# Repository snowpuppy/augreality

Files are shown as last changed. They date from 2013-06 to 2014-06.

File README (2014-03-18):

Aug Reality Cornell Cup Project ==
==================================

INTRODUCTION =
==============
This project aims to build an augmented reality simulator device
using a headset and the Intel DE2-i150 development board for the Cornell Cup
Competition. The headset is a custom design which has 3d graphics,
head tracking, gps positioning, and a wide field of view.
This is phase2 of the project. Documentation for phase1 and phase2 can be found
in our doc/ folder. The headset src/ folder is subdivided into all of the software
modules for this project.

DIRECTORY STRUCTURE =
=====================

## headset
##########

$$ headset/src
    This directory contains all source code for the Headset.

$$ headset/test
    This directory contains all test code for the headset (usually proof of concept or simulation code.)

$$ headset/doc
    This directory contains specific documentation related to the headset.

## doc
######
  This directory contains all general documenation for the top level design.

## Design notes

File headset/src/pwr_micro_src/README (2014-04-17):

This project contains the Cornell Cup headset power PCB code. It uses the STM32L100 series
microcontroller to establish an ultra-low-power method of correcting and reporting fuel gauge
data to the Intel Atom board.

You will need to install the STM32 ST-Link utility to enable "make upload" to autonomously
program the board through an ST-LINK dongle and SWD. Create a file named "stlink.mk" with the
only line being:

STLINK=C:/Program\ Files\ (x86)/STMicroelectronics/ST-LINK\ Utility

changed to match where the utility was actually installed on the local computer. Alternatively,
the ST-LINK GUI can be used instead, but note that the binary is only loaded when re-selected!

The "libSTMCore.a" is the STM32L Standard Peripherals Library pre-compiled for this chip
(STM32L1XX_MD), while "libSTMUSB.a" is the STM32 USB CDC-ACM example pre-compiled for this chip.

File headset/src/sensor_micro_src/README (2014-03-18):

This project contains the Cornell Cup headset sensor PCB code. It is a derivative of the Senior
Design micro_src code, with the XBee and fuel gauge completely removed.

You will need to have dfu-util 0.5 or later (http://dfu-util.gnumonks.org/releases/) installed
on your PATH (put it in the yagarto bin directory to make sure).

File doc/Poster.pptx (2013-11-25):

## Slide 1

ECE 477 Digital Systems Senior Design Project - Fall 2013

Team 5 – Augmented Reality Simulator

Project Overview:
- Players don the headset to experience an immersive multiplayer augmented reality Pacman-like game
- The semi-transparent display integrates game objects with the real world
- Wireless multiplayer is facilitated by a central control unit
- Gameplay is based on geospatial data from GPS and head orientation from an IMU

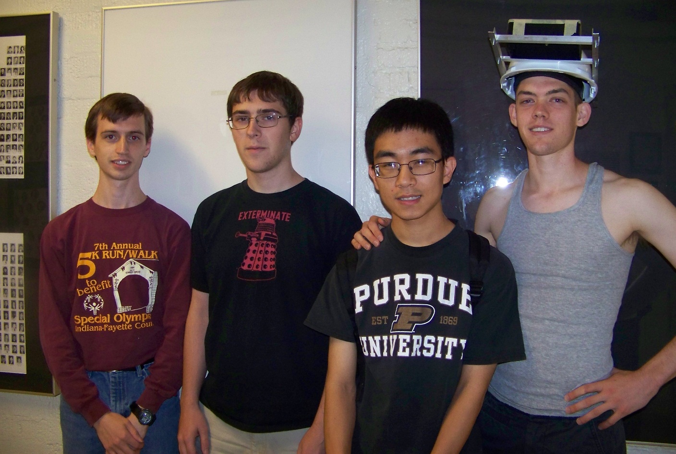
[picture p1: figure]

Team Members: Thor Smith, Steven Ellis,
Stephen Carlson, Alec Stephen Green

Packaging
- Semi-transparent display using an acrylic sheet with reflective film
- Fresnel lens increases field of view and focusing distance
- Aluminum and plastic construction allows for a lightweight yet rigid frame

PCB Layout
- Multiple power supplies reduce noise coupling for better sensor performance
- Size and form factor designed to fit with Raspberry PI motherboard
- Uses STM32F4 microcontroller with FPU.
- Battery sensing and charging, GPS, wireless radio, and 9-degree of freedom inertial measurement

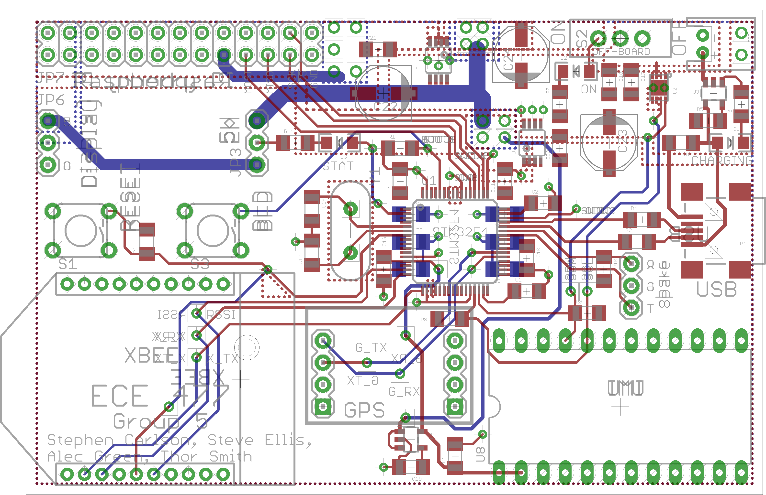
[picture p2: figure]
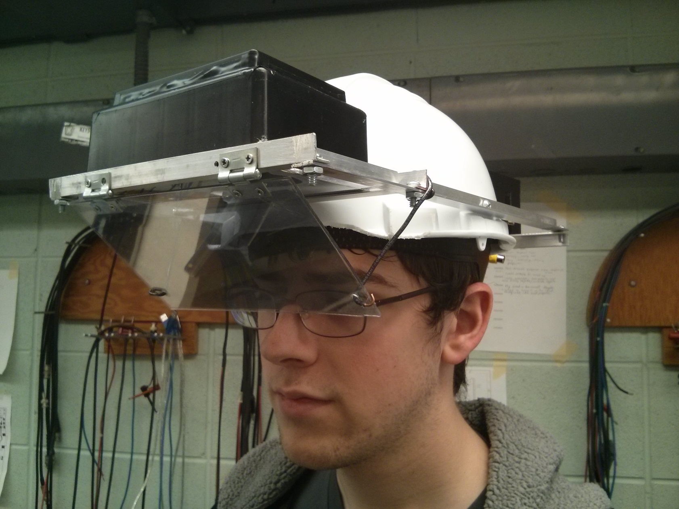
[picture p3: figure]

Digijock(ette)-Strength Digital System DesignTM
Transforming Ideas Into Reality

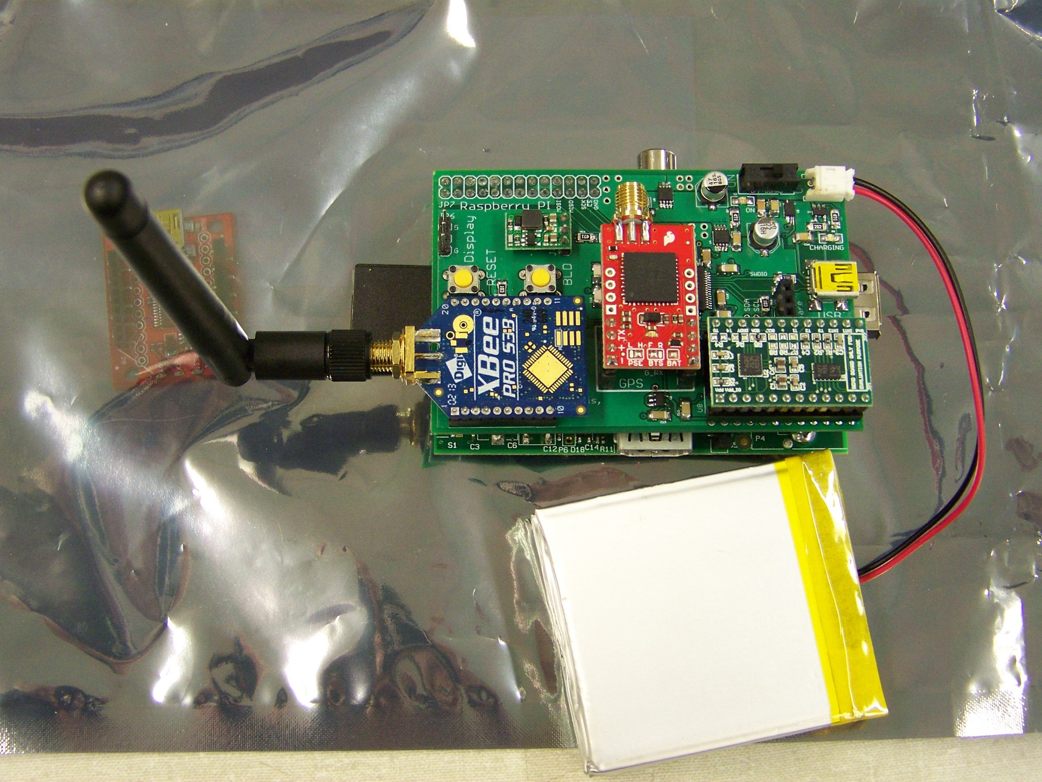
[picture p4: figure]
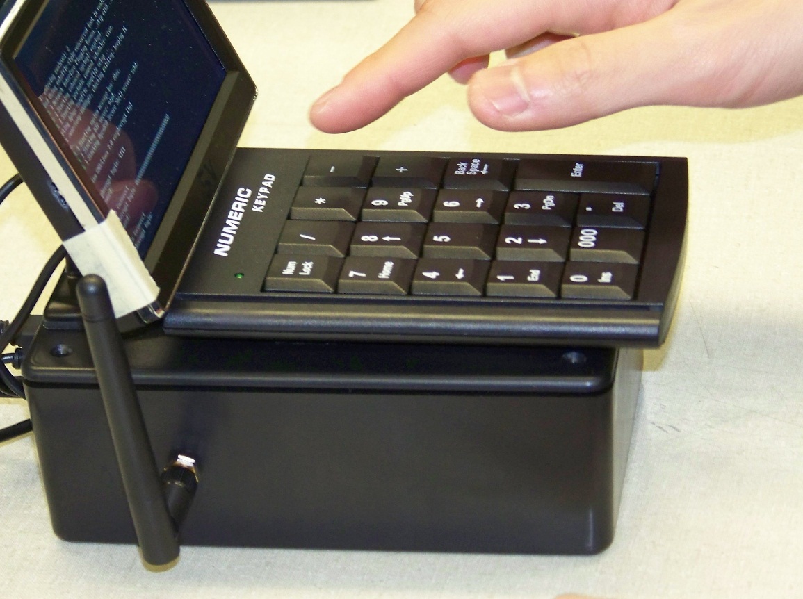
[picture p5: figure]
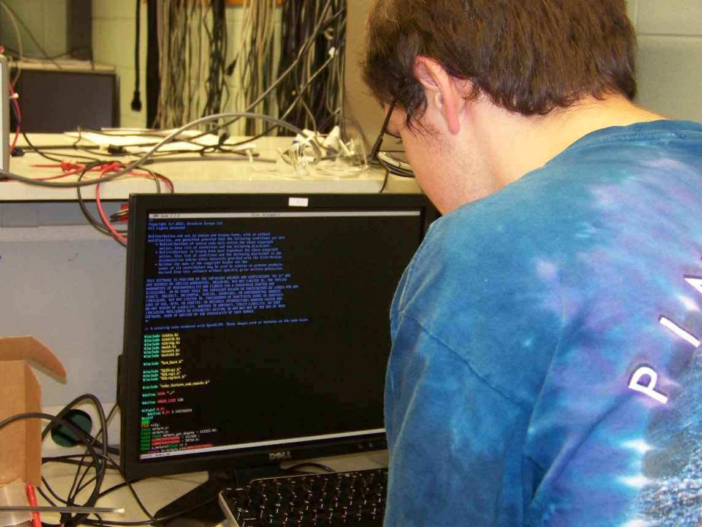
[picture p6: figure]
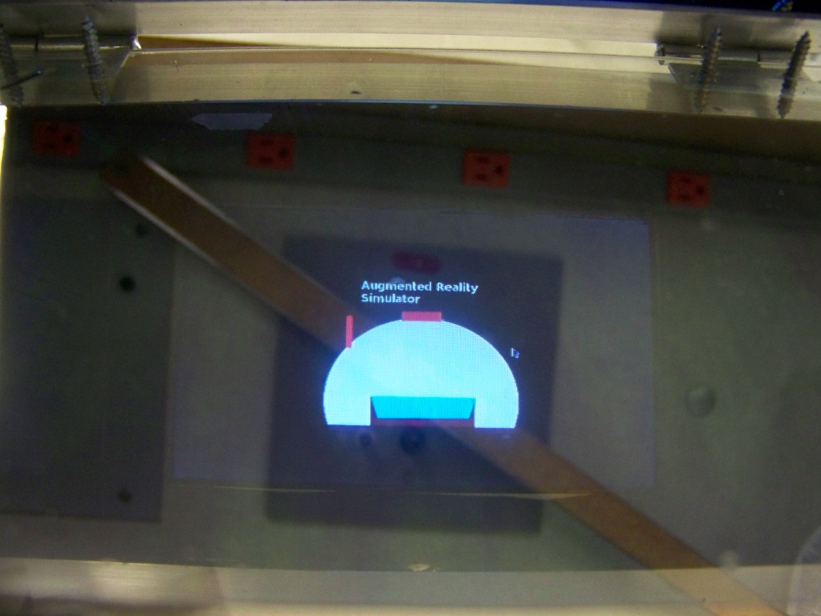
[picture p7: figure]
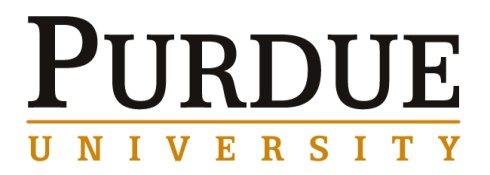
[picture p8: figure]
PU_signature_jpg_print

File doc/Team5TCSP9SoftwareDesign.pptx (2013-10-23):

## Software Design Team 5 Fall 2012

Stephen Carlson
Stephen Ellis
Alec Green
Thor Smith

## Abstract

- We propose an augmented reality simulator
  - Allows at least one user to play an electronic game in a mobile, outdoor environment
  - Intended for gaming and other simulations that require an augmented environment.
- Contains two primary parts: a headset and a central control unit (CCU)
  - The headset is worn by the user and overlays images of game objects on the user’s view of the environment
  - The CCU remains stationary and communicates information to the headset about simulation logic.

## Block Diagram

- Figure 1: The block diagram indicates two functional groups that communicate through the Xbee wireless devices.
- The CCU will perform simulation logic
- The headset will perform graphics rendering and sensor data acquisition.

## Project Specific Success Criteria

1. An ability to render graphics based on the orientation of the user’s head.
2. An ability to render graphics based on the user’s current geospatial location.
3. An ability to monitor and display the battery power level of the headset to the user.
4. An ability to monitor and display the status and quality of the wireless connection to the central control unit.
5. An ability to load headset graphics for a new simulation without re-flashing software on the headset’s microcontroller.

## Software Choice: state Machine

- Needs to flow between states, so a command or “flag” driven approach was selected.
- Data does not need to arrive “as soon as possible”, but needs to be sent on a regular interval. A timer interrupt will determine when IMU, Battery, and GPS data is sent out.
- Updates from CCU need to be processed ASAP for good rendering. Thus a wireless IRQ will trigger the main module to process packets.

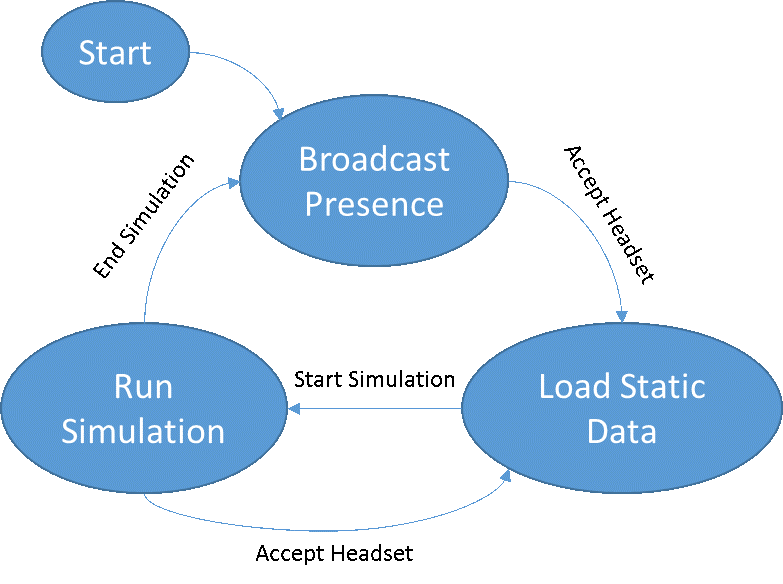
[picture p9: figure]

## Software Modules

- The GPS, IMU, Xbee, and Battery IRQs provides the control logic with a fresh supply of data.
- The Control Logic wakes on a timer interrupt and routes data to either the GPU or the CCU.

GPS IRQ
Convert to Decimeters
on x,y

IMU IRQ
Convert to pitch, yaw, roll

Control Logic
* Send IMU/GPS over network to CCU/GPU
* Make Decisions based on packets from CCU

XBee IRQ
Send/Queue packets.
Connectivity

Battery IRQ
Monitor Battery Life

## Main Program Flow

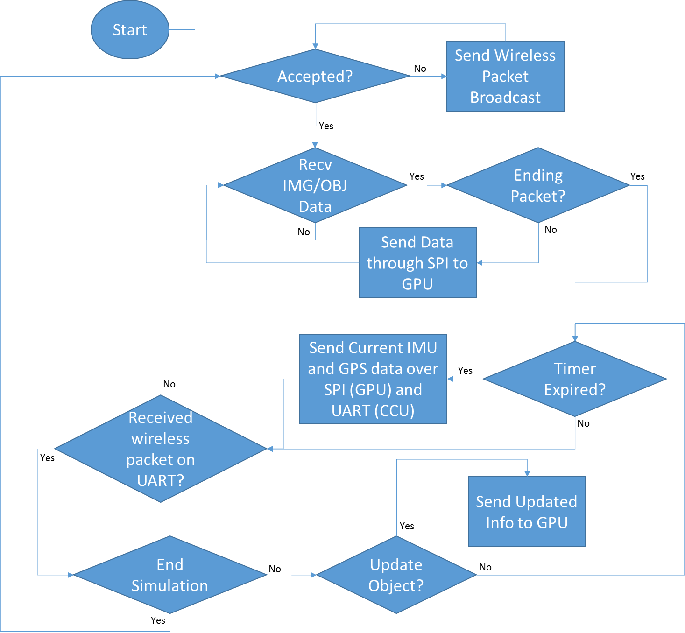
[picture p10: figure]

## Software Design Considerations

- Integrated Peripherals used:
  - Floating Point Unit (FPU)
  - NVIC (Nested Vectored Interrupt Controller)
  - SysTick timer (STK)
- External Interfaces Used
  - I2C
    - 400 KHZ (fast mode)
  - SPI
    - Slave Mode (clocked by raspberry pi GPU)
  - UART * 2
    - 115200 baud for XBee
    - 38400 baud for GPS

## Memory Mapping

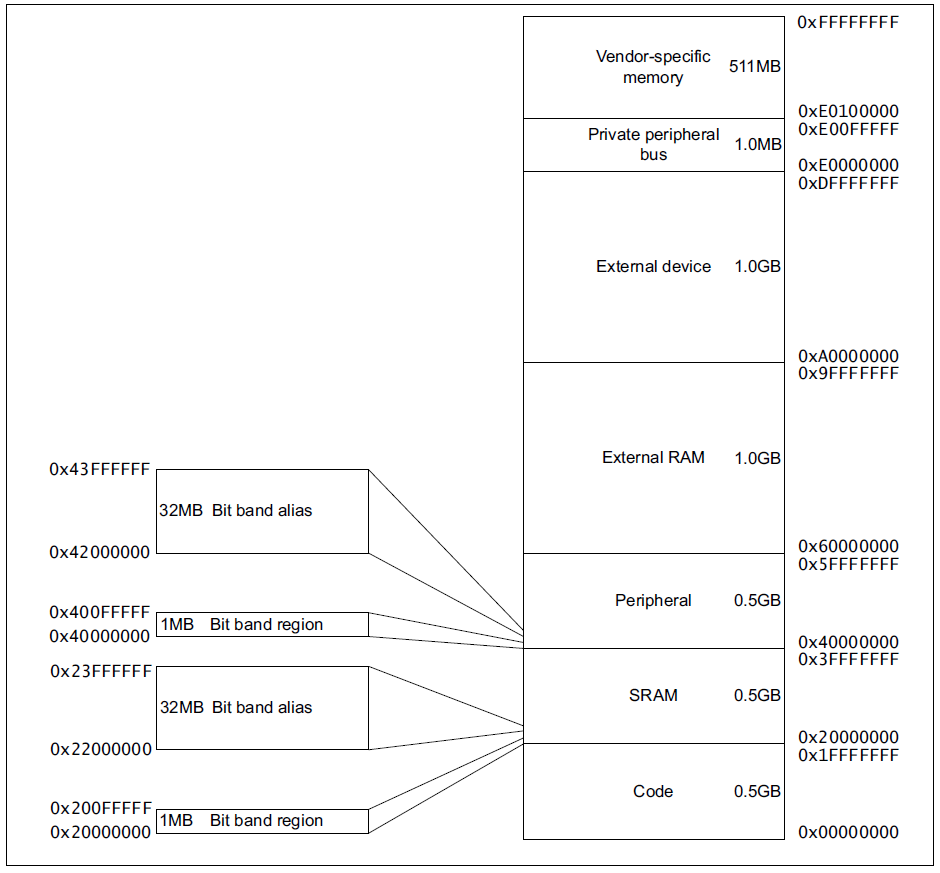
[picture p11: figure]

Figure 1: Taken from STM32F3xxx and STM32F4xxx Cortex-M4 programming manual
Section 2.2 Memory Model

- SRAM mapped from memory addresses 0x20000000 to 0x20020000; total of 128KB of SRAM.
- Stack is descending and positioned at 0x20020000.
- Global Variables will start at 0x20000000.
- No Heap Currently.
- Code will go in flash 0x08000000

## Central Control Unit Software

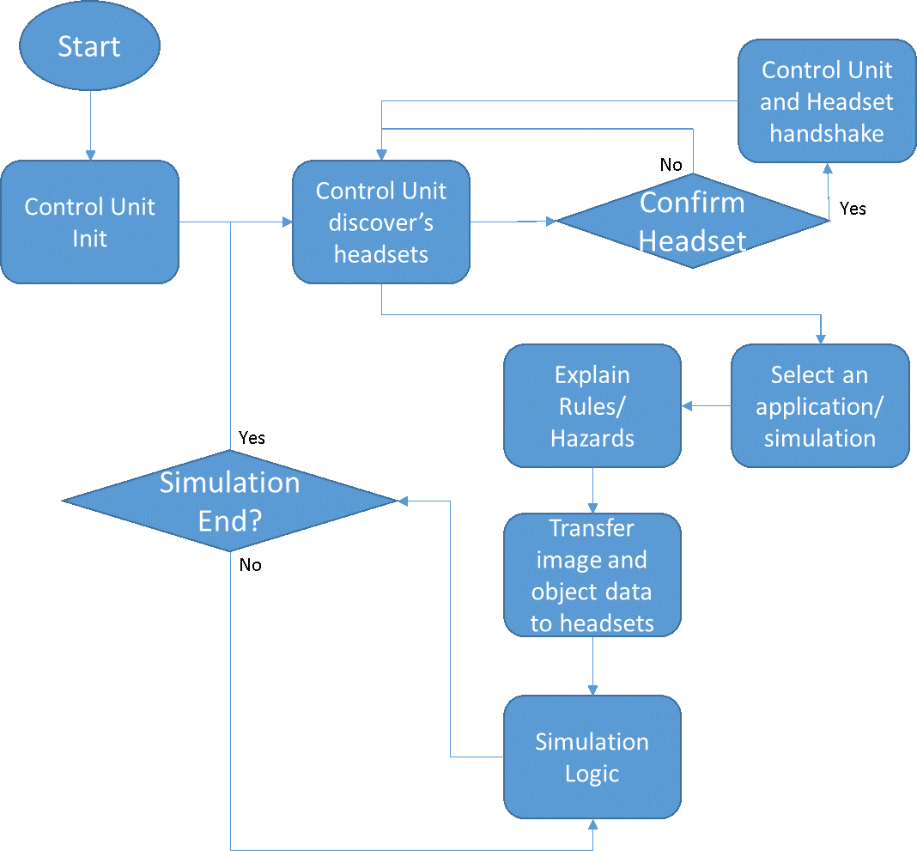
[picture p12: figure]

## Debugging

- Current Debugging consists of:
  - Printing messages through the serial port. A library of print functions has been implemented for this purpose.
  - Working on Breakpoints and single-stepping.
  - LEDs lighting up to indicate data flow from sensors.

## Software sources

- Software Libraries for I2C, UART, and other routines from the manufacturer are currently being used.
- Python Tkinter will be used on the Central Control Unit for the user interface.
- OpenGL is being used on the graphics unit for rendering.

## Questions / Discussion

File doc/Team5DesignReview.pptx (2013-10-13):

## ECE 477 Design Review Team 5 Fall 2012

Stephen Carlson
Stephen Ellis
Alec Green
Thor Smith


Thor
Smith

Steven
Ellis

Stephen
Carlson

Alec
Green

## Outline

- Project overview
- Project-specific success criteria
- Block diagram
- Component selection rationale
- Packaging design
- Schematic and theory of operation
- PCB layout
- Software design/development status
- Project completion timeline
- Questions / discussion

## Project Overview

- We propose an augmented reality simulator
  - Allows at least one user to play an electronic game in a mobile, outdoor environment
  - Intended for gaming and other simulations that require an augmented environment
- Contains two primary parts: a headset and a central control unit (CCU)
  - The headset is worn by the user and overlays images of game objects on the user’s view of the environment
  - The CCU remains stationary and communicates information to the headset about simulation logic.

## Project Specific Success Criteria

1. An ability to render graphics based on the orientation of the user’s head.
2. An ability to render graphics based on the user’s current geospatial location.
3. An ability to monitor and display the battery power level of the headset to the user.
4. An ability to monitor and display the status and quality of the wireless connection to the central control unit.
5. An ability to load headset graphics for a new simulation without re-flashing software on the headset’s microcontroller.

## Block Diagram

- Figure 1: The block diagram indicates two functional groups that communicate through the Xbee wireless devices.
- The CCU will perform simulation logic
- The headset will perform graphics rendering and sensor data acquisition.

## Component Selection Rationale

- Headset
  - Micro
    - GPS and IMU interfacing
    - Wireless communication
    - Battery monitor interfacing
  - Motherboard
    - Render graphics
- Central control unit motherboard
  - Wireless communication
  - Data storage
  - Game logic

## Microcontroller Constraints

- Must be capable of low latency sensor processing
  - High speed for floating point math
- Required external peripherals
  - 2 UART (GPS, Wireless module)
  - 1 SPI (Display/Motherboard connector)
  - 1 I2C (Power Monitor, IMU)
  - At least 10 additional GPIO pins
- Prefer 3.3V supply and 3.3V I/O

## Microcontroller Choices

- STM32F405RGT6
  - ARM-Cortex M4F
  - 168 MHz with FPU
  - 192 KB RAM
  - 64 LQFP 51 I/O
  - $11 single quantity
- Selected because
  - FPU (1 cycle multiply!)
  - ART Accelerator (instruction cache)

- PIC32MX695F512H
  - MIPS
  - 80 MHz
  - 128 KB RAM
  - 64 TQFP 53 I/O
  - $10 single quantity
- Rejected because
  - Lower IPC
  - Slower clock

## Motherboard Constraints (CCU)

- Uses
  - Game logic
  - Store game objects to load onto headsets
- Required peripherals
  - USB for user input device
  - 1 UART (or USB UART) for Wireless module
  - Display output (HDMI, Composite, VGA)

## Motherboard constraints (headset)

- Main Constraints
  - 3D graphics rendering needs fast GPU
- Required peripherals
  - 1 SPI for microcontroller connection
  - Display output (HDMI, Composite, VGA)
- Other constraints
  - Power usage should be suitable for batteries

## Motherboard Choices

- Raspberry PI ModelA
  - Low-cost ($40 total)
  - 700 MHz ARM11
  - Low-power (2W)
- Selected because
  - Power consumption
  - Community support
  - Cost

- BeagleBone Black
  - $45
  - 1GHz Cortex-A8
  - Low-power (2.5W)
- Rejected because
  - Slower GPU
  - No composite video

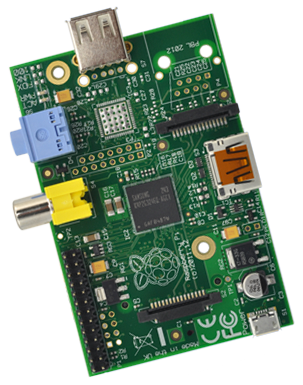
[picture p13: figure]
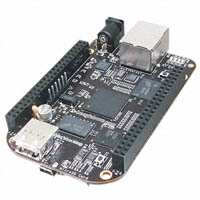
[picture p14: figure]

## OTHER CHOICES

- GPS
  - Venus638LPx
    - High accuracy (claimed 2.5m) and refresh rate (20Hz)
- 9DOF
  - LSM303DLHC
    - Low cost but still high accuracy
    - More expensive unit has on-chip filtering but requires NDA
- Wireless
  - XBee Pro 900HP
    - Long range (claimed 6 miles, tested ~300m)

## Packaging Design

- Requirements
  - Relatively light weight, balanced
  - Display focusing and field of view
- Materials
  - Hat/helmet
  - Enclosures for display, PCB/battery stack
  - Angle aluminum for mounting frame
  - Acrylic or polycarbonate sheet
  - Reflective film
  - Lenses

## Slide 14

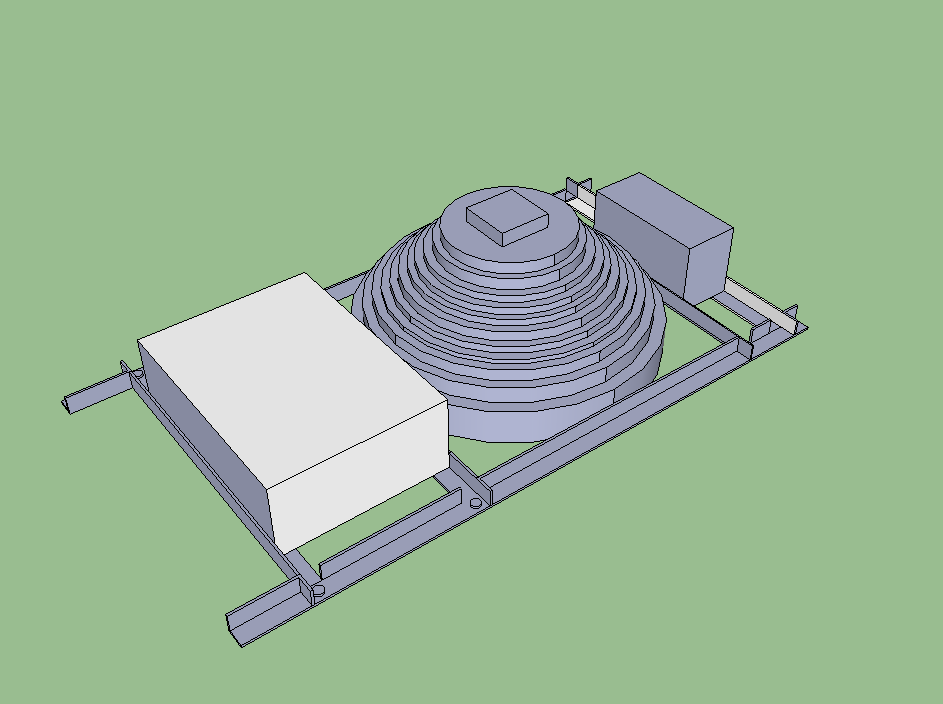
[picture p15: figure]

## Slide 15

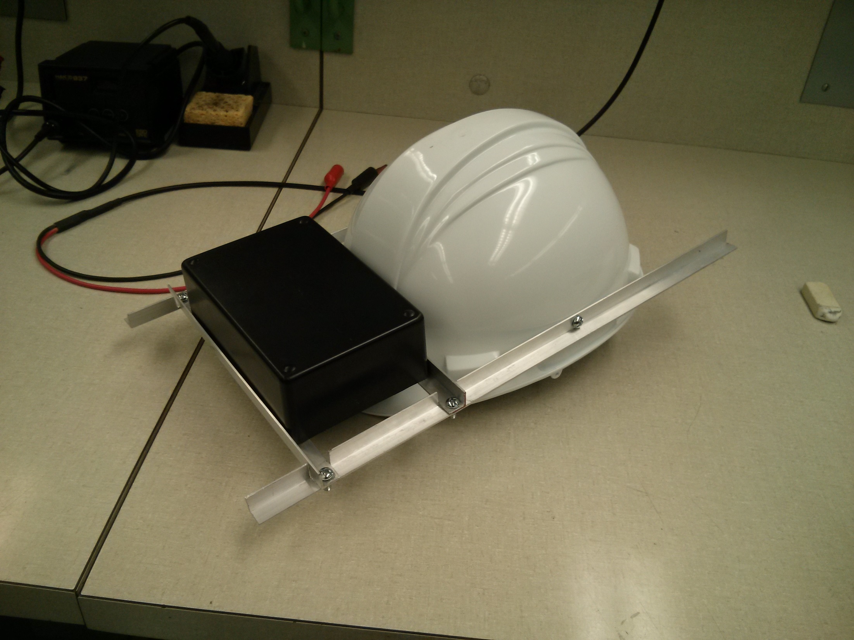
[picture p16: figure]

## Schematic & Theory of Operation

- Accelerometer + Magnetometer (compass) + Gyro determine user orientation
- GPS (+ accelerometer) determine geospatial position
- All sensor data sent to uC for processing
- 3.3V: common voltage among all components
- 168MHz: maximum, performance when processing sensor data, power consumption negligible when compared to other devices

## Schematic (1/2)

- Ports A and B to avoid crystal-facing Port C
- USART: GPS
- USART: Xbee
- I2C: Accelerometer + Magnetometer + Gyro
- I2C: Battery fuel gauge
- SPI: Raspberry Pi
- 168MHz frequency: maximum, sensor processing performance, negligible power consumption

## Schematic (2/2)

- Power
  - 3.3V .5A Vcore: Raspberry Pi
  - 3.3V .5A Vmcu: uC + Xbee + GPS
  - 3.3V .05A Vadc: IMU (low noise)
- Ground: ground pour
- Bypass caps: manufacturer recommendations
  - 1x 1uF decoupling on Vbatt
  - 2x 2.2uF bypass for uC core supply internal regulator
  - 10x .1uF decoupling power pins
  - 2x 22uF bulk for regulators

## Schematic (Batt charge + Fuel Gauge)

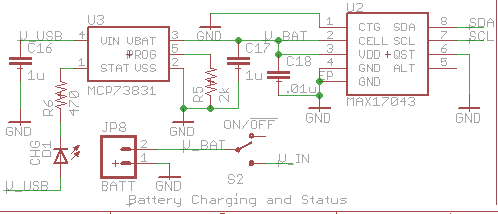
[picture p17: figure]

## Schematic (Power Supplies)

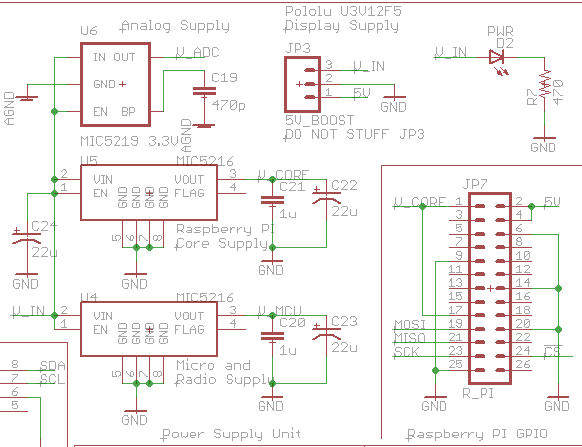
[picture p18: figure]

## Schematic (Sensors)

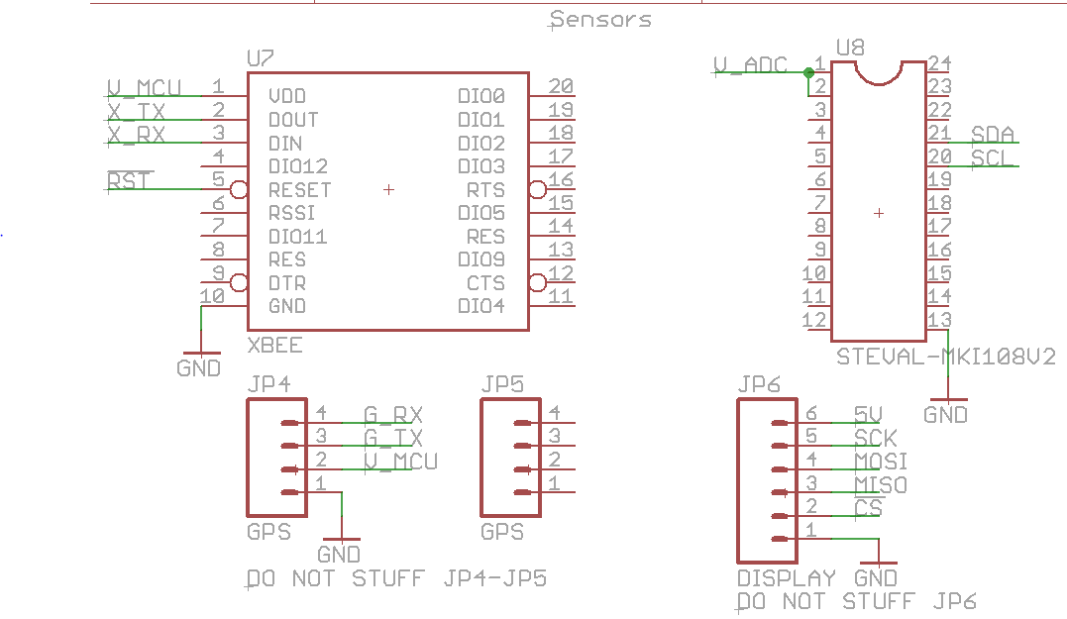
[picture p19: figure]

## Schematic (uC)

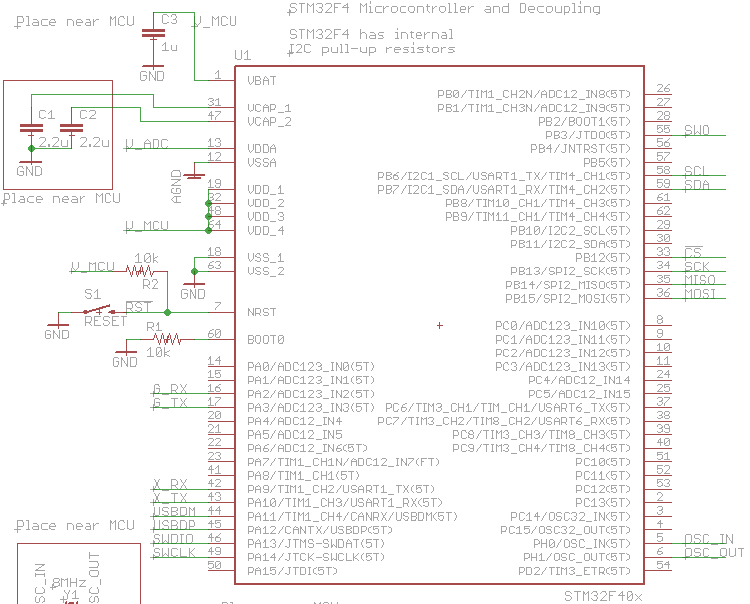
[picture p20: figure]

## PCB Layout – General

- Advanced Circuits/4PCB specs
  - 5mil trace/5mil space
  - 10mil minimum hole size and 5mil tolerance
- For manufacturability
  - 10mil trace/8mil space
  - 15mil minimum hole size
- No acute angles
- Two layers

Team 05: Augmented Reality

## PCB Layout – MCU

- Oscillator and USB lines match impedance
  - Trace lengths must match
  - No right angles
- Decoupling, oscillator must be adjacent
  - Place some capacitors underneath chip
- Pin locations determine routing success

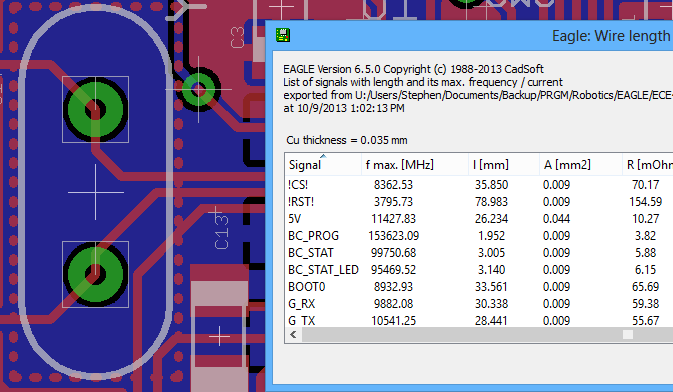
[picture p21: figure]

0.2mm = about 7 mil difference
(less than one trace width)

## PCB Layout – Power

- Total current could be up to 2A
  - Use low resistance copper pours
  - Multiple large vias for transfer between layers
  - Power from multiple directions (“islands”)
  - Bulk capacitors near regulator, bypass near loads

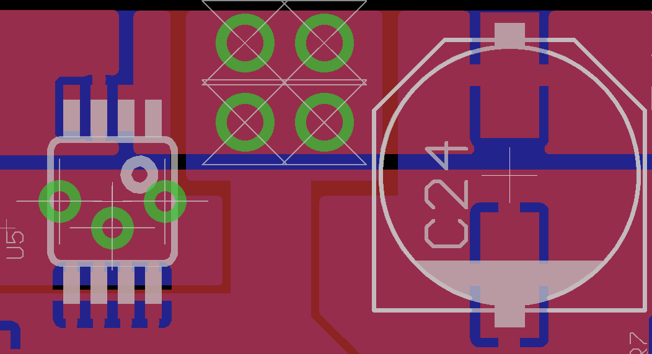
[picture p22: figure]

## PCB Layout – Other

- Connectors
  - Raspberry PI connector must match motherboard
  - Other connectors must be on edges
- Route I²C, UART, SPI lines together
  - Test points
- Debug LEDs, spare I/O headers
- Place V_ADC regulator near IMU
  - Reduce interference pickup
  - Place XBee far away

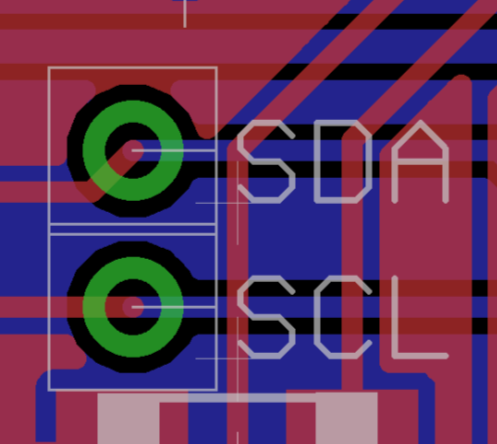
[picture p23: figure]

## Pcb Layout, Full Board

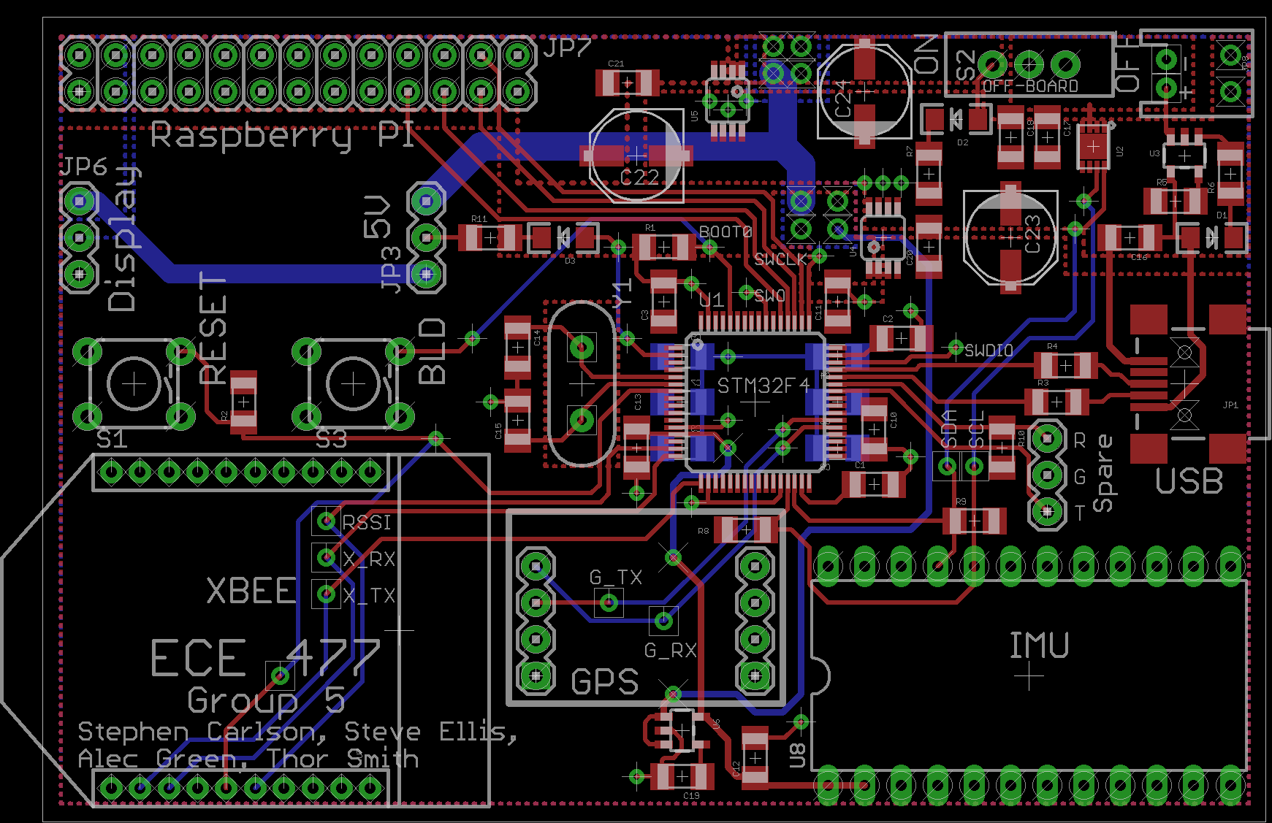
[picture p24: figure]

## Pcb Layout, Power Supply

Power Switch

JST Connector


Core Supply

Fuel Gauge

Power LED

Charger

MCU Supply

Charging LED


## Pcb Layout, Microcontroller


SPI to
Raspberry PI

STM32F4
Microcontroller

8MHz
Oscillator

To USB
(programming)

To Reset Button

UART to XBee

UART to GPS

I²C to IMU


## Pcb Layout, Peripherals


XBee Pro 900

Venus GPS Breakout

ST 9-DOF IMU Breakout

V_ADC
Supply


## Software Design/Development Status

- Preliminary drivers to extract GPS and IMU data has been completed. Next steps to push data to GPU and CCU.
- The GPU code will be written in OpenGL.
- The CCU will provide a user interface and process game logic. C++ for game logic, python for User Interface.
- XBee packets flows defined.

GPS Thread
Convert to Decimeters
on x,y

IMU Thread
Convert to pitch, yaw, roll

Control Logic
* Send IMU/GPS over network to CCU/GPU
* Make Decisions based on packets from CCU

XBee Driver
Send/Queue packets.
Connectivity

Battery Thread
Monitor Battery Life

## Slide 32

Team 5 Project Completion Timeline
| PCB / Hw | GPU | Data | CCU | Packaging
Week 8 | One to One parts check. PCB Verification | | Data formats Finalized. | | Finish Building Headset.
Week 9 | Parts Testing | Prelim Animation | Sensor processing complete. | GUI Software complete
Week 10 | Solder Parts to Board Test Power Supply | Animation w/ IMU | Implement network flow.
Week 11 | Test Micro and other components | Animation w/ GPS | Implement Battery Sensing. | Library for simulations | Evaluation of Headset design
Week 12 | | Integration w/ Micro
Week 13 | | | | Implement PacMan | Revision of Headset design.
Week 14
Week 15

## Questions / Discussion

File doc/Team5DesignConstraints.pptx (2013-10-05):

## Design Constraint Analysis

Team 05 Augmented Reality Project
TCSP #02
Stephen Carlson, Steven Ellis, Alec Stephen Green, Thor Smith

## Abstract

- We propose an augmented reality simulator
  - Allows at least one user to play an electronic game in a mobile, outdoor environment
  - Intended for gaming and other simulations that require an augmented environment
- Contains two primary parts: a headset and a central control unit (CCU)
  - The headset is worn by the user and overlays images of game objects on the user’s view of the environment
  - The CCU remains stationary and communicates information to the headset about simulation logic.

Team 05: Augmented Reality

## Functional Block Diagram

- Exploring possibility of using another Raspberry PI Model A for rendering

## PSSC Review

- An ability to render graphics based on the orientation of the user’s head.
- An ability to render graphics based on the user’s current geospatial location.
- An ability to monitor and display the battery power level of the headset to the user.
- An ability to monitor and display the status and quality of the wireless connection to the central control unit.
- An ability to load headset graphics for a new simulation without re-flashing software on the headset’s microcontroller.

## Controller Requirements

- Headset
  - Render graphics (PSSC #1, 2)
  - GPS (#2) and IMU (#1) interfacing
  - Wireless communication (#4)
  - Battery monitor (#3) interfacing
- Central control unit
  - Wireless communication (#4)
  - Data storage (#5)

## Microcontroller

- Must be capable of rendering graphics
  - 128 KB or more of RAM
  - High speed for floating point math
- Required external peripherals
  - 2 UART (GPS, Wireless module)
  - 1 SPI (Display/Motherboard connector)
  - 1 I2C (Power Monitor, IMU)
  - At least 10 additional GPIO pins
- Prefer 3.3V supply and 3.3V I/O

## Microcontroller

- STM32F405RGT6
  - ARM-Cortex M4F
  - 168 MHz with FPU
  - 192 KB RAM
  - 64 LQFP 51 I/O
  - $11 single quantity
- Selected because
  - FPU (1 cycle multiply!)
  - Large RAM
  - Independent DMA/ART Accelerator

- PIC32MX695F512H
  - PIC 32-bit
  - 80 MHz
  - 128 KB RAM
  - 64 TQFP 53 I/O
  - $10 single quantity
- Rejected because
  - Inefficient architecture
  - Slower clock

## Motherboard

- Run central control unit (CCU)
  - Game logic
  - Memory buffer storage for game objects
  - Potential future use for complex rendering
    - Power usage should be suitable for batteries
- Required peripherals
  - USB for user input device
  - 1 UART (or USB UART) for Wireless module
  - Display output (HDMI, Composite, VGA)

## Motherboard/Graphics

- Raspberry PI Model A
  - Low-cost ($40 total)
  - 700 MHz ARMv6T
  - Low-power (2W)
- Selected because
  - Power consumption
  - Community support
  - Cost

- Intel Atom/FPGA Board
  - Cornell Cup
  - Intel Atom processor
  - On-board FPGA
- Rejected because
  - Learning curve
  - “Over kill”


## Questions

Photo credits:
http://www.sparkfun.com/
http://www.digikey.com/

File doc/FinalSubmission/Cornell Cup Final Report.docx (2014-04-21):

# Augmented Reality Simulator

# Purdue University

# Cornell Cup 2014

Stephen Carlson

Steven Ellis

Thor Smith

Table of Contents

# 1 Abstract

# 2 Challenge Definition


Wearable computing is quickly becoming the next step of embedded systems evolution. Devices like Google Glass [1] as shown in Figure 1 and the Samsung Galaxy Gear aim to make computing part of everyday life. However, existing wearable devices are designed to serve as omnipresent gateways to the Internet and are not intended to work together in a collaborative real-time application with multiple users. As an alternative, this team proposes an immersive augmented reality platform which offers new multi-user applications for wearable computing. Such a device would have broad applications in education, defense, group recreation, and artistic performances where small teams of users can work together in the same augmented reality environment.

Figure 1: Google Glass, an existing wearable computing product

Portability and ergonomic challenges will primarily influence project development, as competing devices are often chosen for small size and low power consumption. A good solution to this challenge must have long battery life and a low mass to promote long-term wearable usage patterns. The virtual environment will not replace the real environment, so an ideal solution must also allow the user to perceive the real world with minimal eye strain or peripheral vision obstruction. Since augmented reality systems aim to overlay objects onto real-world positions, a successful device must be able to determine the position and orientation of the user in three-dimensional space within at least a few meters of precision.

This device must be capable of wireless communication with other augmented reality devices in close proximity to enable multi-user applications, where more than one user can share the same virtual environment. From a user perspective, ergonomics are also a major concern for wearable devices; the challenge is incorporating the desired functionality while not creating an unnecessarily heavy or bulky device. A successful device must also be durable enough to withstand regular use while not requiring technically experienced users for support.

While the software to support an augmented reality application will be dependent on the eventual usage case, the operating system which configures the headsets and handles common functionality like wireless networking and sensor processing must be easy to set up and use. For a non-technical user to understand the device, the application must start automatically on power up and walk the user through any initial setup process such as wireless pairing or sensor calibration. Custom applications which are written for this device should maintain a consistent state across any and all participating users and update the displayed virtual world at timely intervals.

# 3 Project Entry Solution

## 3.1 Customer Value Proposition

End customers using this device will be able to experience a novel form of playing games that has not yet been realized by any system in the past. The user will be able to physically walk through a game and interact by colliding with virtual objects.

## 3.2 Changes from Original Proposal

There have not been any significant changes from our original proposal.

## 3.3 Key Technical Elements

There are four key technical elements to this presentation. The first element is the sensor printed circuit board (PCB) which contains the inertial measurement unit and the global positioning system sensors. This is mounted in the back of the headset and it is used to track the position of the player and the orientation of the player’s head. This is shown as the GPS Receiver and IMU in Figure 2 below.

The second element is the headset packaging itself, labelled Headset and Display in Figure 2. A hard hat provides an adjustable fit to a variety of different heads and the mounting points for the sensor board and the LCD screen. The LCD screen is mounted in a black box at the front of the helmet and the screen is reflected off of a reflective film on a slanted piece of acrylic. Aluminum rods are used to make the front and rear mountings possible.

The third element is the power supply board that was built to accompany the DE2i-150 and make it mobile. This component is indicated by the Power Supply, Fuel Gauge, and Battery in Figure 2. The power supply board provides the means for tracking the battery status over USB and powering the DE2i-150, the LCD, and the sensor board. Finally, the fourth element is the key software modules built to perform the tasks of networking the helmets together, harvesting sensor data, displaying the user interface, rendering the 3D graphics, and running a simulation. This is indicated by the Augmented Reality Application and Viewport Algorithm.

Figure 2: Block diagram of the Augmented Reality Simulator system

# 4 Product Performance Evaluation

## 4.1 Performance Metrics

The experience of the end user will determine the satisfactory completion of the challenge, so frequent testing will be performed at multiple stages of the design to incorporate feedback from non-technical users. Project success will primarily be measured by the criteria shown in Table 1. Table 2 shows performance metrics specifically targeted towards software.

Because of the wearable nature of this product, one important metric is its suitability for extended usage periods. This requires both a long battery life to enable the extended usage, and hardware that avoids causing discomfort to the user during extended usage. Because the intended application is gaming, the runtime target selected was 3 hours, which is expected to be near the upper limit of how long a typical person would want to play a game continuously. While not wearable, the primary competitors in the portable gaming market are the Nintendo 3DS and PlayStation Vita, both of which have approximately 3 hours of battery life in the worst case. [2] [3] The phase one headset achieved almost exactly 3 hours of runtime, and the phase 2 headset lasts for TODO

The other major consideration during extended usage is the comfort of wearing the headset and backpack combination. The most easily measurable metric for long term usage comfort is the weight of the device, which can be separated into the headset and backpack. The headset weight is the most crucial, because all weight there places a load on the neck whereas a backpack can be much heavier before being burdensome to the user. The targets selected based on some informal testing were 1kg for the headset and 3kg for the backpack. In terms of the wearable computing competition, the Oculus Rift Dev Kit 2 weighs 440g (reported as 0.97lb) [4].

Aside from user comfort, the quality of the displayed image is one of the most important aspects of a wearable display. One measure of this is the field of view, or how large the display appears to the user. This is measured in degrees, with human vision being approximately 180 degrees. The calculation for this is fairly simple, as shown in the following equation:

Display Field of View=2*tan^(-1) ((distance from eye/2))/(size of display)

However, the optics employed in all of these systems complicate matters slightly by making the size and distance of the display appear to be different than they actually are. Oculus states the field of view of their Development Kit 2 as 100 degrees [4], whereas Google does not directly state field of view for Glass but provides enough information to calculate it [5]. The descriptions lists the display for Glass as ‘equivalent of a 25 inch high definition screen from eight feet away’, which when plugged into the above equation gives approximately 15 degrees.

The optics system of the augmented reality headset is fairly simple with only two elements, making this calculation straightforward. First, there is the distance from the eye to the reflector, then the distance from the reflector to the magnifying lens, and finally the distance from the magnifying lens to the display. The reflector does nothing but turn the light at a 90 degree angle, so for this calculation the first two parts of the optical path can be considered together with the sum of the distances. The magnifying lens creates an image which appears to be both larger and farther away, so the distance to the display appears to be the sum of the distance from the user’s eye to the lens and the distance from the lens to the projected image of the display. The display also appears larger, increasing the field of view. The field of view calculation is shown below, in a step by step fashion.

Variable name | Meaning
f | Focal length of lens
o | Distance from lens to object
i | Distance from lens to image
r1 | Distance from eye to reflector
r2 | Distance from reflector to lens
d | Distance from eye to image
s | Diagonal display size
h | Diagonal display image size

f=12cm (specified by manufacturer)

i= 1/(1/f-1/o)=8.5cm

r1=5cm (measured)

r2=5cm (measured)

d=r1+r2+i=18.5cm

s=12.7cm (specified by manufacturer)

h=s*i/o=12.7*1.7=22cm

FoV=2*tan^(-1) (h/2)/d=61 degrees

As can be seen, the 61 degree field of view of the augmented reality headset lays roughly half way in between the very narrow Google Glass, which is intended as a HUD in the user’s peripheral vision, and the Oculus Rift, which is intended as a fully immersive virtual reality experience.

Because the intended application is a multiuser simulation using wireless networking, the range of this network system is an important performance metric. The usable range is one of the major factors as to what types of simulations are feasible to run on the system. Currently, there are really no other wearable computing products available designed to network with each other to which the augmented reality headset can be compared. The Oculus Rift is meant to be tethered to a desktop PC, and Google Glass tethers to a smartphone to connect to the internet. The target set for this project was 80m for line of sight usage, as that seemed like a reasonably large playfield for simulations to use. The actual measured range before packet loss became significant was TODO

There are a variety of factors which impact the responsiveness of the image displayed to the user and how accurately virtual objects are mapped to real world objects. One is the image update rate, which needs to be high enough to appear as a smoothly moving image to the user. Movies have traditionally been shot at 24 frames per second, so 20 frames per second seemed like a reasonable minimum target. The actual frame rate of the simulation running on the headset varies from roughly 15-25 frames per second depending on exactly what is on the screen at the moment. The sensor data being used as inputs to the rendering is also crucial to the responsiveness of the simulation. The location sensing determines how well virtual objects line up with real world objects, so this should occur at both a high rate and with high accuracy. The rate target was set to be the same as the frame rate target, and the accuracy target at 2m. At this level of accuracy, discrepancies are very obvious but this is approximately the best performance achievable with current GPS technology without extremely expensive receivers. This was deemed an acceptable tradeoff for GPS being able to be used outside without any sort of external hardware requirements, which most other tracking technologies (such as camera based tracking) cannot achieve easily.

Table 1: Augmented reality system performance measures and satisfactory design metrics

Metric | Target | Description
Mass | Headset: 1 kg Backpack: 3 kg | Neither the headset nor the backpack can be too heavy to impede the performance of typical activities by the user.
Power | 3 hours runtime | Augmented reality applications run for long durations, so the device must operate long enough on battery power to be usable. The remaining battery capacity should be displayed to the user.
Location | Minimum 2 meter accuracy and precision | The accuracy of the rendered virtual world depends heavily on the accuracy and precision of the user’s geospatial position.
Wireless | 80 m range, line of sight | A unique feature of this device is the wireless coordination capability of multiple headsets in the same virtual environment. The current wireless signal strength should be reported to the user.
Comfort | No running speed or vision reduction | Ideally, the user would be able to perform actions without a noticeable burden on the user. It is difficult to quantitatively measure comfort, but the user should be able to orient their head, see the environment, and move from place to place as effectively as if the device was not worn.
Durability | Operate from 0 to 40 C indoors and outdoors in dry conditions | Most augmented reality applications involve users walking or running, which will subject the device to vibration and light impacts. In addition, sunlight, humidity, and dust are inherent concerns for a portable device.
Usability | End user can start up and use device without a technician | A user unfamiliar with the device technical details must be able to power on the device, perform start-up procedures such as wireless connection, and load the desired application.

Table 2: Augmented Reality Software Performance Metrics

Metric | Target | Description
3D Graphics | Minimum 5000 polygon count | The user will expect to see a good 3-D image. Phase 2 offers opportunities to increase graphical performance.
Graphics | Minimum 20 Hz update rate | We will need to render ghosts and the maze walls in real time according to the user’s geospatial location and their head orientation.
Collision Detection | Minimum 2 meter accuracy and precision | The ability of the software to detect collision detection will be affected by the accuracy of the GPS. The minimum required to be meaningful cannot exceed a couple of meters. This means ghosts could be 2 m² to account for accuracy of GPS.
Network User Position Update Rate | Minimum of 20Hz (50ms). | The position and orientation of each headset will need to be communicated wirelessly at least every 50ms to keep up with the GPS and provide meaningful feedback about collisions to each headset.
Network Graphic Position Update Rate | Minimum of 20Hz (50ms) | The position information about positions of ghosts and other virtual objects needs to be updated in a timely manner and should at least be as fast as the update rate of the player’s position.
User Interface Usability | End user can navigate the user interface intuitively. | A user unfamiliar with the operation of the software should be able to figure it out with minimal references to the user manual. For phase 1 this will be displayed from the control unit. In phase 2 the user interface will migrate to the headset’s display.

## 4.2 Failure Analysis

# 5 Technical Documentation

## 5.1 Component Selection Rationale

Innumerable decisions were involved when choosing parts for all project aspects, so the most important component selections for meeting project metrics are shown below.

### 5.1.1 Cost Requirements

An initial estimate of $300 per headset and the budget shown in section 5.2.3 was used to guide parts selection. Cost is secondary to other project metrics due to the dearth of comparable devices on the market; price was only used to differentiate otherwise similar design choices. For example, Google Glass [1], a product with higher quality compact optics, is currently priced at $1500, and several other augmented reality products such as ARQuake [6] and CastAR [7] have not left development. In addition, the development expenses incurred are likely to be very different than actual production costs.

### 5.1.2 Microcontroller

Processing power is the biggest concern for the headset microcontroller selection. Decoding and filtering the 9 degree of freedom inertial measurement unit (IMU) data into the user’s head orientation requires floating point math, and high-speed IMU filtering with low latency and timing jitter leads to better head tracking performance. Power consumption is secondary as other parts will dominate power use. The microcontroller must be able to handle each sensor connection as shown in Figure 2 and Table 3.

Table 3: Required on-chip microcontroller peripherals for headset

Device | Peripheral | Special Features | Minimum Speed | Pin Count
Motherboard | SPI | Master Mode, Chip Select | 800 KHz | 4
GPS | Serial | | 38.4 Kbaud | 2
Fuel Gauge, IMU | I²C | Open-Drain, Current Sink | 400 KHz | 2
Wireless | Serial | Full Duplex | 115.2 Kbaud | 2
Future Expansion | GPIO | Configurable Data Direction | N/A | 10
| | | Minimum Pins: | 20

Table 4 shows the microcontrollers which were considered, all of which met the constraints for on-chip peripherals and pin count.

Table 4: Decision matrix for headset microcontrollers

Part | I/O | RAM | Flash | Clock | DMA | Special Features | Cost
STM32F405RGT6 | 51 | 192K | 1M | 168MHz | 16 | Floating Point Unit | $11
PIC32MX695F512H | 53 | 128K | 512K | 80MHz | 8 | | $10
ATSAM4S16BA-AU | 47 | 128K | 1M | 120MHz | 22 | | $10

The STM32F405 microcontroller was chosen for Phase 1 due to the availability of a low cost $15 development board [8] and its very high performance, particularly with single cycle floating point operations. This chip also features extra RAM and processing power for future expansion. For Phase 2, this microcontroller was re-used, as it was available on hand and allowed reuse of the project code base from Phase 1.

### 5.1.3 Motherboard

The headset GPU motherboard must have a compatible SPI port to interface with the microcontroller over SPI as described above. It also must support a standard display output such as VGA, composite, or HDMI for rendering to a commercially available screen. A second available standard interface such as USB is also preferred for debugging and to allow future expansion to other user input devices for more advanced simulations.

As the graphics processing motherboard is the largest power consumer on the device, low power consumption is mandatory. Small size and light weight is also important for a portable device. By comparison, performance is much less of a concern. The motherboard should also feature a USB port and SPI interface for connection to the microcontroller.

Table 5: Decision matrix for motherboards

Part | Idle Power | RAM | USB | SPI | Clock | Cost (board)
Raspberry Pi Model A | 2 W | 256M | 1 | 1 | 700MHz | $25
BeagleBone Black | 2 W | 512M | 1 | 2 | 1GHz | $45
Intel® Atom™ Board | 12 W | 2G | 4 | 1 | 1.8GHz | $150

As shown in Table 5, the Raspberry Pi Model A was chosen in Phase 1 for its low power consumption, cost, and outstanding community support. Prolific examples can be found on the Internet for the Raspberry Pi, whereas the BeagleBone Black is new and difficult to acquire.

Phase 1 exposed the limitations of the Raspberry Pi Model A motherboard. Although its low power consumption led to long battery life, the graphics processing unit on board was extremely difficult to use. Tasks such as displaying text and loading graphical models were extremely slow, impeding refresh rate metrics.

With the contribution of two Intel® Atom™ Terasic DE2i-150 boards from the Cornell Cup sponsors, the motherboard criteria were revisited. Due to the simplicity of coding graphics on the standard OpenGL framework for the Intel® Atom™ board, the Atom™ motherboard was chosen for Phase 2, with the higher power consumption and mass accepted as a necessary cost.

### 5.1.4 Sensors

Due to advancements in MEMS technology, most inertial measurement units provide excellent noise performance and accuracy. Power consumption is not an issue as other parts will dominate power use. A breakout board must be available since most IMUs come in LGA packages that cannot be soldered by processes easily available to students.

Table 6: Decision matrix for 9-degree of freedom inertial measurement unit (IMU)

Part | Gyro | Accelerometer | Compass | Resolution | Board Cost
STEVAL-MKI108V2 | L3GD20 | LSM303DLHC | LSM303DLHC | 16/16/12 bits | $27
MPU-9150 | MPU-9150 | MPU-9150 | MPU-9150 | 16/16/13 bits | $50
SparkFun IMU | ITG3200 | ADXL345 | HMC5883L | 16/13/12 bits | $50

As seen in Table 6, the slightly increased resolution of the MPU-9150 is offset by its cost and lack of documentation, particularly for the use of its powerful internal filtering algorithms [9]. The cheaper STMicroelectronics part [10] was chosen instead for Phase 1 and Phase 2, as it offered no apparent disadvantages to the expensive SparkFun 9-DOF sensor stick [11].

Past senior design groups experienced problems with low resolution and slow updates from GPS. The real-time constraints of this project call for a fast and high-resolution receiver module. Power consumption is also a concern, as the GPS unit will always be tracking the user.

Table 7: Decision matrix for GPS receiver unit

Part | Resolution | Update Rate | Accuracy | Antenna | Power Use | Cost
Venus638FLPx | ~0.5m | 20Hz | 2m | External | 29 mA | $50
GP-635T | ~1m | 5Hz | 2m | Integrated | 56 mA | $40

The recently released Venus638FLPx vastly outperforms comparable units [12] due to its excellent resolution and astonishing 20Hz update rate as shown in Table 7. Real-world tests in section 11.1.7 confirmed the superior reception of this GPS receiver and its external antenna, leading to its selection for both the Phase 1 and Phase 2 headsets.

### 5.1.5 Wireless Communication

Wireless communication keeps the individual headsets connected throughout the simulation. High reliability and low latency are paramount to meet the real-time requirements of the simulation. The wireless device must also transmit a minimum of 6-8 KB per second of data to meet the simultaneous device metrics, and must be able to report the signal quality and strength. A range of 150 yards line of sight will handle most simulations.

The wireless modules considered are listed in Table 8. Range tests as described in section 11.1.5 indicated that extremely large antennas are required to obtain the advertised range on many RF communications modules, so the observed range for each device is shown.

Table 8: Decision matrix for Phase 1 wireless communication devices

Part | Data Rate | Range (LOS) | Latency | Cost
XBee Pro 900HP | 11.5 KB/s | 300 m | 50ms | $40
nRF24L01+ | 25 KB/s | 100 m | 50ms | $20
Wireless-N | 6 MB/s | 200 m | 80ms | $30
Bluetooth and Cell Phone Network | 200 KB/s | 2 km | 500ms | $30

Despite the range and data rate advantages of offloading wireless to a cell network, the test in section 11.1.6 found its latency to be unacceptable for augmented reality. The XBee Pro was selected in Phase 1 for its superior range over the nRF24L01+ module [13], which may not reach the design metric of 80 m in real-world conditions.

With the inclusion of the Intel® Atom™ motherboard in Phase 2, the XBee Pro was dropped in favor of the motherboard’s built-in Wireless N module. The small decrease in range and increase in latency was compensated by the ease of use of standard 802.11 networking and the extreme increase in data rate, which allows more simultaneous devices connected and more complex simulations with higher graphics quality.

### 5.1.6 Display

The Phase 1 motherboard, the Raspberry Pi, supports output over HDMI and composite video. With the typical requirements of low power consumption and light weight in mind, a screen intended for use in a car back-up camera was obtained [14] which massed only 80 g with its enclosure removed. The low cost of just $50 also contributed to this part’s selection.

After the completion of Phase 1, user testing revealed that the 480*272 resolution and low brightness of this display led to trouble using the device in bright outdoor conditions. With the switch to a more capable graphics processing motherboard, a higher resolution display was sought that could address apparent 3D graphics performance.

Two displays from the same vendor were tested; one was brighter and had a higher resolution of 1280*800 [15], while the other one was cheaper and used slightly less power with a resolution of 800*480 [16]. Display testing as shown in section 11.1.10 showed that both displays significantly improved brightness and contrast performance. If the challenges with graphics drivers discussed in [SECTION] are addressed, the higher-resolution display is the better choice due to its superior brightness and readability; otherwise, the lower resolution of the second display will lead to better head tracking latency performance as fewer pixels have to be redrawn every frame.

## 5.2 Hardware Design Considerations, Phase 1

### 5.2.1 Power

Power will be limited on the headset, as it will run on a lightweight single lithium ion cell worn by the user. The biggest power consumer will be the graphics processor and display used to render images. The wireless radio and GPS also consume power to send and receive data. By comparison, the current draw of the microcontroller, IMU, and other circuitry is negligible. Low-dropout linear regulators are required, since no available switch-mode regulator can efficiently convert a battery voltage as low as 3.7 V to the required 3.3 V as shown in Table 9.

Table 9: Power supply constraints and supply rails in use on Phase 1 headset

Supply Rail | Voltage | Current Required | Topology | Peripherals Powered
Vcore | 3.3 V | 500 mA | Linear | Graphics Processing
VMCU | 3.3 V | 350 mA | Linear | Microcontroller, Wireless, GPS
VADC | 3.3 V | 30 mA | Linear | IMU
VDISPLAY | 5 V | 300 mA | Switching | Display, USB

With the estimated power requirements shown above, the battery size required to achieve the design metric run time of 3 hours can be calculated using the equation shown below. As a rule of thumb, 80% of a battery’s advertised capacity can be used. This equation was chosen for its simplicity and presentation for this application by the Senior Design advisors:

Capacity=t_(runtime) *(∑ P)/(V_b *%_(discharge)) P_(Linear) =V_(battery) *i_(out) P_(Switching) =(V_(out) *i_(out))/η

Example: For the Phase 1 headset data shown above, with V_(battery) = 3.7 V nominally for a 1-cell lithium ion battery and %_(discharge) = 80% = 0.8, Capacity can be calculated as follows:

V_(core) :P=3.7*0.5=1.85 W V_(MCU) :P=3.7*0.35=1.30 W V_(ADC) :P=3.7*0.05=0.19 W V_(DISPLAY) :P=(5*0.3)/0.86=1.74 W (η estimated from charts in [17])

Capacity=(3*(1.85+1.30+0.19+1.74))/(3.7*0.8)=5.14 A*hr

Thus, a 3.7 V battery with a 5.14 A*hr capacity will lead to an approximate 3 hour runtime. In reality, temperature and aging will reduce the actual runtime. The nearest readily available battery capacity was 6 A*hr.

To supply power at the right voltage, an appropriate voltage regulator was selected for each rail. Special attention was paid to the VADC regulator, as good line regulation and high ripple rejection reduce the noise seen by the IMU. A readily available voltage regulator from Micrel® [18] was found to meet all requirements to serve each of the 3.3 V supplies. The 5 V supply, being higher than the battery voltage, requires a switch-mode regulator. A low-cost power module [17] was found that met the design requirements in an easy-to-assemble package.

Two convenient choices were found for the Phase 1 battery, a SparkFun prismatic cell [19] and an Adafruit cylindrical cell pack [20]. Both batteries combined three smaller lithium polymer cells in parallel with a protection circuit to reduce fault current and prevent overcharging for improved reliability. While the Adafruit battery was slightly cheaper, the SparkFun cell had a much smaller form factor and weighed less, leading to its selection for improved portability.

### 5.2.2 Packaging

The headset is designed to be portable and worn by the user. Of the peripherals in use, the display, inertial measurement unit, and antennas must be placed on the user’s head. An adjustable mount for the half silvered mirror and reflection shield must be provided to allow users with different head sizes to position the device for optimal viewing conditions. The device should be packaged in one unit with few exposed wires, as non-technical users should not be expected to plug in parts. Packaging must be able to withstand the vibration and impacts that are inevitable for wearable electronics, and must be able to tolerate outdoor temperatures.

### 5.2.3 Printed Circuit Board

Due to the extensive use of surface mount components in this project, a custom-designed printed circuit board (PCB) was chosen as the most reliable method of implementing the schematic design. OSH Park, the manufacturer used by the Purdue Electrical Engineering department to outsource PCB production, quotes the minimum values shown in Table 10 for their standard specification designs. For optimal manufacturing yield and to allow tolerance for best practice, the PCB was designed with wider tracing and spacing and a larger drill size. In addition, acute angles and sharp corners were avoided, as these features can trap etchant during manufacturing and lead to broken traces on the final board.

Table 10: PCB specifications for OSH Park [21], 1 mil = 0.001 inch

Metric | Given | Chosen for Manufacturability
Trace Thickness | 6 mil | 10 mil
Trace Spacing | 6 mil | 8 mil
Drill Diameter | 13 mil | 15 mil
Drill Tolerance | 5 mil | N/A
Copper Thickness | 1 (oz)/(ft^2) | N/A

The form factor and connector placement were the most important requirements for the PCB. To properly mate with the Raspberry Pi as shown in Figure 3, the PCB dimensions and I/O header placement had to exactly match the motherboard mechanical specifications [22]. External connectors for USB charging, the battery, and the radio antennas also had to face outwards on the PCB edges to allow connections to the final packaging.


Battery

Power Supply

GPS

IMU

XBee

Figure 3: Finished printed circuit board in its packaging with major sections highlighted; the motherboard is stacked directly below the board shown

The major radio frequency emitters on this board contribute electromagnetic interference (EMI) which could disrupt the inertial measurement unit (IMU), but the noise magnitude decreases with the square of the distance. The global positioning system (GPS) unit has an external antenna [23] which moves its noise emissions far from the PCB, so the XBee radio and antenna [24] was placed in the lower left corner as far away from the IMU as possible.

To reduce power supply switching noise, this design used a power and ground plane along with 12 decoupling capacitors. These capacitors were placed near each supply pin as recommended by the manufacturer [25]. Noise caused by signal reflections can be attenuated by matching the USB and crystal oscillator to under the 0.05 inch tolerance [26] using the EAGLE “run length-freq-ri” tool. An image of the complete layout is attached in the [Appendix].

### 5.2.4 Microcontroller Layout

The circuit board was designed using the EAGLE Layout Editor, which already contained the project schematics, but the built-in auto router produced unsatisfactory results. To make the PCB easier to route, pin assignments and part placements near the microcontroller were chosen to limit crossing signals as is shown in Figure 4. After final placement, spare I/O pins and a spare serial port were brought out to pads to enable debugging and future expansion.


Figure 4: Signal routing near microcontroller showing oscillator circuit and peripheral connections

### 5.2.5 Power Supply Layout

The power supply for this board must deal with a fluctuating load and battery management to maximize the device battery life while reducing the risk of device failure due to overheating. Total current could be up to 2 A during radio transmission events as evidenced by the design constraint analysis, so power supply traces were widened according to the trace heat equations shown below recommended by OSH Park to reduce resistive losses [27].

Area=(i/(0.048*∆T^0.44))^(1/0.725) Width=(Area)/(1.378*Thickness)

Example: Thickness is given to be 1(oz)/(ft^2) (see Table 10) and ∆T=10 ℃ of heating was allowed. Therefore, for a power supply trace carrying i=2 A of current, the calculation of the minimum trace Width would be (1 mil = 0.001 inch):

Area=(2/(0.048*10^0.44))^(1/0.725) =42.39 mil^2 Width=42.39/(1.378*1)=30.76 mil

Therefore, this trace should be no narrower than 0.031 inches to carry the rated current with less than the specified temperature rise. In practice, traces of twice the minimum width were selected wherever possible to reduce power loss from trace resistance and increase battery life.

Power and ground planes were emphasized to simplify power routing as is shown in Figure 5. The bottom of the board was devoted to a ground plane with few signal traces to reduce the size of noise-inducing ground loops. Power planes also provide heat dissipation paths with low thermal resistance for the regulator circuits, keeping them cool to increase reliability.


Figure 5: Close-up of power supply showing bulk capacitance and power planes

To reduce noise coupling between the IMU and the digital circuits, a separate low-dropout regulator with outstanding noise rejection was dedicated for the IMU power supply and placed close to it. Although the IMU communicates its results using a digital protocol that is resistant to interference, noise on the power supply can still disrupt the computed orientation [10]. This regulator does not have to power other loads, so switching noise is reduced. The step-up converter used to generate 5V for the display [17] was located far from the IMU to reduce its EMI coupling to the sensors.

### 5.2.6 Fabrication and Testing

This custom board design used standard library parts, but one-to-one tests were conducted before PCB fabrication as shown in section 11.1.1 to verify that the parts on hand matched the prospective board. No discrepancies were noted in this test. After receiving the initial circuit board from the manufacturer, the first procedure involved electrical conductivity tests as described in section 11.1.2. Importantly, this test discovered an unwanted short from the IMU power supply to ground; continued conductivity measurements allowed location and repair of a hair-line copper filament shorting the target trace to a ground plane.

When the board had been tested, the power supply components were installed first to verify the operation of this important section of the board. Burn-in testing procedures as described in section 11.1.3 were applied for 24 hours at the rated design load, and the supply outputs continued to function at the desired voltages. After populating the remaining components, simple test programs were uploaded to the microcontroller to test each part of the board independently. Notable tests as mentioned in sections 11.1.8 and 11.1.9 included GPS location precision and IMU head tracking performance.

## 5.3 Hardware Design Considerations, Phase 2

### 5.3.1 Power Supply

With the introduction of the Intel® Atom™ board for powering the Phase 2 graphics rendering, a substantial revision to the power supply was required. As the necessary battery to achieve the design metrics became too heavy to meet the headset design mass, the entire power supply was moved to the backpack unit with the Atom™ board. Since the sensors need to remain on the user’s head, the Phase 1 PCB was bifurcated into a dedicated sensor board and a power supply board.

Another microcontroller with USB support was now required for the split power supply board to report the battery state of charge over USB to the Intel® Atom™ board. This microcontroller had to have low stand-by power consumption, as it monitors the state of charge even when the motherboard is powered off. The STM32L100RBT6 chip was chosen due to its design and programming similarity with the sensor microcontroller and its idle mode power consumption of less than 2 µA [28].

### 5.3.2 Sensor Printed Circuit Board

Feedback from Phase 1 indicated that the head tracking system generally worked well. Phase 2 thus re-used a large fraction of the Phase 1 system board for handling the IMU and GPS sensors. The USB connector was re-purposed for communications with the Intel® board, and this opportunity was taken to reduce the PCB dimensions to lower the mass of the headset. Since the microcontroller was unchanged from Phase 1, the routing for that critical area of the PCB was also unchanged; see section 4.2.4 for details.

With the removal of the XBee, the peak current draw of the board now remains within the 500 mA USB maximum load [26]. A single 3.3 V voltage regulator sufficient to handle 500 mA now supplies the microcontroller and GPS [18] as shown in Figure 6. The separate regulator for the IMU was also retained in its original location.


Figure 6: Power supply of the Phase 2 sensor PCB

After fabrication and population, testing as conducted in section 4.2.6 revealed no issues with this design. As the board was an evolution of the Phase 1 design, knowledge from that successful design proved invaluable to the rapid design and success of this PCB.

### 5.3.3 Power Supply Printed Circuit Board

This board had a new design, needing to incorporate battery charging, monitoring, and voltage regulation for a much higher power system. Its mass was still a concern, as the backpack still had to target a wearable design mass. Connectors for USB communication, the battery, the charger, and the power output were also incorporated on the sides of the board. As this board was also fabricated by OSH Park, the specifications from section 4.2.3 were used.

## 5.4 Software Design Considerations

The Software on the DE2i-150 is divided into five modules as is shown in Figure 7. Each module communicates to the other modules using sockets. Sockets were chosen over memory mapping because data sent between modules closely resembles packets. The Simulation logic is one of the key modules because it is swappable with other logic simulations using a common application programming interface. This allows third party sources to write simulations for our hardware without needing to compile with any of our other modules or understand how each module provides its information. The Networking and Sensor Data modules are combined in the same executable.


Figure 7: Diagram of software modules

### 5.4.1 User Interface

A graphical application is provided to the user that allows them to either host a simulation or join an existing simulation. Its initial screen is shown below in Figure 8.

Figure 8: Select mode screen

The Host Simulation option allows the user to select headsets that may participate in the simulation and then choose a simulation to launch. The Join Simulation option allows the user to wait for a host as their headset is automatically configured. It displays vital information about the headset as it moves through the stages of acceptance by the host, receiving simulation information, and starting the simulation.


Figure 9: Select headset screen

The first screen shown to the simulation host is the Select Headsets screen shown in Figure 9. This screen allows the user to dynamically add and remove headsets that should be included in a simulation.


Figure 10: Select simulation screen

The second screen shown to the host is the Select Simulation screen shown in Figure 10. This screen allows the user to pick from the list of available simulations. When the host user makes a selection, the simulation will be sent and synchronized to all accepted headsets.


Figure 11: Start simulation screen

The next screen shown to the simulation host is the Start Simulation window shown in Figure 11. This allows each player to feel prepared before the actual simulation starts and after each user has received the simulation files.

Figure 12: Run simulation screen

The Run Simulation screen shown in Figure 12 may not be visible to the user since the simulation may hide it quickly, but this screen allows the user to continue monitoring status.

Figure 13: Simulation Screens for waiting to be accepted, waiting to receive simulation information, and waiting to start the simulation respectively.

If the Join Simulation option was selected instead, the user will then be taken through the three screens shown above in Figure 13. The transitions will happen automatically as the host proceeds through accepting and selecting the simulation options.

### 5.4.2 Networking

The networking module abstracts away the details of sending and receiving information over the wireless network. If the headset is configured to Join Simulation, then this module begins by broadcasting itself as an available headset for a simulation. When accepted by a host, it waits for information about the simulation to use. After receiving simulation information, it waits for the host’s confirmation to start simulating. During the simulation, this module sends out a periodic message that informs the host of its current geospatial location and orientation.

If the headset is configured to Host Simulation, then it remains quiet on the network and listens for available headsets to add to a simulation, adding each headset it discovers to its list of available headsets. The user interface may choose to accept and reject headsets at this time. When the simulation starts, the networking code sends out packets to inform other headsets of updates to 3-D object positions and orientations and the state of other users.

### 5.4.3 Sensor Data

The sensor data module is in the same executable as the networking module. This module holds the latest position and orientation information about the headset. It also performs arithmetic on the longitude and latitude coordinates received from the global positioning system (GPS) unit to produce local coordinates x and y as is shown below. Each scaling factor is calculated based on the arc lengths of one degree of latitude and longitude on a circular cross section of the earth at a given degree of latitude, where R_(earth) =6378100 m .

∆X=R_(earth) *(π/180) ΔY=R_(earth) *cos(Lat)*(π/180) x=(Lat-Lat_0 )*ΔX y=(Long-Long_0 )*ΔY

The x and y values are measured relative to an origin (Lat_0 ,Long_0 ) which is taken to be the first stable position after achieving a GPS lock. Since the origin is reset when starting a new simulation, this equation is an adequate approximation for latitude and longitude over the wireless range of just a few hundred meters. Performing true non-Euclidean geometry to handle the curvature of the Earth would involve prohibitively slow calculations.

### 5.4.4 Simulation Logic

A simulation is a Python program that utilizes our interfaces to start the graphics and to collect information about the user position and the position of other players. A series of functions and objects have been provided in this API to make development as simple as possible. This section was designed to be easy to prototype with. An extension of this section would provide the ability to write simulations in C++.

### 5.4.5 Rendering

The 3D rendering portion of the software makes use of the open source library Irrlicht [29], which is based on OpenGL and provides a relatively simple interface for accomplishing common rendering tasks. When the rendering function starts, it is passed a configuration file from which it loads the initial state of the simulation. The main rendering loop then communicates with the sensor reading code to get the user’s location and orientation, and with the simulation code to get the locations of all the virtual objects to be rendered. This data is collected is collected once per frame, and then rendered. Additionally, the battery’s current state of charge and wireless signal strength are collected from the microcontroller and displayed to the user here.

Table 11: List of important software classes; full software documentation can be found in [Appendix]

./simulation_src/testApplication.py | Pacman Application
./simulation_src/level/genlevel.c | Generates a config file from an ascii art file.
./simulation_src/gpuPyInterface.py | A python sockets interface to the graphics rendering c++ code.
./sensor_micro_src/src/main.c | The code for collecting GPS and IMU data.
./gpu_src/render/genlevel.c | Generates a config file from an ascii art file.
./gpu_src/render/main.cpp | Starts and runs all of the graphics rendering code.
./gpu_src/render/normalScreen.sh | Script to un-invert the screen.
./gpu_src/render/GameObject.h | Class that holds information about a specific 3d object being drawn on-screen.
./gpu_src/render/invertScreen.sh | Invert the screen left-right
./gpu_src/render/gpuPyThreadInterface.cpp | Serves as a sockets interface between the simulation python code and the rendering c++ code.
./gpu_src/render/InputReceiver.cpp
./gpu_src/render/Makefile
./gpu_src/render/GameObject.cpp | Class that holds information about a specific 3d object being drawn on-screen.
./gpu_src/render/SensorReader.cpp | Class that serves as a sockets interface to the networking/sensor process to collect users position.
./gpu_src/render/interface.cpp
./gpu_src/render/SensorReader.h | Class that serves as a sockets interface to the networking/sensor process to collect users position.
./gpu_src/render/gpuPyThreadInterface.h | Serves as a sockets interface between the simulation python code and the rendering c++ code.
./gui_src/textInfo.py | Text strings to display to the end user for instruction.
./gui_src/launch.py | The GUI used by the end user.
./gui_src/guiNetInterface.py | The sockets interface between the GUI and the networking/sensor code.
./networking_src/networking_daemon.cpp | The code that starts the networking threads and sensor data collection threads.
./networking_src/packetStrings.py | Python script to auto-generate packets.c/h
./networking_src/packetLib.cpp | Contains all of the networking functions and associated data.
./networking_src/threadInterface.h | Serves as a sockets interface to any code module talking to the networking or sensor code.
./networking_src/Makefile
./networking_src/gpsIMUDataThread.cpp | This code collects GPS and IMU sensor data from the sensor board over UART.
./networking_src/gpsIMUDataThread.h | This code collects GPS and IMU sensor data from the sensor board over UART.
./networking_src/threadInterface.cpp | Serves as a sockets interface to any code module talking to the networking or sensor code.
./networking_src/packetLib.h | Contains all of the networking functions and associated data.
./networking_src/generatePackets.py | Python script to auto-generate packets.c/h

# 6 Project Execution

## 6.1 Project Execution Summary

The timeline and milestones can be seen in the figures below. Each task in the timeline is color coded according to what category it belongs. These categories have been chosen because they logically separate pieces of the design and separate tasks that different team members are expected to accomplish. Multiple tasks are overlapped with each other to demonstrate which parts of the project could have been completed concurrently.

The timeline is divided into two sections denoted as Phase 1 and Phase 2. Phase 1 refers to the first iteration of the project which was implemented for a senior design project. This iteration helped the team to realize what the final outcome would look like and to understand the challenges that must be faced while designing the second iteration.


### 6.1.1 Adjustments

## 6.2 Budget

### 6.2.1 Bill of Materials

Table 12: Bill of materials for Phase 2 design

Digi-Key Part Number | | Description | Footprint | # | Per Unit | Cost
LVK12R010DERCT-ND | | Res 0.5W 10mOhm | 1206 | 1 | $0.50 | $0.50
490-6521-1-ND | | Cap 4.7uF 50V Ceramic | 1206 | 3 | $0.76 | $2.29
P16460CT-ND | | Cap 180uF 16V Low ESR | Panasonic E | 1 | $2.32 | $2.32
490-3367-1-ND | | Cap 2.2uF 50V Ceramic | 1206 | 2 | $0.39 | $0.78
CTX406-ND | | Crystal 8MHz 20pF | HC-49US | 2 | $0.36 | $0.72
160-1889-1-ND | | LED Blue | 1206 | 1 | $0.38 | $0.38
475-1407-1-ND | | LED Green | 1206 | 2 | $0.11 | $0.22
P68.1KBCCT-ND | | Res 68.1K 0.1% | 1206 | 1 | $0.79 | $0.79
P5.76KBCCT-ND | | Res 5.76K 0.1% | 1206 | 1 | $0.79 | $0.79
P100KBCCT-ND | | Res 100K 0.1% | 1206 | 1 | $0.79 | $0.79
P34KBCCT-ND | | Res 34K 0.1% | 1206 | 1 | $0.79 | $0.79
P499KBCCT-ND | | Res 499K 0.1% | 1206 | 1 | $0.79 | $0.79
P215KBCCT-ND | | Res 215K 0.1% | 1206 | 1 | $0.79 | $0.79
P2.43KBCCT-ND | | Res 2.43K 0.1% | 1206 | 1 | $0.79 | $0.79
ED2992CT-ND | | Mini USB Connector | Special | 2 | $0.87 | $1.74
497-11767-ND | | STM32F405RGT6 | TQFP 64 | 1 | $11.45 | $11.45
497-13631-ND | | STM32L100RBT6 | TQFP 64 | 1 | $4.37 | $4.37
576-1827-5-ND | | Regulator 3.3V 500mA | MSOP 8 | 1 | $2.35 | $2.35
576-1281-1-ND | | Regulator 3.3V 150mA | SOT-23-5 | 1 | $2.01 | $2.01
LM2936MP-3.3/NOPBCT-ND | | Regulator 3.3V Low-Iq | SOT-223-4 | 1 | $1.78 | $1.78
DS2782E+-ND | | Fuel Gauge IC | TSSOP 8 | 1 | $7.46 | $7.46
296-20523-ND | | Power Module 12V 3A | Special | 1 | $17.70 | $17.70
497-12918-ND | | 9-DOF IMU Breakout | DIP 24 W | 1 | $27.60 | $27.60
| | | | | | $89.20
Items available from the Senior Design lab include:
| Cap 0.1uF Ceramic | | 1206
| Cap 1uF Ceramic | | 1206
| Header Breakaway Female | | 0.1
| Header Breakaway Male | | 0.1
| Res 4.7K 5% | | 1206
| Res 10K 5% | | 1206
| Res 6.8K 5% | | 1206
| Res 22 5% | | 1206
| Res 1.5K 5% | | 1206
| Cap 39pF Ceramic | | 1206
| Cap 470pF Ceramic | | 1206
| Cap 10uF 16V | | Panasonic D
| Cap 22uF 16V | | Panasonic D
| PCB Button | | Special

### 6.2.2 Expenditures

### 6.2.3 Funding Sources

Table 13: Sources of funding for Phase 2 design

Cornell Cup | $1500
Purdue University | $300

## 6.3 Mid-Review

## 6.4 Process Understanding

# 7 Recommendations and Next Steps

# 8 Glossary

- Augmented reality: a system which overlays a computer generated image on top of real world objects so that both are simultaneously perceptible
- Global positioning system (GPS): a sensor which receives signals from a global network of satellites to determine absolute position on the Earth’s surface
- Electromagnetic interference (EMI): a disturbance in an electrical circuit induced by electromagnetic radiation from other circuits in proximity
- Equivalent series resistance (ESR): the non-ideal resistance of real electrical components, acting as if this resistance value was placed in series with the device
- Inertial measurement unit (IMU): a sensor which reports velocity, orientation, and gravitational forces
- Inter-integrated circuit interface (I²C): a two-wire bidirectional synchronous serial communications system which connects multiple master and slave electronic parts through an addressable protocol
- Jitter: the unwanted, often random, timing deviation of a periodic waveform from its expected period
- Printed circuit board (PCB): a substrate which supports and connects electrical components through an etched network of conductive traces
- Serial peripheral interface (SPI): a fast four-wire bidirectional synchronous serial communications protocol used to interface two or more electronic parts
- Turnkey startup: the ability of a device on power-up to autonomously enter a state where a non-technical user can continue use of the device
- Virtual reality: a system which fills the user’s entire field of view with a computer generated image to the exclusion of the real world

# 9 References

[1] | M. I. Olsson, M. J. Heinrich, D. Kelly and J. Lapetina, "Wearable device with input and output structures". United States of America Patent 20130044042, 18 August 2011.
[2] | Nintendo, "How Long Will the Battery Remain Charged?," [Online]. Available: http://en-americas-support.nintendo.com/app/answers/detail/a_id/385/p/430.
[3] | Sony, "Charging (PCH-1000 series)," [Online]. Available: http://manuals.playstation.net/document/en/psvita/basic/charge.html.
[4] | Oculus VR, "Development Kit 2," [Online]. Available: http://www.oculusvr.com/dk2/.
[5] | Google, "Tech Specs," [Online]. Available: https://support.google.com/glass/answer/3064128?hl=en.
[6] | B. Thomas, B. Close, J. Donoghue, J. Squires, P. De Bondi and W. Piekarski, "First Person Indoor/Outdoor Augmented Reality Application: ARQuake," Personal and Ubiquitous Computing, vol. 6, pp. 75-86, 2002.
[7] | M. Perenson, "Augmented-Reality Glasses: Startup’s Vision Could Change Gaming," 22 May 2013. [Online]. Available: http://www.technewsdaily.com/18143-augmented-reality-glasses-startups-vision-could-change-gaming.html. [Accessed 4 September 2013].
[8] | STmicroelectronics, "STM32F4DISCOVERY Discovery kit for STM32F407/417 lines - with STM32F407VG MCU," [Online]. Available: http://www.st.com/web/catalog/tools/FM116/SC959/SS1532/PF252419. [Accessed 9 August 2013].
[9] | SparkFun Electronics, "9 Degrees of Freedom - MPU-9150 Breakout - SEN-11486 - SparkFun Electronics," [Online]. Available: https://www.sparkfun.com/products/11486. [Accessed 11 October 2013].
[10] | SGS-Thomson Microelectronics, "L3GD20 and LSM303DLHC 9-axis module for a standard DIL socket," November 2011. [Online]. Available: http://www.st.com/st-web-ui/static/active/en/resource/technical/document/data_brief/DM00041389.pdf. [Accessed 8 October 2013].
[11] | SparkFun Electronics, "9 Degrees of Freedom - Sensor Stick," [Online]. Available: https://www.sparkfun.com/products/10724. [Accessed 7 October 2013].
[12] | ADH Technology Co. Ltd., "Data Sheet / GP-635T," 23 May 2012. [Online]. Available: https://dlnmh9ip6v2uc.cloudfront.net/datasheets/Sensors/GPS/GP-635T-121130.pdf. [Accessed 25 September 2013].
[13] | Nordic Semiconductor, "nRF24L01 - 2.4GHz RF - Products - Nordic Semiconductor," July 2007. [Online]. Available: http://www.nordicsemi.com/eng/nordic/content_download/2730/34105/file/nRF24L01_Product_Specification_v2_0.pdf. [Accessed 26 September 2013].
[14] | Adafruit Industries, "NTSC/PAL (Television) TFT Display - 4.3 Diagonal ID: 946 - $49.95 : Adafruit Industries, Unique & fun DIY electronics and kits," [Online]. Available: https://www.adafruit.com/products/946. [Accessed 6 September 2013].
[15] | Adafruit Industries, "HDMI 4 Pi - 5.6 Display 1280x800 (720p) Kit - HDMI/VGA/NTSC/PAL ID: 1666 - $139.95 : Adafruit Industries, Unique & fun DIY electronics and kits," [Online]. Available: https://www.adafruit.com/products/1666. [Accessed 8 January 2014].
[16] | Adafruit Industries, "HDMI 4 Pi: 5 Display no Touchscreen 800x480 - HDMI/VGA/NTSC/PAL ID: 1678 - $64.95 : Adafruit Industries, Unique & fun DIY electronics and kits," [Online]. Available: https://www.adafruit.com/products/1678. [Accessed 5 January 2014].
[17] | Pololu Robotics and Electronics, "5V Step-Up Voltage Regulator U3V12F5," Pololu Robotics and Electronics, [Online]. Available: http://www.pololu.com/catalog/product/2115. [Accessed 29 September 2013].
[18] | Micrel Inc., "500 mA-Peak Output LDO Regulator," June 2009. [Online]. Available: http://www.micrel.com/_PDF/mic5219.pdf. [Accessed 29 September 2013].
[19] | SparkFun Electronics, "Polymer Lithium Ion Battery - 6Ah - PRT-08484 - SparkFun Electronics," [Online]. Available: https://www.sparkfun.com/products/8484. [Accessed 5 September 2013].
[20] | Adafruit Industries, "Lithium Ion Battery Pack - 3.7V 6600mAh ID: 353 - $29.50 : Adafruit Industries, Unique & fun DIY electronics and kits," [Online]. Available: http://www.adafruit.com/products/353. [Accessed 4 September 2013].
[21] | OSH Park, "Pricing and Specifications," [Online]. Available: http://oshpark.com/pricing. [Accessed 12 March 2014].
[22] | Raspberry Pi Foundation, "Mechanical Profile – 3D models," [Online]. Available: http://www.raspberrypi.org/phpBB3/viewtopic.php?f=2&t=4402. [Accessed 3 October 2013].
[23] | SkyTraq Technology, "Venus638FLPx GPS Receiver," Feburary 2010. [Online]. Available: http://dlnmh9ip6v2uc.cloudfront.net/datasheets/Sensors/GPS/Venus/638/doc/Venus638FLPx_DS_v07.pdf. [Accessed 4 October 2013].
[24] | Digi Corporation, "XBee Pro 900-HP Datasheet," August 2013. [Online]. Available: http://www.digi.com/pdf/ds_xbeepro900hp.pdf. [Accessed 5 October 2013].
[25] | SGS-Thomson Microelectronics, "ARM Cortex-M4 32b MCU+FPU," September 2011. [Online]. Available: http://www.st.com/st-web-ui/static/active/en/resource/technical/document/datasheet/DM00037051.pdf. [Accessed 11 June 2013].
[26] | Cypress Semiconductor Corporation, "AN1168: High-Speed USB PCB Layout Recommendations," November 2011. [Online]. Available: http://www.cypress.com/?docID=32407. [Accessed 19 October 2013].
[27] | B. Suppanz, "PCB Trace Width Calculator," Advanced Circuits, 2007. [Online]. Available: http://www.4pcb.com/trace-width-calculator.html. [Accessed 19 September 2013].
[28] | SGS-Thomson Microelectronics, "Ultra-low-power 32-bit MCU ARM®-based Cortex®-M3, 128KB Flash, 10KB SRAM, 2KB EEPROM, LCD, USB, ADC, DAC," 21 February 2013. [Online]. Available: http://www.st.com/st-web-ui/static/active/en/resource/technical/document/datasheet/DM00078075.pdf. [Accessed 25 February 2014].
[29] | "Irrlicht," [Online]. Available: http://irrlicht.sourceforge.net/.
[30] | SparkFun Electronics, "Crystal 8MHz," [Online]. Available: https://www.sparkfun.com/products/538. [Accessed 2 October 2013].

# 10 Acknowledgements

The Cornell Cup team Augmented Reality Simulator would like to recognize the following individuals and groups for their contributions to this project.

Dr. Mark C. Johnson offered to advise the team and dedicated his time to logistics, procuring funding, and organizing status meetings to update the timeline and keep the project on schedule.

Blaine Gardner and Aditya Balasubramanian, as members of the previous Purdue Cornell Cup entry “The Incredible HUD”, advised the team about competition entry requirements, the mid-review process, and documentation.

Dr. David G. Meyer and his team of Senior Design teaching assistants, including George Hadley and George Toh, provided the team with substantial technical insight and evaluated the initial documentation for the Phase 1 senior design project.

The Purdue Electrical and Computer Engineering (ECE) department provided funding for the completion of Phase 2 and countless hours of education for all members of the team to lay groundwork for even attempting a project of this scale.

Joseph Boettcher and the staff of the Purdue ECE instrument room generously handled parts and printed circuit board ordering and gave additional technical insight. Joseph also participated in a mock Mid-Review session to evaluate improvements to the project.

Dr. Karthik Ramani provided us with the means to compare our design against Google Glass and the Oculus Rift in his lab for the purposes of the Performance Metrics in section 3.1 and the Brightness and Contrast test in section 11.1.10.

# 11 Survey Responses

# 12 Appendix

## 12.1 Test Plans

### 12.1.1 One-To-One Sizing and Placement Test

Purpose | Verify that a custom printed circuit board (PCB) will fit the components intended for use
Results | Do the components fit in the correct locations without conflicts? (Pass/Fail)
Materials | EAGLE Layout Editor, printer, paper, components under test

To conduct this test, print the board design at a Scale of 1.0 using the Print option in the EAGLE Layout Editor used to design the boards. Each component is then literally lined up on the printout to verify that there are no collisions between parts and that the parts align with their allocated spaces. An example of this test in progress is shown in Figure 14.


Figure 14: One-to-one PCB test in progress showing template board and some components placed

### 12.1.2 PCB Continuity and Functionality Test

Purpose | Verify that a custom PCB has been correctly manufactured
Results | Are components connected to their intended destinations? (Pass/Fail) Are there unwanted connections between components? (Pass/Fail)
Materials | Electrical resistance tester, board under test

Manufacturing errors during fabrication can occur even on boards with generous tolerances. Each board is thus tested with an electrical resistance checker in locations where errors are most likely or most critical, particularly near the power supply and around the microcontroller. Both positive tests to ensure that all intended components are connected and negative tests to ensure that unwanted connections were not present must be conducted.


Figure 15: The PCB continuity and functionality check uncovered a hairline short in the highlighted location which could lead to overheating or fire if uncorrected

### 12.1.3 Power Supply Burn-In

Purpose | Verify that the power supply components of the design function as intended
Results | Is power supply voltage within 5% of nominal value? (Pass/Fail) Is power supply voltage within 5% of nominal value after 24 hours of operation? (Pass/Fail)
Materials | Adjustable power supply capable of 19.0 V DC at 1 A, electrical voltage meter which can measure up to 20 V, 10 Ω 20 W power resistor


### 12.1.4 Total Runtime Test

Purpose | Measure headset performance on the Power metric in section 3.1
Results | Average headset runtime on a full battery charge (hours)
Materials | Two headsets, battery charger, stopwatch

Prior to conducting the test, the headset is powered OFF using its external power switch and charged for at least 12 hours using its battery charger. This ensures that the test is always starting with a consistently full battery when performing repeated trials.

The headset is then turned on, and a stopwatch is started to monitor elapsed time. The device under test is connected wirelessly to another headset which is plugged into its battery charger, and a simulation is executed as shown in section 4.4.1. A tester then uses the headset normally until the screen goes blank or the battery status indicator displays that the battery is empty. The timer is then stopped, and the time elapsed is recorded as the headset’s total runtime. Results often depend on the temperature and random variation, so this test should be run multiple times to obtain a more reliable average runtime.

### 12.1.5 Wireless Range Test

Purpose | Measure headset or wireless module (for purpose of component selection) performance on the Wireless metric in section 3.1
Results | Average wireless communications range in line of sight conditions (meters)
Materials | Two headsets or wireless modules under test, open area with landmarks and a scale map to estimate location

One wireless device is configured through software to reply to all packets that it receives. The second device sends a packet once per second, and should be given to a mobile tester which can walk across the open area. This test is limited to testing line of sight (LOS) range, as it is difficult to estimate the distance traveled across an area with many obstacles.

To perform the test, the mobile tester should slowly walk in a straight line away from the starting point, while the headset at the starting area is replying to packets received from the moving headset. When replies are no longer displayed on the mobile headset, note the location where the last successful reply was received using landmarks at the edge of the test site. After conducting tests in several different directions, each point is plotted on a scale map and the distance to the starting point measured and averaged to determine the wireless range.


Figure 16: Wireless range test in progress, with the tester located in the orange box in this photo

### 12.1.6 Wireless Latency Test

Purpose | Measure wireless communications latency for purposes of component selection
Results | Average wireless round-trip latency (milliseconds)
Materials | Two wireless modules under test

[IMAGE: Ping]

### 12.1.7 GPS Total Accuracy Test

Purpose | Measure headset or GPS module (for purposes of component selection) performance on the Location Accuracy metric of section 3.1
Results | Estimated geospatial location accuracy (meters)
Materials | Headset or GPS unit under test, reference route with scale map

The software on the headset under test must be configured to log each location data point received from the GPS module into a file. The headset is then powered on at the starting location. Once the GPS module obtains a position fix, the tester carries the headset while walking along a reference route at a consistent speed. The reference route should be chosen so that it will be easy to visibly plot on an overhead view scale map, ideally along sidewalks, streets, or buildings. In addition, the reference route should include open areas and locations with trees or structures to test GPS performance in a variety of conditions.


Figure 17: Total accuracy test data plotted as a blue line on a satellite map for the purposes of comparison to the known reference route

Figure 17 shows an example route plotted from the results of this test, using the headset and the chosen Venus 638FLPx receiver. This route spanned about 1.2 km near and on Purdue University’s main campus.


Figure 18: A location where the GPS unit maintained excellent performance despite interfering trees; the reference path is shown by the red line, while the blue line shows the computed path

For the majority of this test, the GPS accuracy was within 2 meters of the reference route. One example is shown in Figure 18, where the trees did not prevent the GPS from accurately tracking the user’s position.


Figure 19: A location where the GPS unit displayed worse than its typical accuracy; the reference path is shown by the red line, while the blue line shows the computed path

However, in a few locations, the GPS sensor accuracy was worse than 2 meters, such as in the area shown in Figure 19. While calculating the actual average distance to the reference route is very difficult, the estimated GPS accuracy was determined to meet the 2 meter metric.

### 12.1.8 GPS Relative Accuracy Test

Purpose | Measure headset or GPS module (for purposes of component selection) performance on the Location Precision metric of section 3.1
Results | Estimated geospatial location precision (meters)
Materials | Headset or GPS unit under test, small open area

[IMAGE: From Thor]

### 12.1.9 Head Tracking Test

[LINK: Youtube video?]

### 12.1.10 Brightness, Contrast, and Color Reproduction Test

Purpose | Measure the quality of display devices for component selection purposes
Results | [Red, Green, Blue, Cyan, Magenta, Yellow, Gray] color reproduction (# distinct shades); Dark reproduction (# bars visible); Bright reproduction (# bars visible)
Materials | Devices under test, outdoor sunny area


### 12.1.11 Maximum Simultaneous Devices Test

Purpose | Extrapolate the value of the Simultaneous Devices metric of section 3.1 from a limited number of constructed headsets
Results | Calculated number of simultaneous devices supported by the simulation (#)
Materials | Two headsets under test

[IMAGE: ifconfig, box the bytes sent location, before and after]

### 12.1.12 Multiple Headset Test

## 12.2 Assembly and Construction

Constructing a headset for this project is a fairly simple but quite laborious process. At a high level, the basic steps are to mount a screen and reflector to a suitable enclosure, construct and mount to the helmet a set of aluminum mounting rails, mounting the display assembly to the mounting rails, and then constructing and mounting a sensor enclosure to the rails.

### 12.2.1 Materials required

Table 14 shows the materials required to assemble the headset packaging.

Table 15: Materials required for assembly of headset packaging

Material | Quantity
Hard Hat | 1
Angle aluminum, 1/8” thickness, ½” leg | 3 feet
Project Box, 4”x6”x2” | 1
Project Box, 5”x2.5”x2” | 1
Zip ties | 25
Screws | 10

### 12.2.2 Rail Assembly

Due to the difficult of mounting hardware directly to a hard hat, a system of rails must first be mounted to facilitate the rest of construction. The material used will be aluminum angle bar with 1/8” thickness and ½” length.

### 12.2.3 Display Assembly

This part will vary quite a lot depending on the type of display being used and how it will need to be mounted. We have created headsets using two different displays and the procedures for each were drastically different.

### 12.2.4 Reflector

To achieve the desired augmented reality effect, a sheet of semi-transparent, semi-reflective material is required. In this case it will be a sheet of polycarbonate with a reflective film applied on one side, and a tint film applied to the other side to mitigate brightness issues. A sheet of approximately 6”x4”x1/8” must be cut out. Several holes must be drilled for mounting purposes. Two will be near the bottom corners, which will be used for wire loops to hold the reflector at the correct angle. Four more will be along the top edge, for hinges which secure the reflector to the front of the headset. After the sheet has been cut to the correct size and the holes drilled, a sheet of reflective film the same size as the plastic needs to be cut out and applied as per the directions supplied with film. Then the tint film is to be applied to the other side in the same way. Be mindful that the reflective side needs to be facing the user once everything is assembled.

### 12.2.5 Sensor Assembly

The sensors used to measure the user’s location and head orientation reside on their own circuit board which must be mounted to the headset. This is accomplished by mounting the PCB inside of its own enclosure and mounting that enclosure to the rear portion of the rail assembly on the headset. The enclosure used will be a 5”x2.5”x2” ABS project box.

### 12.2.6 Mounting the PCB to the enclosure

In order to mount the PCB to the enclosure, several holes will first need to be drilled.

### 12.2.7 Mounting the enclosure to the rail

## 12.3 Failure Mode Worksheet

A failure modes, effects, and criticality analysis (FMECA) worksheet examines the possible failure modes of the device given a failure of one of its parts. For each potential failure, the effects and criticality is stated. A high-criticality failure is likely to injure the user, while a failure which causes the device to simply cease operating is low criticality. Medium criticality failures may involve a display that appears functional but distracts the user with flashing images or intermittent failures which may not be obvious to a non-technical user.

Table 16: FMECA worksheet for power supply and battery charging

Failure Mode | Possible Causes | Effects | Detection Method | | Criticality
VIN shorted to GND | Failure of U6, U5, U4, battery protection circuit | Device overheats; fire or explosion may occur | Observation | | High
VUSB shorted to VBAT | Failure of U3 and battery protection circuit | Battery is overcharged; fire or explosion may occur | Observation | | High
VADC > 3.3 V | Failure of U6, VIN shorted to VADC | IMU reports invalid values or is damaged | User head rotation is ignored | | Low
VCORE > 3.3 V | Failure of U5, VIN shorted to VCORE | Motherboard crashes or is damaged | Blank or static display | | Low
VMCU > 3.3 V | Failure of U6, VIN shorted to VMCU | Microcontroller crashes or is damaged | Blank or static display | | Low
Battery monitor fails | Failure of U2 | Reported battery charge is incorrect | Battery charge indicator invalid | Low

Table 17: FMECA worksheet for processing units and sensors

Failure Mode | Possible Causes | Effects | Detection Method | Criticality
Controller crashes | Failure of C1-C13, R2, Y1, U1 | Microcontroller computes invalid data | Corrupt display | Medium
Graphics processor crashes | Failure of JP7, U5, components on motherboard | Motherboard produces invalid image | Corrupt display | Medium
Controller fails to start | Failure of C1-C13, R2, Y1, U1 | Microcontroller sends no data to motherboard | Blank or static display | Low
Graphics processor fails to start | Failure of JP7, U5, components on motherboard | Motherboard does not produce an image | Blank display | Low
Display does not function | Failure of display driver board or cables | Image is not displayed to the user | Blank display | Low
IMU data invalid or missing | Failure of U6, U7, C12-C13, C19 | Calculated user head orientation is incorrect | Invalid display, virtual heading is wrong | Low
GPS data invalid or missing | Failure of JP4, JP5, U4, GPS unit | Calculated user geospatial position is incorrect | Invalid display, virtual position is wrong | Low

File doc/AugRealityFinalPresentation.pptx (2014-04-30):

## Augmented Reality Cornell Cup Mid Review Spring 2014

Stephen Carlson
Steven Ellis
Thor Smith


Steven
Ellis

Stephen
Carlson

Thor
Smith

## Outline

- Challenge Definition
- Project Entry Solution
- Performance Evaluation
- Technical Ingenuity
- Project Execution Overview
- Recommendations and Next Steps

## Outline

- Phase 1: Senior Design
  - ECE senior design project
- Phase 2: Cornell Cup
  - Intel/Cornell cup updates

## Challenge Definition

- Challenge Definition
- Design Requirements
- Use Cases

## Challenge Definition


- Wearable augmented reality
  - Google Glass, Oculus Rift, Epson BT-100
  - Promote teamwork
  - Substitute for physical objects


## Design Requirements

- Portable, comfortable, easy to use
- Track position and head orientation
- Wireless communication
- Maintain real-world perception

## Use Cases

- Educational and training
- Virtual tour, guide, or navigation
- Gaming
  - Place “imaginary” objects in real world


## Project Entry Solution

- Project Entry Solution
- Solution to The Challenge
- Block Diagram
- Software Diagram

## Project Entry Solution

- Multi-user gaming
  - Multiple games supported
  - Integrate with real world

Headset:
  - Display
  - Orientation tracking
  - Location tracking

Backpack:
  - Wireless
  - Graphics processing
  - Simulation logic
  - Battery and power

## Solution to The Challenge

- Display virtual and real world
  - No real-world lag unlike camera
  - Interact with real and virtual objects
- Track user position and heading
  - Update virtual world
- Communication with other devices

## Block Diagram

## Software Diagram


## Performance Evaluation

- Performance Metrics
  - Portability and ease of use
  - Position and orientation tracking
  - Wireless communication
- Performance Results

## Performance Metrics

- Portable, comfortable, easy to use
  - Mass [kg]
  - Total runtime [hours]
  - Virtual image quality
  - User experience survey


## Performance Metrics

- Track position and head orientation
  - Location precision [m]
  - Head tracking latency [ms]


## Performance Metrics

- Wireless communication
  - Network refresh [updates per second]
  - Wireless range, line of sight [m]
  - Simultaneous device limit


## Performance Results

Metric | Phase 1 | Target | Phase 2
Mass [kg] | Headset: 1.3 | Headset: 1 Backpack: 3 | Headset: 1.2 Backpack: 2.5
Total Runtime [hours] | 3 | 3 | 2.5
Location Precision [m] | 1.5 | 2 | 1.5
Wireless Range [m] | 200 | 80 | 110
Display Refresh [FPS] | 10 | 20 | 20
Network Refresh [FPS] | Unimplemented | 20 | 20
Simultaneous Devices | 6 | 16 | 127
Tracking Latency [ms] | 100 | 50 | 50

## Technical Innovation

- Overlay virtual world
  - Preserve depth perception
  - Large field of view (61°)
  - Reduced eye strain
- Head and position tracking
  - Digital filtering of orientation
- Wireless communication
  - Collaborative augmented reality

## Technical Innovation

- Self-contained device
  - Adjustable
  - Lightweight, balanced
- Functional software
  - OpenGL rendering
  - Multi-user
  - “PacMan” game
  - Extensible


## Technical Features (Phase 1)

- IMU and GPS interfacing
- 900 MHz wireless
  - Requires central server
- Efficient power management
  - Battery charging


## Technical Features (Phase 2)

- Wireless N network
  - Up to 127 devices usable at once
  - Eliminate dedicated server
- Virtual image fidelity
  - Improve brightness and contrast
  - Higher resolution
  - Faster graphics engine


## Project Execution Overview

- Project Milestones
- Challenges
- Risk Handling
- Budget

## Project Milestones

- Phase 1 completion: Dec 2013
  - Head tracking and GPS
  - Initial software
- Cornell Cup Mid Review: Feb 2014
  - Increased testing and metrics
  - Compare to existing devices
  - Improve display visibility


## Project Milestones

- Final packaging: Apr 2014
  - Final power supply
  - Mount new display
- Software finalized: Apr 2014
  - Multiple headsets networking
  - File transfer
  - User testing begins


## Challenges

- DE2i-150 graphics drivers
- Power consumption
  - Required battery for 3 hours unavailable
- User testing is subjective

## Risk Handling

- Patent liability
  - Many existing virtual reality patents
  - Licensing may be required
- Safety and reliability
  - LiFePO4 relatively safe
  - Redundant power protection
  - Translucent display allows awareness of environment


## Budget

- Funding provided by Cornell Cup, Purdue ECE
- Major development expenses
  - Displays - $205
  - Batteries - $114
  - Electronics - $130

## Recommendations and Next Steps

- Continued software development
  - Head tracking and GPS precision
  - User interface
- Upgrade motherboard
  - Longer battery life
  - Better graphics performance
  - High cost (over $100)


## Recommendations and Next Steps

- Alternative input devices
- Capitalization
  - Software sales, SDK
  - Sell to schools
  - Sell to firms for training

## Special Thanks To

- Senior Design staff
  - Dr. David Meyer, George Hadley, George Toh
- The Incredible HUD team
  - Aditya B., Blaine Gardner
- Dr. Mark Johnson, advisor
- Joseph Bougher, ECE lab staff
- Dr. Karthik Ramani
- Intel and Cornell University

## Questions / Discussion

## PCB Layout, Phase 1


## PCB Layout, Phase 2 Sensor


## PCB Layout, Phase 2 Power


## Schematic, Phase 1


## Schematic, Phase 2 Sensor


## Schematic, Phase 2 Power


## Patents

- US 8585476 B2
  - Location-based games and augmented reality systems
- US 20130267309 A1 [pending]
  - Augmented reality and physical games
- US 8519844 B2
  - Augmented reality and location determination methods and apparatus

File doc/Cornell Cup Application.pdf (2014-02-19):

Purdue University

# Augmented Reality Simulator

A multi-user augmented reality simulator with heads-up display

### Stephen Carlson, Steven Ellis, Thor Smith

### Table of Contents

### Project Summary

Wearable computing is quickly becoming the next step of embedded systems evolution. A revolution which began with smartphones has progressed to devices like Google Glass and the Samsung Galaxy Gear aimed to bring computing closer to everyday life. But existing wearable implementations target the consumer market and intend to serve as merely omnipresent gateways to the Internet of Things. As a solution, this team proposes an augmented reality platform which offers new multi-user collaborative applications for wearable computing.

To provide this functionality, sensor fusion of geospatial position and inertial measurements will allow the device to determine the user’s location and head orientation for applications such as driving directions or virtual tours. A team-designed power management system will be used to maximize battery life. Wireless connectivity and a user interface designed for wearable computing will also be critical for integration with other headsets. This device aims to minimize disruption of the user’s peripheral vision while also avoiding the eyestrain of constant visual refocusing. The device will eventually be tested both indoors and outdoors to ensure adequate visibility in a range of lighting conditions and user-friendliness for a non-technical audience.

### Challenge Definition

Wearable computing is quickly becoming the next step of embedded
systems evolution. Devices like Google Glass [1] as shown in Figure 1 and
the Samsung Galaxy Gear aim to make computing part of everyday life. However, existing wearable devices are designed to serve as omnipresent gateways to the Internet and are not intended to work
together in a collaborative real-time application with multiple users. As
an alternative, this team proposes an immersive augmented reality


platform which offers new multi-user applications for wearable computing. Such a device would have broad applications in education, defense, group recreation, and artistic performances where small teams of users can work together in the same augmented reality environment.

Portability and ergonomic challenges will primarily influence project development, as competing devices are often chosen for small size and low power consumption. A good solution to this challenge must have long battery life and a low mass to promote long-term wearable usage patterns. The virtual environment will not replace the real environment, so an ideal solution must also allow the user to perceive the real world with minimal eye strain or peripheral vision obstruction. Since augmented reality systems aim to overlay objects onto real-world positions, a successful device must be able to determine the position and orientation of the user in three-dimensional space within at least a few meters of precision.

This device must be capable of wireless communication with other augmented reality devices in close proximity to enable multi-user applications, where more than one user can share the same virtual environment. From a user perspective, ergonomics are also a major concern for wearable devices; the challenge is incorporating the desired functionality while not creating an unnecessarily heavy or bulky device. A successful device must also be durable enough to withstand regular use while not requiring technically experienced users for support.

While the software to support an augmented reality application will be dependent on the eventual usage case, the operating system which configures the headsets and handles common functionality like wireless networking and sensor processing must be easy to set up and use. For a non-technical user to understand the device, the application must start automatically on power up and walk the user through any initial setup process such as wireless pairing or sensor calibration. Custom applications which are written for this device should maintain a consistent state across any and all participating users and update the displayed virtual world at timely intervals.

Figure 1: Google Glass, an existing wearable computing product
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

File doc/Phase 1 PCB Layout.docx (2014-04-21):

# Layout, Composite


# Layout, Top Copper


# Layout, Bottom Copper


# Layout, Top Silk Screen


# Layout, Bottom Silk Screen


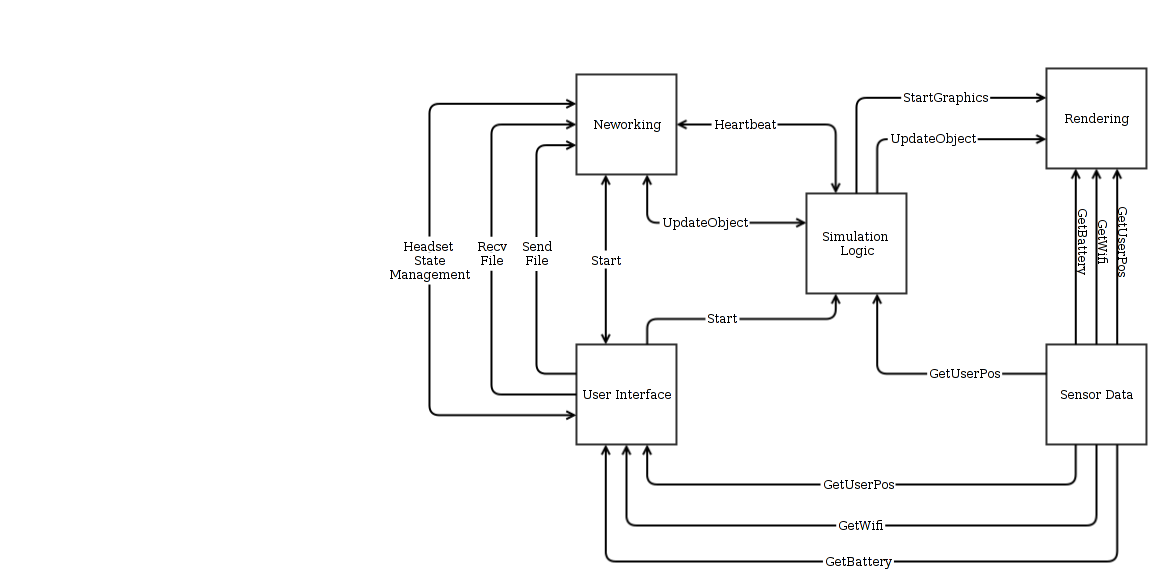
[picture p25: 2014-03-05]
doc/software_diagram.png

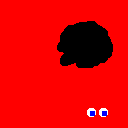
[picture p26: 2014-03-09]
headset/src/simulation_src/simulations/pacman/models/ghost.png

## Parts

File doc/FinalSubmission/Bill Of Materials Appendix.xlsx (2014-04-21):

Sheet: Phase 1 Costs
Phase 1 Costs
Name | Item | Vendor | Unit Price | Shipping | Quantity | Price
Micro Eval Board | Eval Kit STM32F Discovery | DigiKey | 14.9 | 0 | 2 | 31.886
9-Axis IMU | 511-STEVAL-MKI108V2 | Mouser | 27.5 | 0 | 3 | 82.5
Analog Interface Dev | MCP73831T-2ACI/OT | Microchip | 0.56 | 6.78 | 5 | 9.776
XBEE Pro | XBEE PRO 900 S3B 900HP RPSMA | DigiKey | 39 | 0 | 1 | 41.73
Duck Antenna | 900 MHZ Duck Antenna RPSMA | SparkFun |  | 0 | 1 | 0
Microcontrollers | STM32F405RGT6 | DigiKey | 11.45 | 0 | 3 | 36.7545
GPS Antenna | GPS-00464 | SparkFun | 12.95 | 0 | 3 | 38.85
GPS | GPS-11058 | SparkFun | 49.95 | 0 | 3 | 149.85
Shipping Cost | Shipping Cost for GPS items | SparkFun | 0 | 14.34 | 0 | 14.34
Fuel Guage | MAXIM IC CHIP | MaximIC | 0 | 0 | 0 | 0
Aluminum Angle | ALUM ANG 1/16''X1/2'' 3FT | Menards | 1.96 | 0 | 2 | 4.1944
Hard Hat | White Hard Hat | Menards | 6.48 | 0 | 2 | 13.8672
Mini Hack Saw | 8-5/8'' Mini Hack Saw | Menards | 2.97 | 0 | 1 | 3.1779
Acrylic | 18x24 OPTIX | Menards | 4.99 | 0 | 1 | 5.3393
Acrylic | 8x10 Non Glare | Menards | 1.42 | 0 | 1 | 1.5194
Screws | 24x 1/2 COMBO RD MS | Menards | 3.29 | 0 | 1 | 3.5203
Aluminum Rod | ALUM ANG 1/16''X1/2'' 3FT | Menards | 1.96 | 0 | 2 | 4.1944
Window Tint | 2'x15' LW-E ULT PLAT GRA | Menards | 25.78 | 0 | 1 | 27.5846
Hinges | 1'' HINGE (SQ) NR PIN-ZI | Menards | 1.48 | 0 | 1 | 1.5836
Film Solution | FILM APP & CLEAN SOLUTION | Menards | 3.76 | 0 | 1 | 4.0232
Project Box | 4"x6"x2" Project Box | Radio Shack | 5.46 | 0 | 2 | 11.6844
Total |  |  |  |  |  | 486.3752

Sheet: Phase 2 DigiKey Purchase
Digi-Key Part Number |  | Description | Footprint | # | Per Unit | Cost
LVK12R010DERCT-ND |  | Res 0.5W 10mOhm | 1206 | 1 | $0.50 | $0.50
490-6521-1-ND |  | Cap 4.7uF 50V Ceramic | 1206 | 3 | $0.76 | $2.28
P16460CT-ND |  | Cap 180uF 16V Low ESR | Panasonic E | 1 | $2.32 | $2.32
490-3367-1-ND |  | Cap 2.2uF 50V Ceramic | 1206 | 2 | $0.39 | $0.78
CTX406-ND |  | Crystal 8MHz 20pF | HC-49US | 2 | $0.36 | $0.72
160-1889-1-ND |  | LED Blue | 1206 | 1 | $0.38 | $0.38
475-1407-1-ND |  | LED Green | 1206 | 2 | $0.11 | $0.22
P68.1KBCCT-ND |  | Res 68.1K 0.1% | 1206 | 1 | $0.79 | $0.79
P5.76KBCCT-ND |  | Res 5.76K 0.1% | 1206 | 1 | $0.79 | $0.79
P100KBCCT-ND |  | Res 100K 0.1% | 1206 | 1 | $0.79 | $0.79
P34KBCCT-ND |  | Res 34K 0.1% | 1206 | 1 | $0.79 | $0.79
P499KBCCT-ND |  | Res 499K 0.1% | 1206 | 1 | $0.79 | $0.79
P215KBCCT-ND |  | Res 215K 0.1% | 1206 | 1 | $0.79 | $0.79
P2.43KBCCT-ND |  | Res 2.43K 0.1% | 1206 | 1 | $0.79 | $0.79
ED2992CT-ND |  | Mini USB Connector | Special | 2 | $0.87 | $1.74
497-11767-ND |  | STM32F405RGT6 | TQFP 64 | 1 | $11.45 | $11.45
497-13631-ND |  | STM32L100RBT6 | TQFP 64 | 1 | $4.37 | $4.37
576-1827-5-ND |  | Regulator 3.3V 500mA | MSOP 8 | 1 | $2.35 | $2.35
576-1281-1-ND |  | Regulator 3.3V 150mA | SOT-23-5 | 1 | $2.01 | $2.01
LM2936MP-3.3/NOPBCT-ND |  | Regulator 3.3V Low-Iq | SOT-223-4 | 1 | $1.78 | $1.78
DS2782E+-ND |  | Fuel Gauge IC | TSSOP 8 | 1 | $7.46 | $7.46
296-20523-ND |  | Power Module 12V 3A | Special | 1 | $17.70 | $17.70
497-12918-ND |  | 9-DOF IMU Breakout | DIP 24 W | 1 | $27.60 | $27.60
 |  |  |  |  |  | $89.19
Items available from the Senior Design lab include:
 | Cap 0.1uF Ceramic |  | 1206
 | Cap 1uF Ceramic |  | 1206
 | Header Breakaway Female |  | 0.1
 | Header Breakaway Male |  | 0.1
 | Res 4.7K 5% |  | 1206
 | Res 10K 5% |  | 1206
 | Res 6.8K 5% |  | 1206
 | Res 22 5% |  | 1206
 | Res 1.5K 5% |  | 1206
 | Cap 39pF Ceramic |  | 1206
 | Cap 470pF Ceramic |  | 1206
 | Cap 10uF 16V |  | Panasonic D
 | Cap 22uF 16V |  | Panasonic D
 | PCB Button |  | Special

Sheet: Phase 2 Costs
Name | Vendor | Unit Price | Quantity | Price
Connector/Adaptor | BatterySpace | 2.66 | 2.00 | 5.32
Battery charger | BatterySpace | 37.95 | 3.00 | 113.85
Battery | BatterySpace | 65.50 | 2.00 | 131.00
HDMI 4 Pi - 5.6" Display 1280x800 (720p) Kit - HDMI/VGA/NTSC/PAL | Adafruit | 139.95 | 1.00 | 139.95
HDMI 4 Pi: 5" Display no Touchscreen 800x480 - HDMI/VGA/NTSC/PAL | Adafruit | 64.95 | 1.00 | 64.95
HDMI Cable | Adafruit | 9.90 | 1.00 | 9.90
Circuit Board (PCB) | OSH Park | 40.00 | 4.00 | 160.00
5"x 2.5" Project Box | Radio Shack | 5.49 | 2.00 | 10.98
6"x4"x2" Project Box | Radio Shack | 4.25 | 1.00 | 4.25
Yellow Hard Hat | Ace Hardware | 10.00 | 1.00 | 10.00
DigiKey Expenses (From DigiKey Purchase) | DigiKey | 89.19 | 1.00 | 89.19
Light Backpack | N/A | 0.00 | 2.00 | 0.00
LMZ14203H Regulator | TI | 0.00 | 2.00 | 0.00
DS2782 Fuel Guage | Maxim | 0.00 | 2.00 | 0.00
 |  |  |  | 734.07

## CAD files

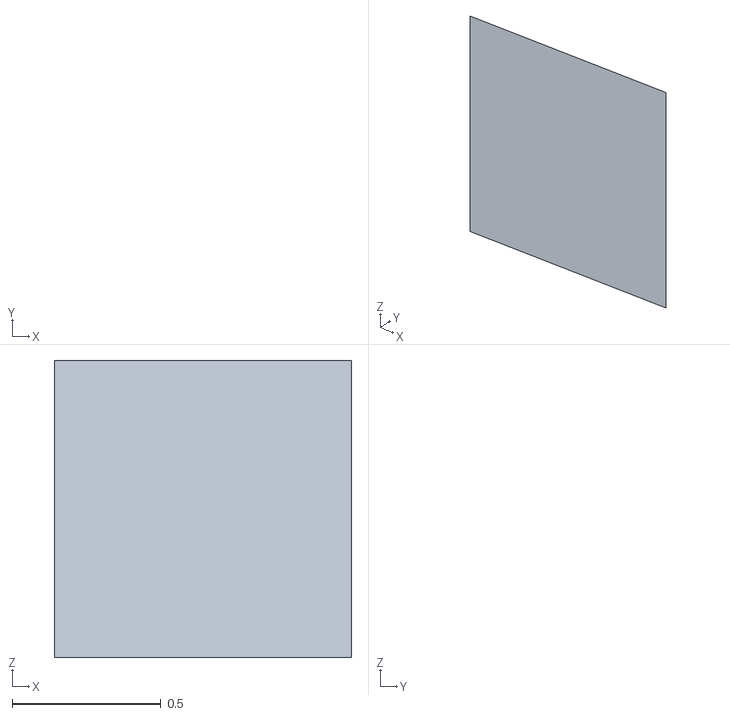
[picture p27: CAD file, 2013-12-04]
headset/src/simulation_src/models/square.obj
1.00 x 0 x 1.00

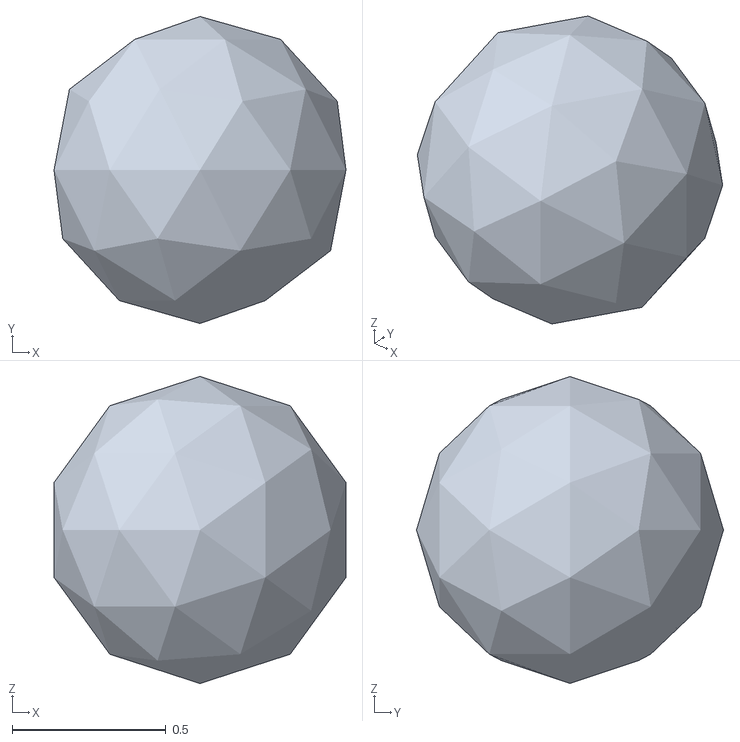
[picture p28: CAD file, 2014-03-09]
headset/src/simulation_src/simulations/pacman/models/pellet.obj
0.951 x 1.00 x 1.00

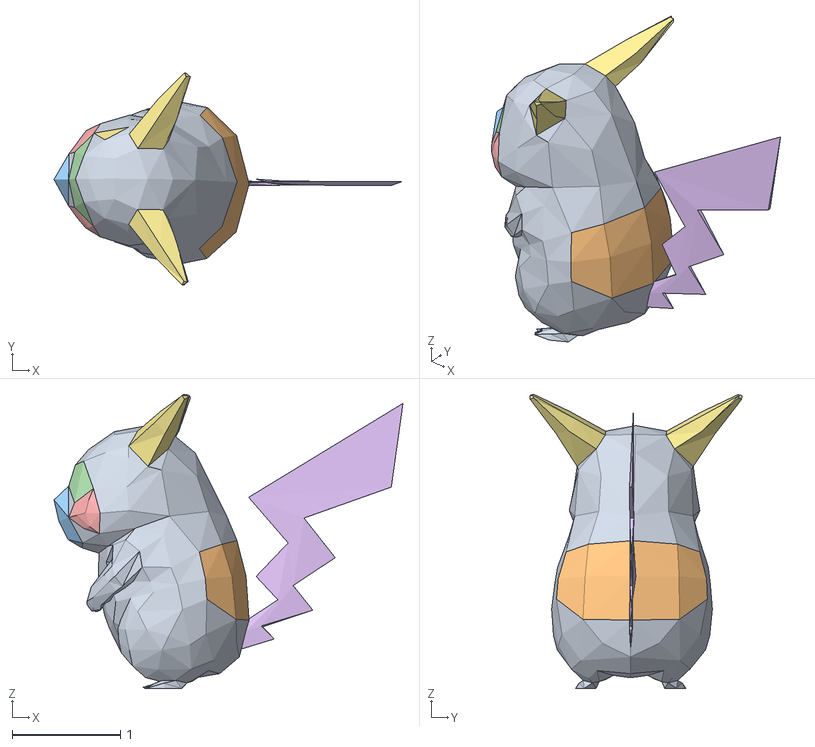
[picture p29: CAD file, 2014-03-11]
headset/src/simulation_src/simulations/trees/models/pikachu.obj
3.23 x 1.96 x 2.72
DrawCall_8
DrawCall_7
DrawCall_14
DrawCall_13
DrawCall_21
DrawCall_9
DrawCall_34

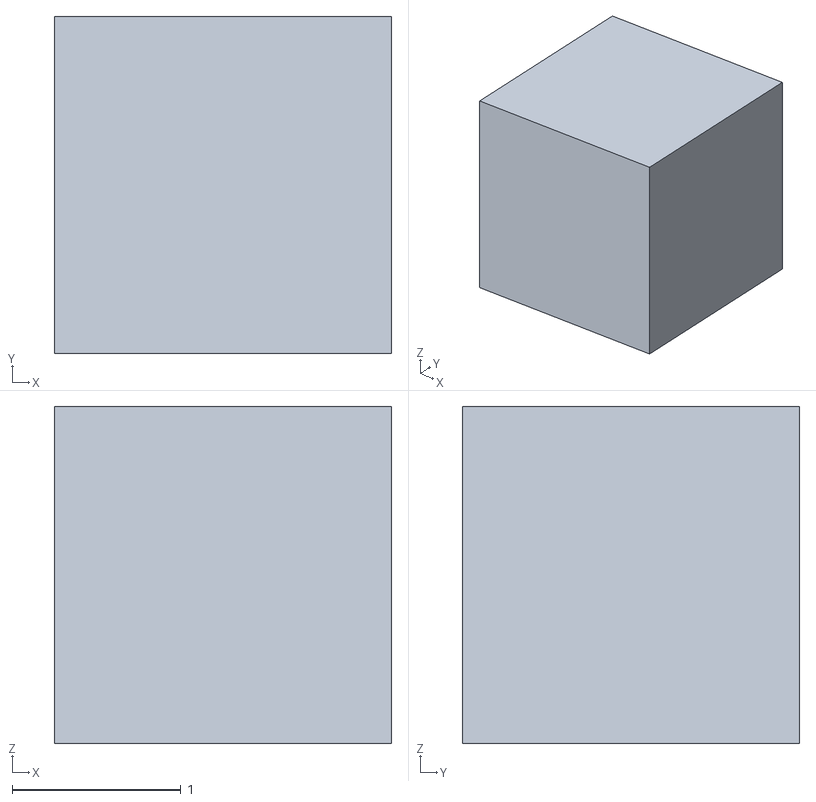
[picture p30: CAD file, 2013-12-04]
headset/src/simulation_src/models/wall.obj
2.00 x 2.00 x 2.00

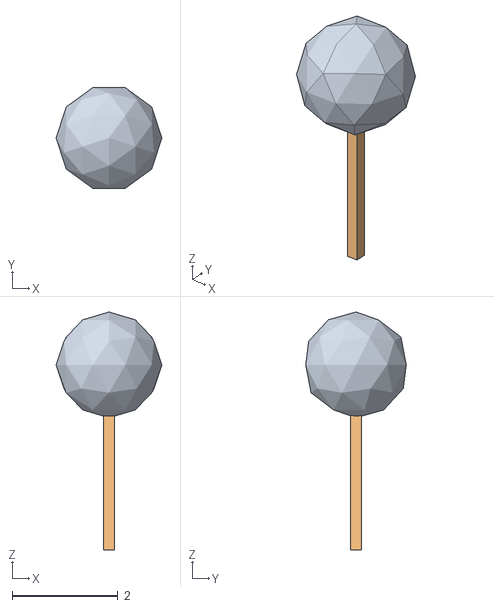
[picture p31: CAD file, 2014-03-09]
headset/src/simulation_src/simulations/trees/models/tree.obj
2.00 x 1.90 x 4.50
Icosphere

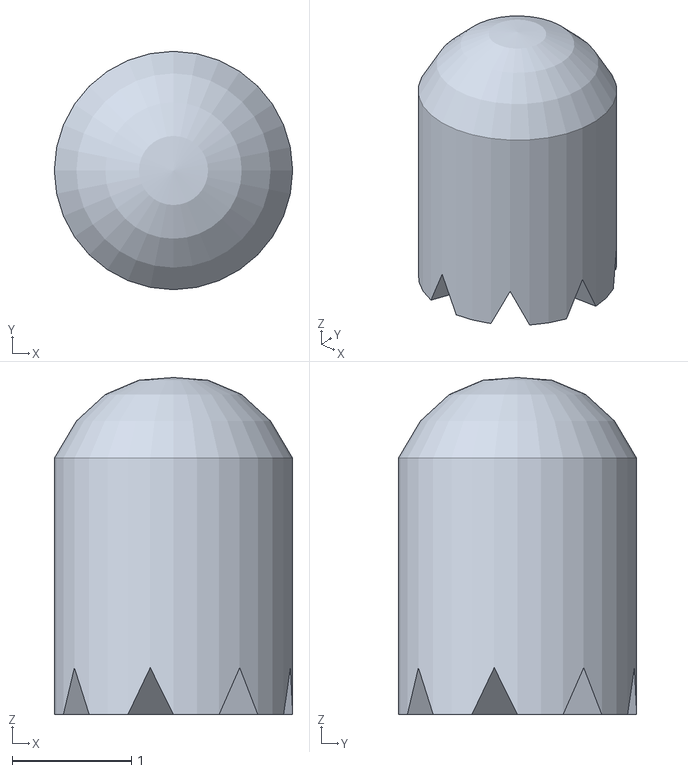
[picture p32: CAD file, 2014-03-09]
headset/src/simulation_src/simulations/pacman/models/ghost.obj
2.00 x 2.00 x 2.83

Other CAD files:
headset/src/simulation_src/simulations/pacman/models/cube.obj
headset/src/simulation_src/simulations/pacman/models/cube.blend
headset/src/simulation_src/simulations/pacman/models/ghost.blend
headset/src/simulation_src/simulations/pacman/models/pellet.blend
headset/src/simulation_src/simulations/trees/models/tree.blend

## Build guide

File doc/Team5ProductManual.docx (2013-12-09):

# Homework 13: User Manual

# Team Code Name: _____Augmented Reality Simulator___________ Group No. __5__

# User Manual Outline:

Include this sheet as a cover page for your report

# Brief (marketing-style) product description

# Product illustration annotated with callouts for each control/display

# Product setup instructions

# Product use instructions

# Product troubleshooting instructions

# Evaluation:

SEC | DESCRIPTION | MAX | SCORE
1.0 | Product description | 20
2.0 | Product illustration | 20
3.0 | Product setup instructions | 20
4.0 | Product use instructions | 20
5.0 | Product troubleshooting instructions | 20
| TOTAL | 100

# 1.0 Product Description

# 1.0 Product description

The Augmented Reality Simulator is a headset device that will immerse you into a virtual world on top of your own reality. The device features a partially reflective screen that maximizes your ability to see and be aware of your surroundings. The headset is adjustable for a perfect fit to your head and balances weight on the front and back for maximum comfort. The lithium ion battery supplies as much as 4hrs of battery life for maximum play time. A battery indicator and wireless signal indicator will let you know when your battery gets low and the quality of your wireless signal. A Central Control Unit communicates the state of the simulation wirelessly to the headset. The device is designed to run a variety of augmented reality simulations that you may choose and swap out.

The Augmented Reality Simulator comes built in with a Pacman simulation based on the popular 2d Pacman game. The simulation brings Pacman to a whole new level. You are Pacman as you physically run away from ghosts and hurry to collect all of the pellets in the maze. Be sure to make full use of your ability to look around on all axis by simply tilting your head as you normally would! To collect pellets, you must pass through them. Try not to run into the walls! If you collide with a ghost, then you will lose the round and you must try again. Good luck collecting pellets!

# 2.0 Illustration

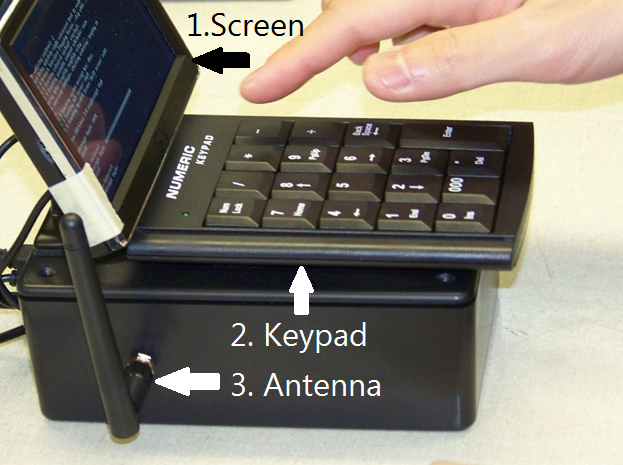
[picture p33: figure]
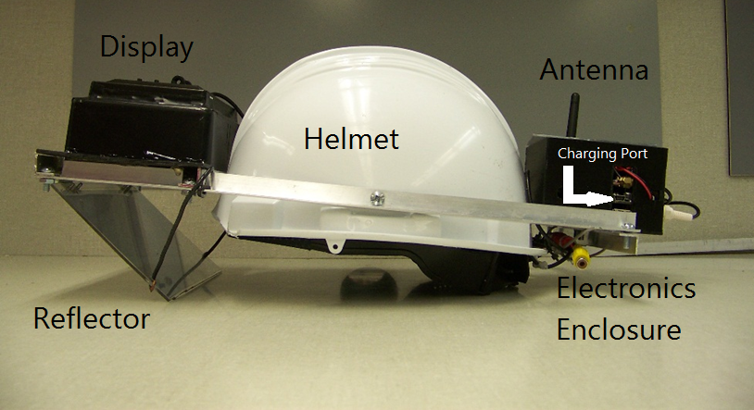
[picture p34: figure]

Power Switch

# 1. Keypad – Use the keypad to interact with the Central Control Unit.

# 2. Screen – Use the screen to receive feedback from the Central Control Unit.

# 3. Antenna – The antenna is used to communicate with the headset. Do not remove.

# 4. Helmet – The helmet provides a secure mounting framework and comes with an adjustable strap.

# 5. Display – The display projects the image seen on the reflector.

# 6. Reflector – Reflects the image from the display.

# 7. Antenna – The headset antenna is used to communicate with the Central Control Unit.

# 8. Charging port – Plug a USB cable in the charging port and the computer to charge the headset’s battery. A battery charging LED will turn on.

# 9. Electronics Enclosure – The black box at the back of the headset containing the GPS and other important electronic devices.

# 10. Power Switch – Turn power on for headset device.

# 3.0 Product Setup Instructions

# Find a location to play:

# Find a location outside to play, preferably a big open field with a building nearby that has an outlet on the outside. If necessary, acquire a long extension cord that can stretch into the field.

# Turn on the Devices:

# Plug the Central Control Unit in to turn it on. Flip the switch on the back of the headset to turn it on as well. Wait until there is a red flashing light on the board in the back of the headset. This indicates that the Global Positioning System is ready.

# Initial Configuration:

# Wait for a screen on the Central Control Unit that looks like the following:

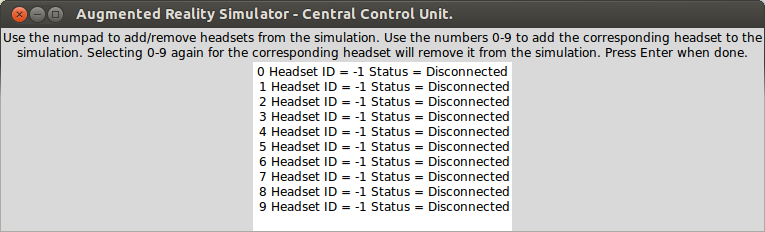
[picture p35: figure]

# Press “Enter” on the numeric pad to continue to the next screen that looks like the following:

Wait for the Central Control Unit to detect a headset. If no headset is detected, please refer to the troubleshooting section. When the Central Control Unit detects a headset, press “0” to select the headset. Multiple headsets are not currently supported. You may continue by pressing “Enter” on the numeric pad.

# Press “1” on the numeric keypad to initialize the Pac-Man simulation. The plus and minus keys only work when there are more simulations than can be displayed on one screen. Press “Enter” to continue or “Backspace” to go back to the previous screen and re-select your headset.

# The next screen will start your simulation which will appear on the headset. You may press “Backspace” at any time to quit the simulation and return to the headset selection screen.

# 4.0 Product Use Instructions

# 4.1 Looking Around

# To see the Pacman maze around you, simply turn or tilt your head in the desired direction and the display in front of your eyes will update to include what is visible in the virtual environment in the direction you are looking.

# 4.2 Moving

# To make an object become larger and closer to you, simply walk towards that object. To make an object become farther away, walk away from the object. You may walk in any direction. Note that walking towards an object will not work indoors; it must be done outdoors because GPS will not work indoors.

# 4.3 Interacting with Objects

The only way to interact with virtual objects is to walk towards them until they seem to be so close that you could touch them. Because the objects are virtual, you may go through them. The Pacman simulation does not make use of the ability of the user to interact with objects. When you pass through a pellet, it will remain in its location. DO NOT walk into real objects. Always make sure the object being walked through is virtual before proceeding.

# WARNING: DO NOT USE THE HEADSET IF YOU HAVE A HISTORY OF EPILEPSY.

# DO NOT CONTINUE USE OF DEVICE IF IT CAUSES VISUAL DISCOMFORT.

# 5.0 Product Troubleshooting Instructions

# Problem: Headset display is blank.

# Potential Solutions: Try flipping the switch on the back of the headset to turn on the power. If this does not work, then make sure that the battery is charged.

# Problem: The headset does not respond to the CCU.

# Potential Solutions: The maximum range for the CCU to communicate with the headset is approximately 200 meters. If the headset does not respond to the CCU as expected, try moving the headset closer to the CCU. Ensure that all antennas are oriented pointing upwards. If possible, elevate the CCU.

# Problem: Objects do not move closer or farther away when walking towards them or away from them.

# Potential Solutions: GPS will not work indoors. Go outdoors and wait for a blinking red light in the Electronics Enclosure. If this still does not work, then the atmospheric conditions may be interfering with the GPS.

# Problem: Objects on the screen are hard to see.

# Potential Solutions: If the objects are too hard to see, then there may be too much light polluting the display. Either play later in the evening or earlier in the morning to avoid light from the sun washing out the image.

# Problem: No objects are moving. A static screen is being displayed.

# Potential Solutions: Occasionally the device may “lock up”. This may be due to a variety of reasons. If this occurs, turn the headset off. Remove the SD card from the headset, ensure that it is seated, and turn the headset back on.

# Problem: The CCU display is black.

# Potential Solutions: Make sure that the CCU is plugged into an outlet and that the outlet is powered.

# Problem: The CCU display flashes and then comes back.

# Potential Solutions: This is a problem with the power provided to the display. The device will continue to function despite the display inconvenience.

# Problem: The display for the headset is spinning or moves in an unexpected fashion

# Potential Solutions: This may be due to a variety of reasons. If this occurs, turn the headset off. Remove the SD card from the headset, ensure that it is seated, and turn the headset back on.

ECE 477 Digital Systems Senior Design Project Rev 9/12

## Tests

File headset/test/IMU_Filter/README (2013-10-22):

The I2C driver here was written (by me) for the STM32F1 (LeafLabs Maple) and was ported with a
couple of lines changed.

It boots my STM32F4 discovery using Yagarto (http://sourceforge.net/projects/yagarto)
on windows arm-none-eabi-gcc 4.7.1:

Configured with: ../gcc-4.7.1/configure --target=arm-none-eabi --prefix=/home/ya
garto/install --disable-shared --disable-nls --disable-threads --disable-libssp
--disable-libstdcxx-pch --disable-libmudflap --disable-libgomp -v --enable-langu
ages=c,c++ --enable-interwork --enable-multilib --with-gcc --with-gnu-ld --with-
gnu-as --with-dwarf2 --with-newlib --with-headers=../newlib-1.20.0/newlib/libc/i
nclude --with-mpc=/home/yagarto/addontools --with-mpfr=/home/yagarto/addontools
--with-gmp=/home/yagarto/addontools
Thread model: single
gcc version 4.7.1 (GCC)

You will need to install the ST-Link drivers and utility to get code onto the board. 
The stlink.mk file will need to be copied from "STM32Booter" and edited locally to point to the
right path.

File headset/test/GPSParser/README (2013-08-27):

This code is NOT for the STM 32 Discovery or any production models. This code compiles and runs
on an Arduino clone known as the LeafLabs Maple (http://www.leaflabs.com) using a STM32F103
series chip (Cortex M3). However, it is straight C and the parser is portable to other models
of GPS or compiler.

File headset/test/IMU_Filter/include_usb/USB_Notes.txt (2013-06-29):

How to use USB:

1) Grab a USB configuration file from the Discovery firmware example and modify as needed.
2) Define USE_OTG_MODE, USE_USB_OTG_FS, and USE_HOST_MODE if host
3) Grab the device/host functionality files required (and ONLY those) from the firmware package.

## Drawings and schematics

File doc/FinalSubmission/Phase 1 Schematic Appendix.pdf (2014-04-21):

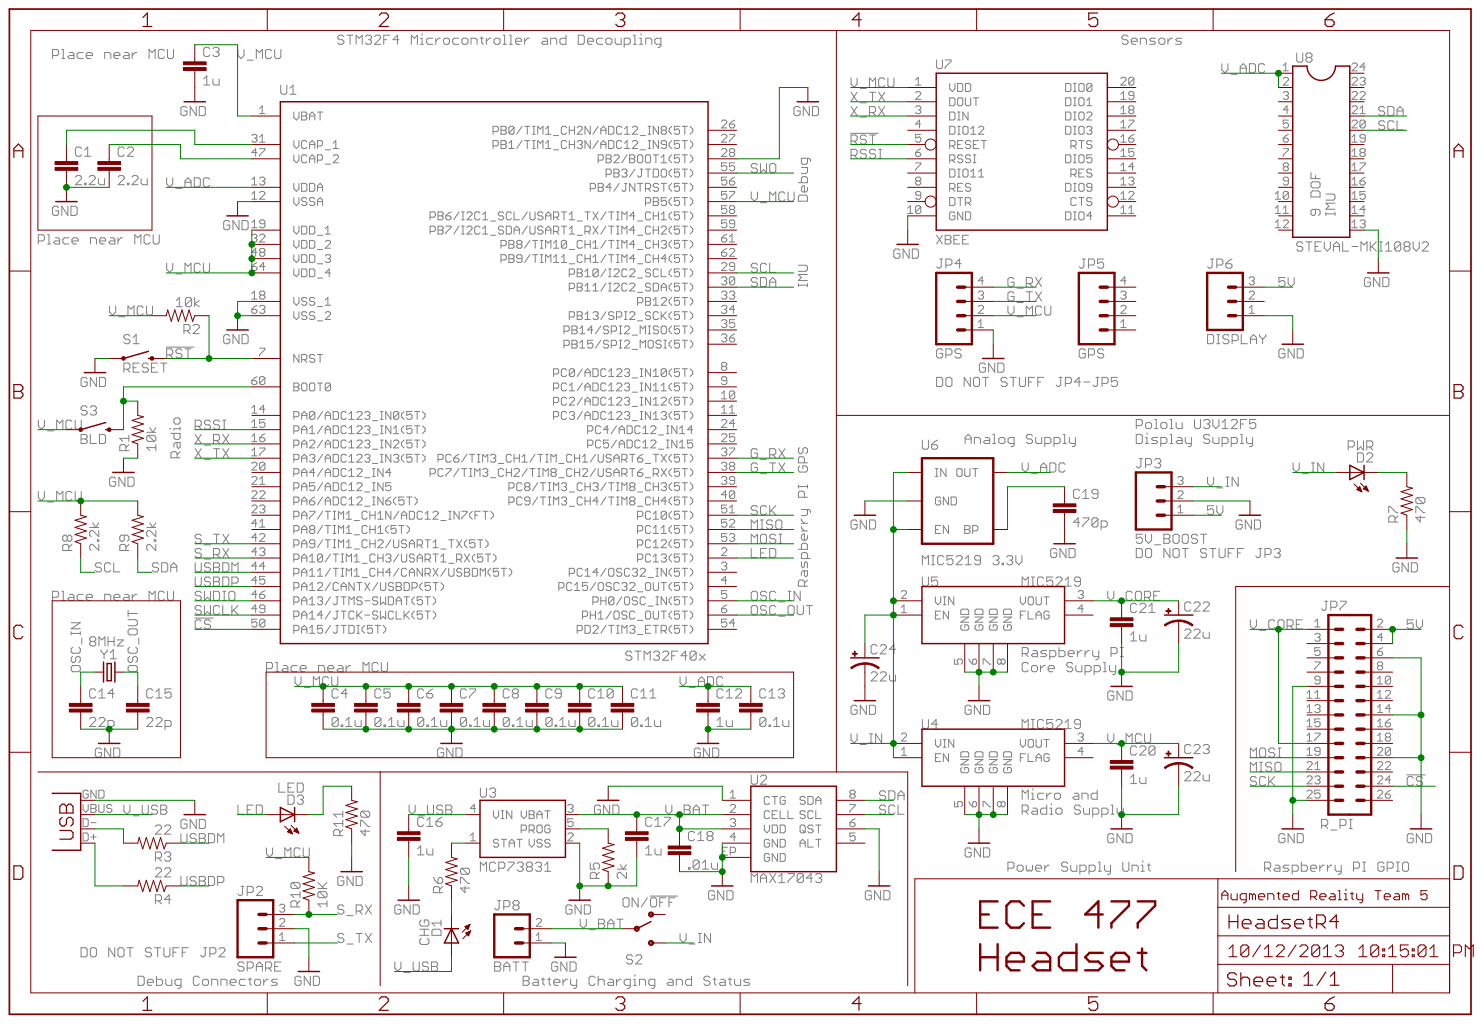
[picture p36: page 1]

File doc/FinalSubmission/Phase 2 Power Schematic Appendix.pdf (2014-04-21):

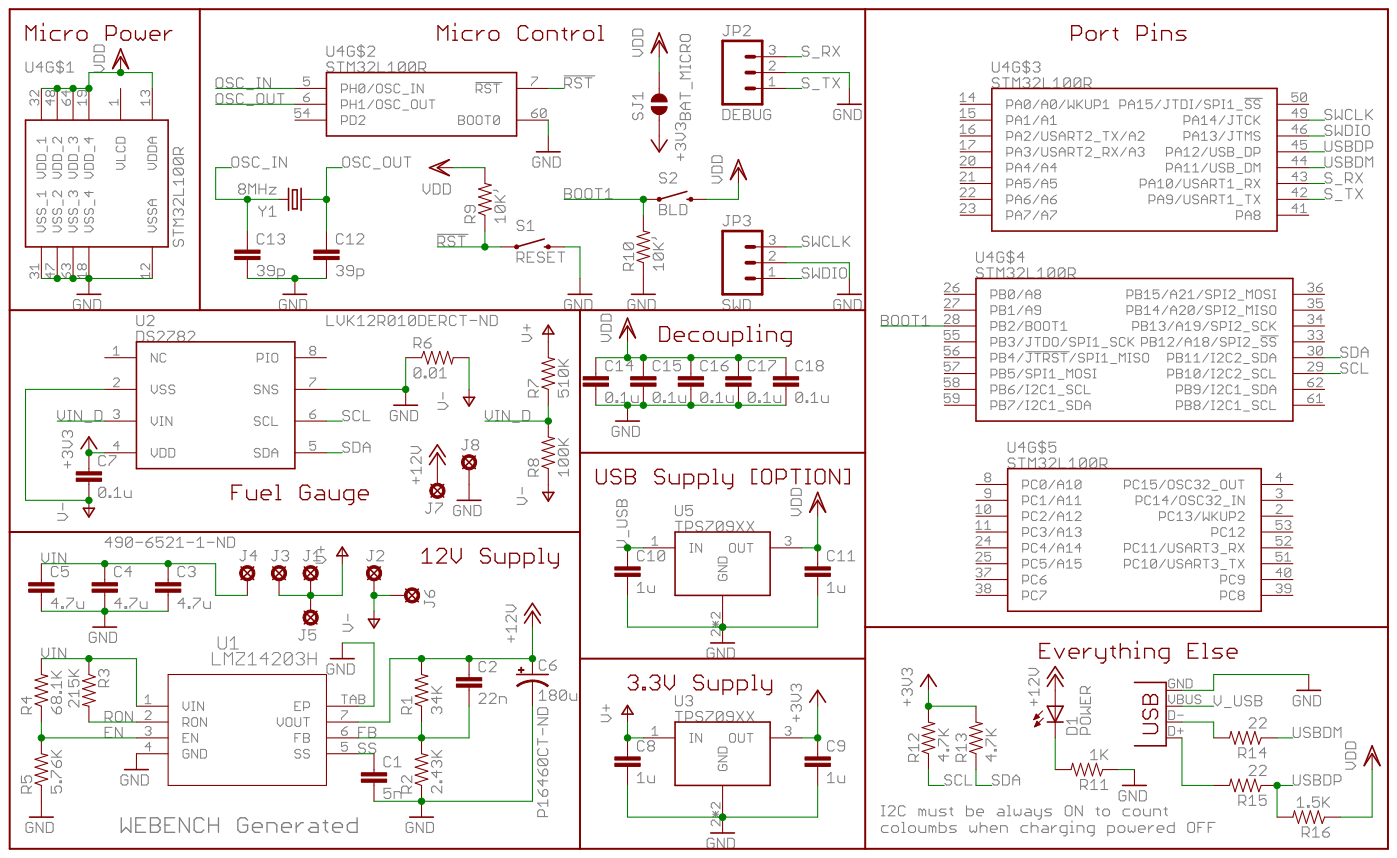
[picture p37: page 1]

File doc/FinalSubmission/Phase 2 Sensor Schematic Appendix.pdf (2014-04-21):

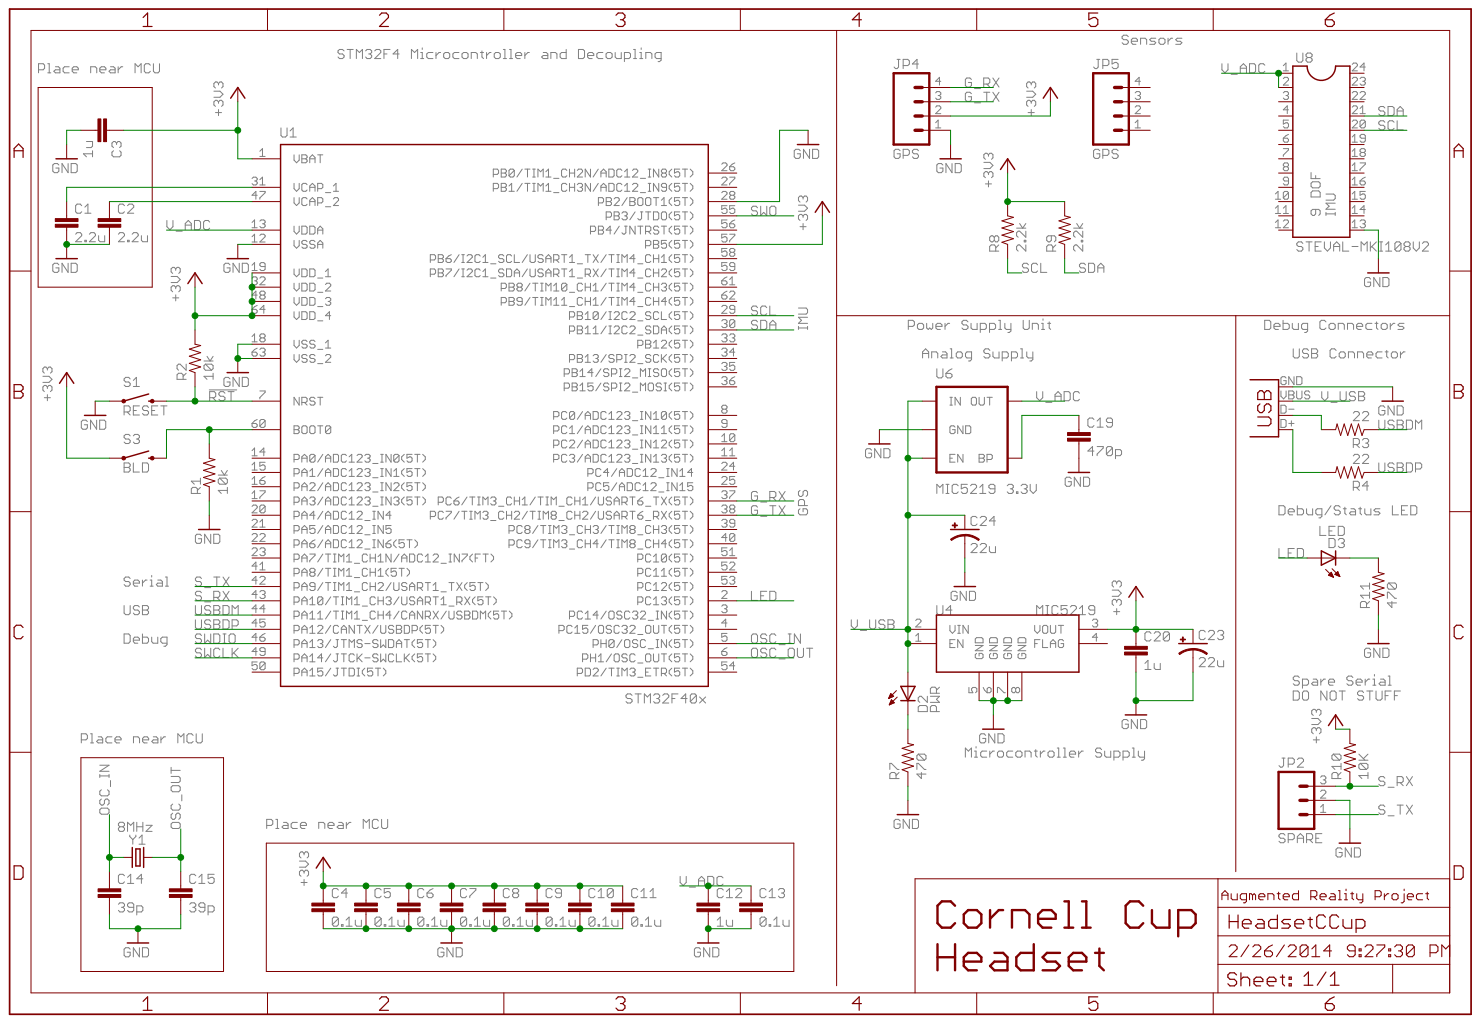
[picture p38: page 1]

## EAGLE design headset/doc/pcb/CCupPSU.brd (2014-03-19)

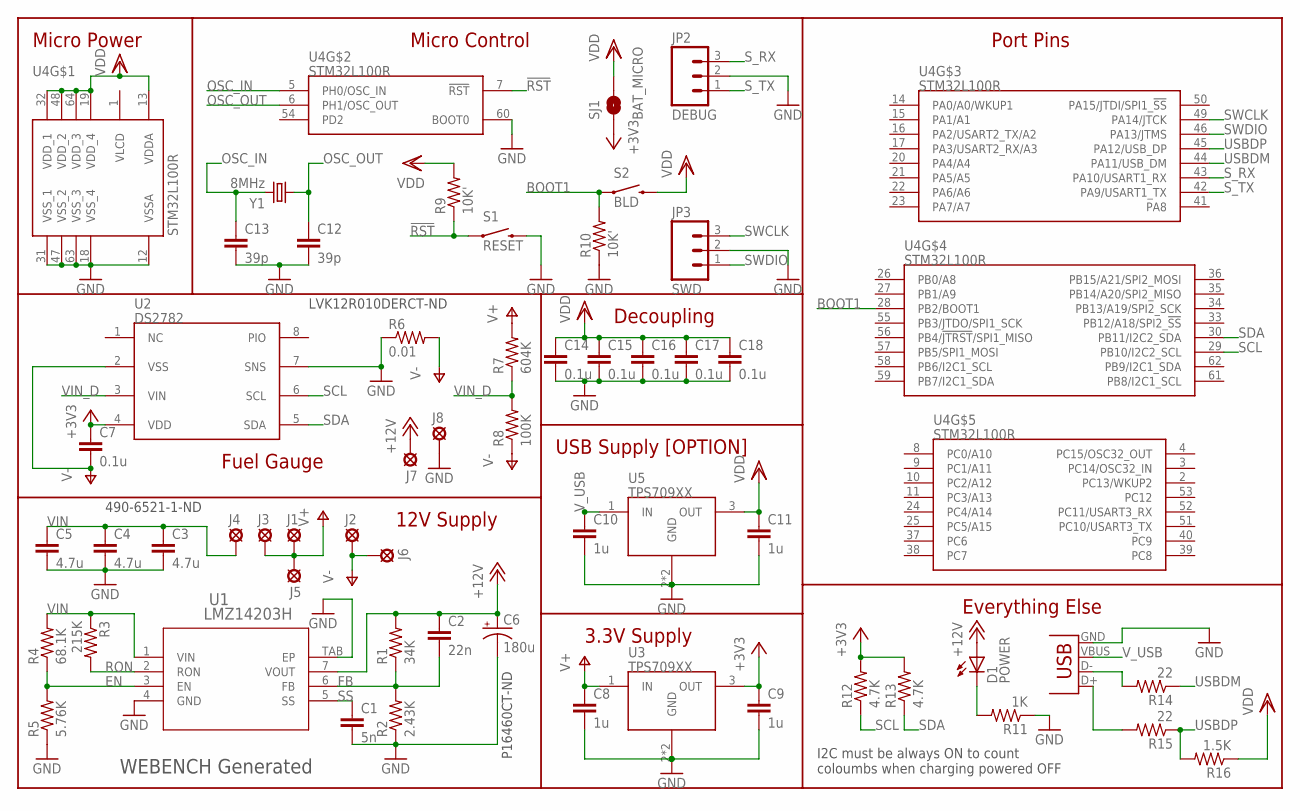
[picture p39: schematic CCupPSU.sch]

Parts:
C1: 5n; 1206
C2: 22n; 1206
C3, C4, C5: 4.7u; 1206
C6: 180u; PANASONIC_E
C7, C14, C15, C16, C17, C18: 0.1u; 1206
C8, C9, C10, C11: 1u; 1206
C12, C13: 39p; 1206
D1: POWER; LED-1206
J1, J2, J3, J4, J5, J6, J7, J8: SE14
JP1: USBSMD; USB-MINIB
JP2: DEBUG; 1X03
JP3: SWD; 1X03
R1: 34K; 1206
R2: 2.43K; 1206
R3: 215K; 1206
R4: 68.1K; 1206
R5: 5.76K; 1206
R6: 0.01; 1206
R7: 604K; 1206
R8: 100K; 1206
R9, R10: 10K'; 1206
R11: 1K; 1206
R12, R13: 4.7K; 1206
R14, R15: 22; 1206
R16: 1.5K; 1206
S1: RESET; TACTILE-PTH
S2: BLD; TACTILE-PTH
SJ1: BAT_MICRO; SJ_2S-TRACE
U1: LMZ14203H; TZA07A
U2: DS2782; TSSOP8
U3, U5: TPS709XX; SOT223
U4: STM32L100R; TQFP64
Y1: 8MHz; HC49US

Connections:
!RST!: R9.1, S1.1, U4.7 (!RST!)
+3V3: C7.1, C9.1, R12.2, R13.2, SJ1.1, U2.4 (VDD), U3.3 (OUT)
+12V: C2.1, C6.+, D1.A, J7.MP, R1.2, U1.7 (VOUT)
BOOT1: R10.2, S2.1, U4.28 (PB2/BOOT1)
EN: R4.1, R5.2, U1.3 (EN)
FB: C2.2, R1.1, R2.2, U1.6 (FB)
GND: C1.2, C3.2, C4.2, C5.2, C6.-, C8.2, C9.2, C10.2, C11.2, C12.2, C13.2, C14.2, C15.2, C16.2, C17.2, C18.2, J8.MP, JP1.GND, JP2.2, JP3.2, R2.1, R5.1, R6.1, R10.1, R11.1, S1.3 (2), U1.4 (GND), U1.TAB (EP), U2.7 (SNS), U3.2 (GND), U3.4 (GND), U4.12 (VSSA), U4.18 (VSS_4), U4.31 (VSS_1), U4.47 (VSS_2), U4.60 (BOOT0), U4.63 (VSS_3), U5.2 (GND), U5.4 (GND)
OSC_IN: C13.1, U4.5 (PH0/OSC_IN), Y1.2
OSC_OUT: C12.1, U4.6 (PH1/OSC_OUT), Y1.1
PLED: D1.C, R11.2
RON: R3.2, U1.2 (RON)
SCL: R12.1, U2.6 (SCL), U4.29 (PB10/I2C2_SCL)
SDA: R13.1, U2.5 (SDA), U4.30 (PB11/I2C2_SDA)
SS: C1.1, U1.5 (SS)
SWCLK: JP3.3, U4.49 (PA14/JTCK)
SWDIO: JP3.1, U4.46 (PA13/JTMS)
S_RX: JP2.3, U4.43 (PA10/USART1_RX)
S_TX: JP2.1, U4.42 (PA9/USART1_TX)
USBDM: R14.1, U4.44 (PA11/USB_DM)
USBDP: R15.1, R16.2, U4.45 (PA12/USB_DP)
USB_D+: JP1.D+, R15.2
USB_D-: JP1.D-, R14.2
V+: C8.1, J1.MP, J3.MP, J5.MP, R7.2, U3.1 (IN)
V-: C7.2, J2.MP, J6.MP, R6.2, R8.1, U2.2 (VSS)
VDD: C11.1, C14.1, C15.1, C16.1, C17.1, C18.1, R9.2, R16.1, S2.3 (2), SJ1.2, U4.13 (VDDA), U4.19 (VDD_4), U4.32 (VDD_1), U4.48 (VDD_2), U4.64 (VDD_3), U5.3 (OUT)
VIN: C3.1, C4.1, C5.1, J4.MP, R3.1, R4.2, U1.1 (VIN)
VIN_D: R7.1, R8.2, U2.3 (VIN)
V_USB: C10.1, JP1.VBUS, U5.1 (IN)

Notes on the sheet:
490-6521-1-ND
P16460CT-ND
12V Supply
WEBENCH Generated
LVK12R010DERCT-ND
3.3V Supply
Fuel Gauge
USB Supply [OPTION]
Micro Power
Micro Control
Decoupling
Port Pins
I2C must be always ON to count coloumbs when charging powered OFF
Everything Else

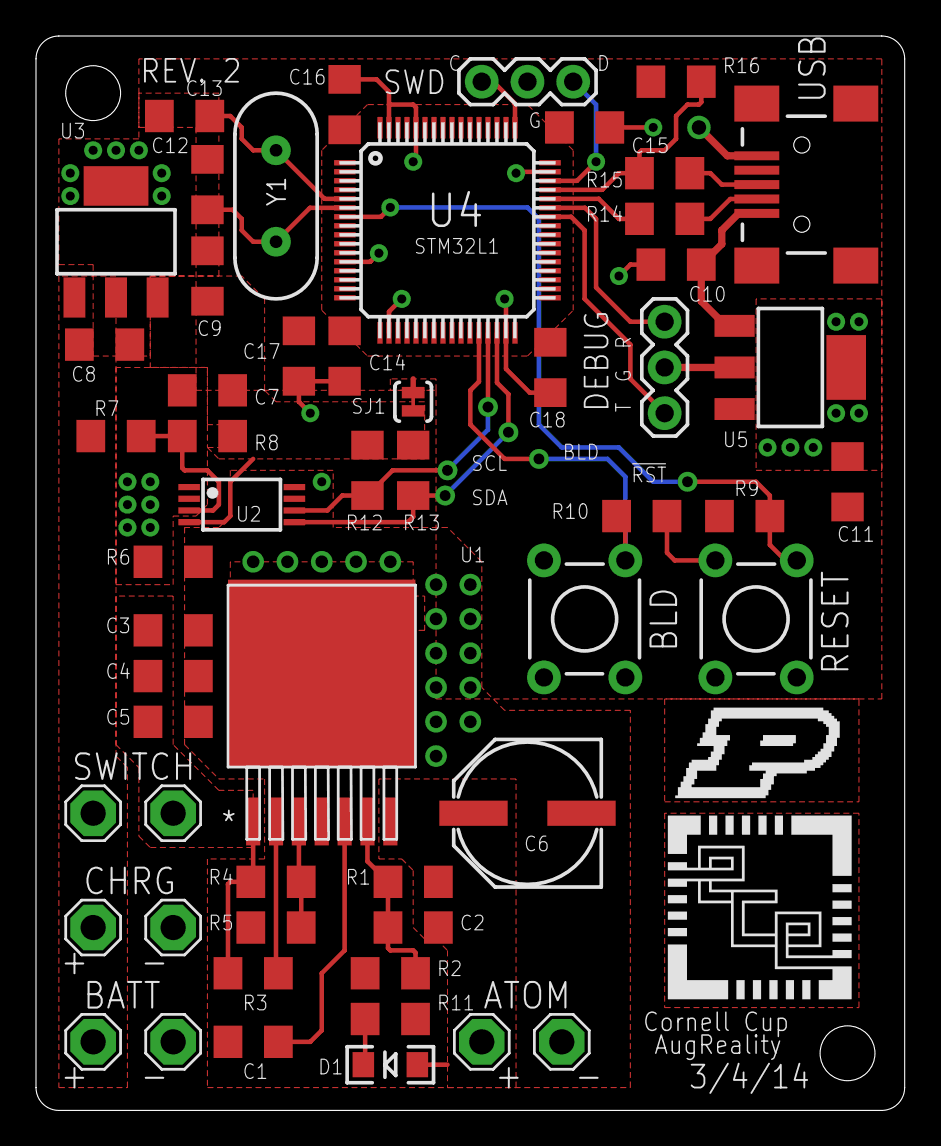
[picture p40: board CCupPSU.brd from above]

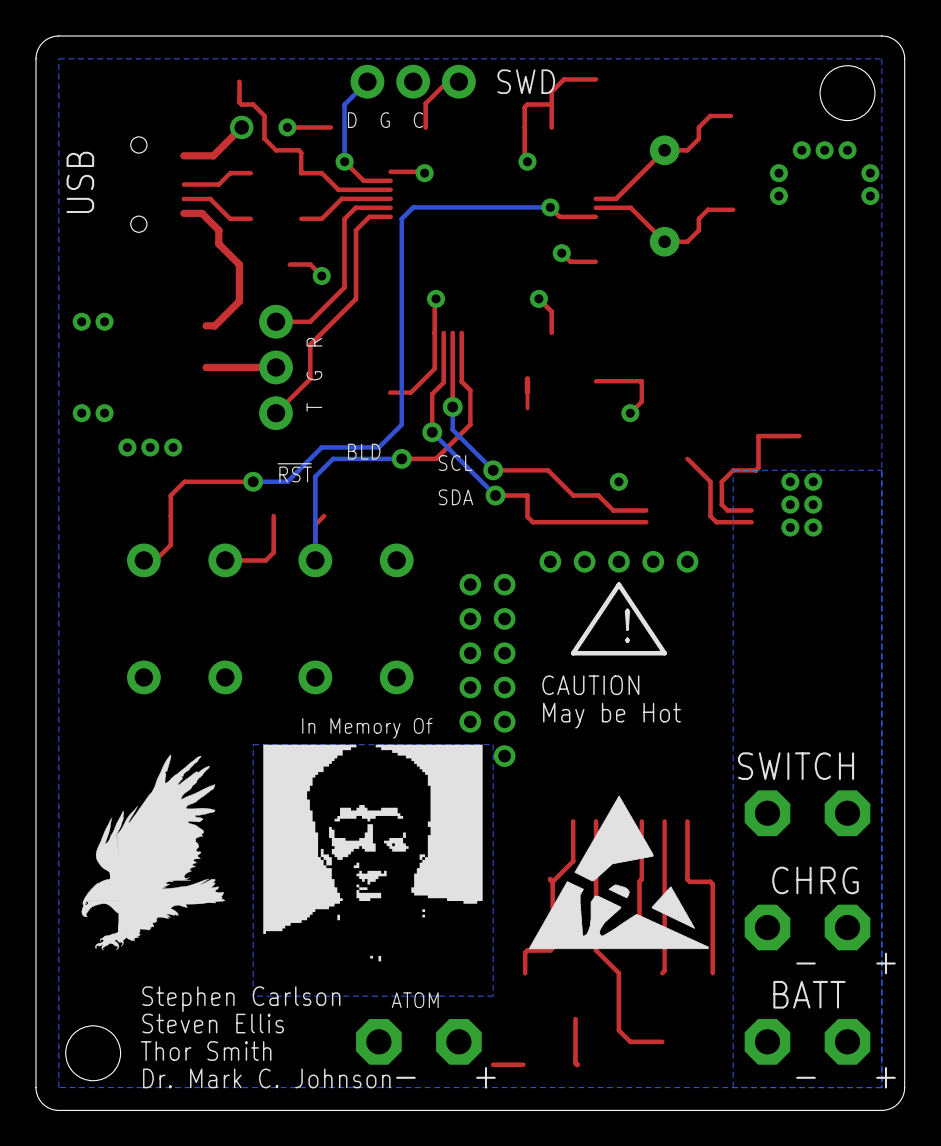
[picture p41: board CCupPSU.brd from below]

Board: 2 copper layers, 48.3 x 59.7 mm, 57 parts (2 on the bottom side), 28 nets.

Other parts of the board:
U$1: ESD_10.00
U$2: EAGLE-PLC-8MM

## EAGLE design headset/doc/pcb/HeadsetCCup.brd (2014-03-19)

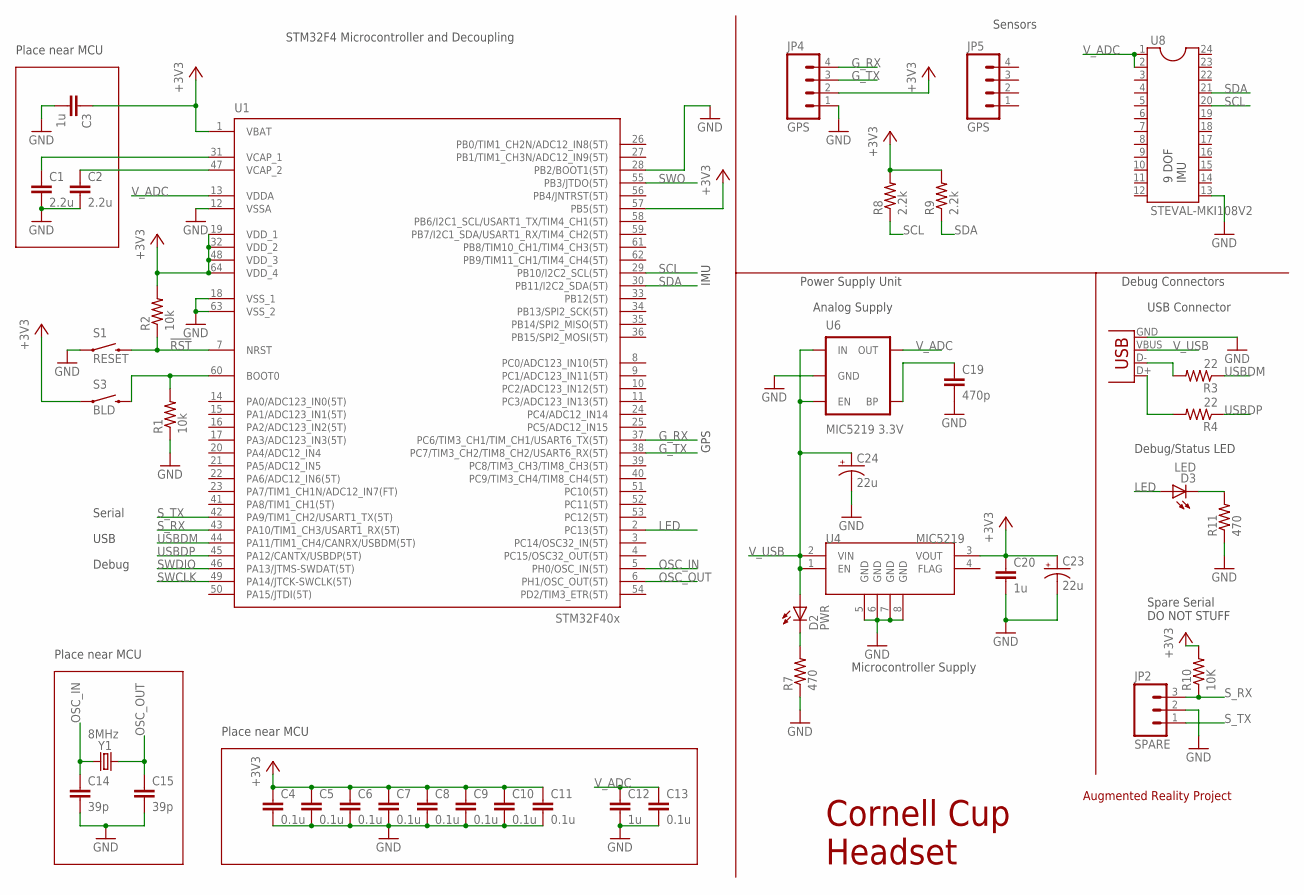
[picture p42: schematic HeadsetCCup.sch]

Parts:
C1, C2: 2.2u; 1206
C3, C12, C20: 1u; 1206
C4, C5, C6, C7, C8, C9, C10, C11, C13: 0.1u; 1206
C14, C15: 39p; 1206
C19: 470p; 1206
C23, C24: 22u; PANASONIC_D
D2: PWR; LED-1206
D3: LED; LED-1206
JP1: USBSMD; USB-MINIB
JP2: SPARE; 1X03
JP4, JP5: GPS; 1X04
R1, R2: 10k; 1206
R3, R4: 22; 1206
R7, R11: 470; 1206
R8, R9: 2.2k; 1206
R10: 10K; 1206
S1: RESET; TACTILE-PTH
S3: BLD; TACTILE-PTH
U1: STM32F405RGT6; TQFP64
U4: MIC5219; MSOP8
U6: MIC5219 3.3V; SOT23-5
U8: STEVAL-MKI108V2; DIL24-6
Y1: 8MHz; HC49US

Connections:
!RST!: R2.1, S1.3 (2), U1.7 (NRST)
+3V3: C3.1, C4.1, C5.1, C6.1, C7.1, C8.1, C9.1, C10.1, C11.1, C20.1, C23.+, JP4.2, R2.2, R8.2, R9.2, R10.2, S3.1, U1.1 (VBAT), U1.19 (VDD_1), U1.32 (VDD_2), U1.48 (VDD_3), U1.57 (PB5(5T)), U1.64 (VDD_4), U4.3 (VOUT)
BOOT0: R1.2, S3.3 (2), U1.60 (BOOT0)
GND: C1.2, C2.2, C3.2, C4.2, C5.2, C6.2, C7.2, C8.2, C9.2, C10.2, C11.2, C12.2, C13.2, C14.2, C15.2, C19.2, C20.2, C23.-, C24.-, JP1.GND, JP2.2, JP4.1, R1.1, R7.1, R11.1, S1.1, U1.12 (VSSA), U1.18 (VSS_1), U1.28 (PB2/BOOT1(5T)), U1.63 (VSS_2), U4.5 (GND), U4.6 (GND), U4.7 (GND), U4.8 (GND), U6.2 (GND), U8.13
G_RX: JP4.4, U1.37 (PC6/TIM3_CH1/TIM_CH1/USART6_TX(5T))
G_TX: JP4.3, U1.38 (PC7/TIM3_CH2/TIM8_CH2/USART6_RX(5T))
LED: D3.A, U1.2 (PC13(5T))
LED_LED: D3.C, R11.2
OSC_IN: C14.1, U1.5 (PH0/OSC_IN(5T)), Y1.1
OSC_OUT: C15.1, U1.6 (PH1/OSC_OUT(5T)), Y1.2
PWR_LED: D2.C, R7.2
SCL: R8.1, U1.29 (PB10/I2C2_SCL(5T)), U8.20
SDA: R9.1, U1.30 (PB11/I2C2_SDA(5T)), U8.21
SWCLK: U1.49 (PA14/JTCK-SWCLK(5T))
SWDIO: U1.46 (PA13/JTMS-SWDAT(5T))
SWO: U1.55 (PB3/JTDO(5T))
S_RX: JP2.3, R10.1, U1.43 (PA10/TIM1_CH3/USART1_RX(5T))
S_TX: JP2.1, U1.42 (PA9/TIM1_CH2/USART1_TX(5T))
USBDM: R3.1, U1.44 (PA11/TIM1_CH4/CANRX/USBDM(5T))
USBDP: R4.1, U1.45 (PA12/CANTX/USBDP(5T))
USB_D+: JP1.D+, R4.2
USB_D-: JP1.D-, R3.2
VCAP1: C1.1, U1.31 (VCAP_1)
VCAP2: C2.1, U1.47 (VCAP_2)
V_ADC: C12.1, C13.1, U1.13 (VDDA), U6.5 (OUT), U8.1, U8.2
V_BYP: C19.1, U6.4 (BP)
V_USB: C24.+, D2.A, JP1.VBUS, U4.1 (EN), U4.2 (VIN), U6.1 (IN), U6.3 (EN)

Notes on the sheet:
Place near MCU
STM32F4 Microcontroller and Decoupling
Debug Connectors
Microcontroller Supply
Analog Supply
Power Supply Unit
Sensors
Augmented Reality Project
Cornell Cup Headset
IMU
GPS
Serial
9 DOF IMU
Spare Serial DO NOT STUFF
USB Connector
Debug/Status LED
USB
Debug

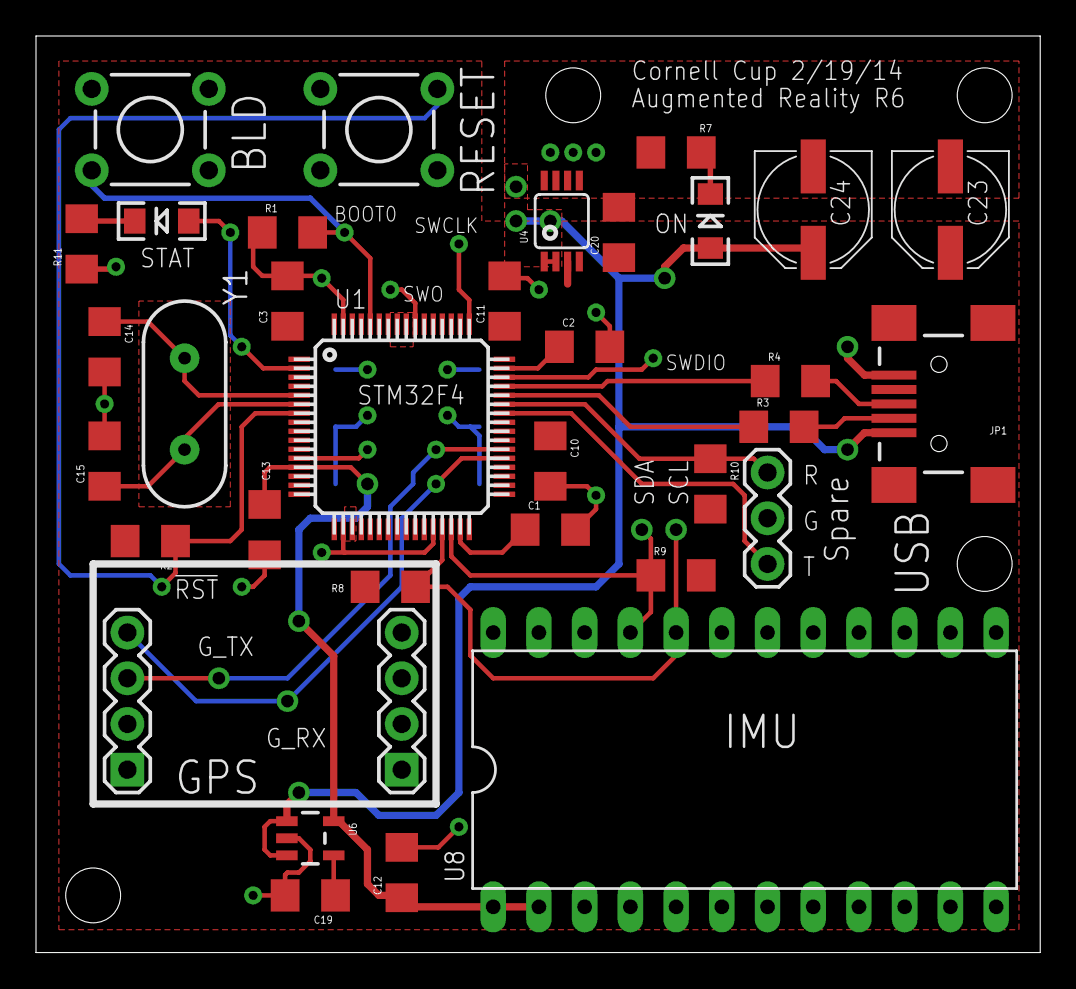
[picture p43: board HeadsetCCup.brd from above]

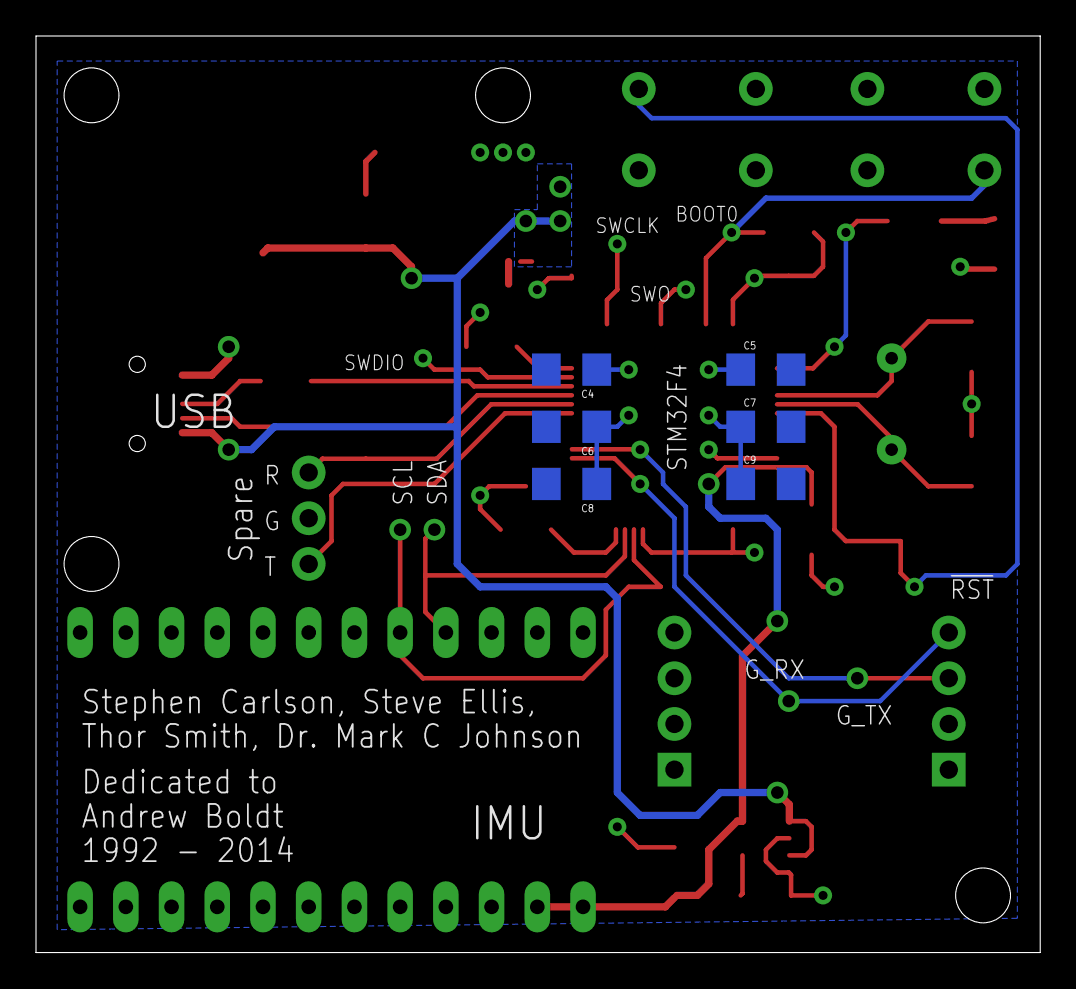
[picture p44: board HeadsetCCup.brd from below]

Board: 2 copper layers, 55.8 x 50.9 mm, 41 parts (6 on the bottom side), 24 nets.

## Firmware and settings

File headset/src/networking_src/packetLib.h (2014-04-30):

// File: packetLib.h
// Contains the definition of the
// packets exchanged wirelessly. The
// header and crc data will be added later.
#ifndef PACKETLIB_H
#define PACKETLIB_H
#include "packets.h"
#include <time.h>
#include <vector>

// Constants
#define DEFAULT_TCP_PORT 7788
#define DEFAULT_UDP_PORT 7789
#define HEADSETNAMESIZE 32

enum headsetState
{
	INIT = 0, 		// Transition to BROADCAST on setting client or HOSTSIMULATION on server start.
	BROADCAST, 		// Transition to ACCEPTED on receipt of Accept packet
	ACCEPTED, 		// Transition to SIMULATION on receipt of Start Packet
	SIMULATION, 	// Transition to INIT on receipt of End Packet
	HOSTSIMULTION // the host of a simulation doesn't need to send a heartbeat.
};

/**
* @brief heartBeatInfo used to keep track of
*		 information retrieved from a heart beat
*		 packet.
*/
typedef struct heartBeatInfo
{
	uint32_t ipAddr; 			// Ip address of headset
	float lat,lon;					// absolute lat/lon coordinates of player.
	float x,y;              // coordinates of player
	float roll,pitch,yaw;   // orientation of player
	time_t lastUpdate;
} heartBeatInfo_t;

// This is a supplementarty structure,
// not a packet. This packages the info
// for a headset's position.
typedef struct headsetPos
{
		float lat,lon;
    float x,y;              // coordinates of player
    float roll,pitch,yaw;   // orientation of player
} headsetPos_t;

// Functions
int packetLibInit();
int16_t getPos(headsetPos_t *pos, uint32_t id);
uint16_t getNumAlive();
uint16_t getAlive(uint32_t id);
int16_t getAliveIDs(uint32_t *ids, uint16_t size);
uint16_t addAliveID(uint32_t id);
int16_t updateObjs(objInfo_t *objList, uint32_t numObjects);
int16_t sendFile(char *filename, uint32_t id);
int16_t startSimulation();
int16_t getStartSimulation(int32_t connfd);
int16_t sendDropId(uint32_t destId);
int16_t getDropId(int32_t connfd);
int16_t acceptID(uint32_t destId);
int16_t getAcceptID(int32_t connfd);
int16_t endSimulationID(uint32_t destId);
int16_t getEndSimulation(int32_t connfd);
int16_t getBroadCastingIDs(uint32_t *ids, uint16_t numIds);
uint16_t getNumBroadCasting();
void getHeartBeatPacket(void);
int checkForNewPackets(int fd1, int fd2);
int wirelessConnection();
int bindToTcpServer(uint16_t port);
int bindToUdpPort(int port);
int connectToServer(int port, uint32_t addr);
void sendUpdatePacket(int udpFd);
void sendBroadcast(int udpFd);
void sendHeartbeat(int udpFd);
void processPacket(int udpFd, int tcpFd, int connFd, uint32_t addr, int ret, int pType);
int32_t writeTcpByteStream(void *buf, uint32_t size);
int32_t writeUdpByteStream(void *msg, uint32_t size, uint32_t dest);
int32_t readTcpByteStream(void *buf, uint32_t size);
int32_t readUdpByteStream(void *buf, size_t size, uint32_t *addr, uint32_t peek = 0);
uint8_t detectUdpType(int fd);
uint8_t detectTcpType(int fd, int *connfd, uint32_t *clientAddr);
void getBroadCastPacket(void);
uint32_t getMyId();
uint32_t getState();
void setState(uint32_t state);
uint32_t setHostHeadset(int32_t host);
uint32_t getFileReceived();
void getReceivedFile(char *filename, int size);
int16_t getUpdateObjs(std::vector<objInfo_t> &objs);

#endif

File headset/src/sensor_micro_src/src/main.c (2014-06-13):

/*
 * Cornell Cup 2014 - Augmented Reality Simulator
 *
 * Stephen Carlson
 * Steven Ellis
 * Thor Smith
 * Dr. Mark C. Johnson
 *
 * main.c - Sensor microcontroller source code
 */

#include "main.h"
#include "imu.h"
#include "printf.h"
#include "usb.h"
#include "core_cmInstr.h"
#include "nmea.h"

// Define number of bytes for headset updates to gpu.
#define HEADSETDATABYTES 24

// Time constants
#define ONE_SECOND 1000
#define HALF_SECOND 500
#define FIFTY_MSECOND 50

#define LATOFFSET 0
#define LONOFFSET 4
#define PITOFFSET 8
#define ROLOFFSET 12
#define YAWOFFSET 16
#define SATOFFSET 20

// GPS state machine for stream reading
static struct {
	char line[128];
	uint16_t len;
	uint16_t state;
} gpsState;

// Global Variables
static uint8_t __attribute__ ((aligned(4))) headsetData[HEADSETDATABYTES];

// IMU processing variables
#define IMU_HISTORY 5
#define filterCoeffIncr (2.f / (float)(IMU_HISTORY * IMU_HISTORY + IMU_HISTORY))
static uint32_t histIndex = 0;
#ifdef USE_COMPLEMENTARY_FILTER
static float gyroAccum = 0.0f;
#endif
static float pitchHist[IMU_HISTORY];
static float rollHist[IMU_HISTORY];
static float yawHist[IMU_HISTORY];

// Function declarations
static uint32_t gpsReadLine(char start, uint16_t length);
static void processGPSData(void);
static void processIMUData(void);
static void transmitData(void);

/**
 * System initialization
 */
static void init(void) {
	// Tick every 1ms
	SysTick_Config(168000);
	// Set up status LED
	gpioInit();
	// Set up the peripherals
	i2cInit();
	serialInit();
	usbVCPInit();
	// Enable interrupts for all peripherals
	__enable_fault_irq();
	__enable_irq();
}

/**
 * IMU filtering initialization
 */
static void imu9FilterInit(void) {
	// Zero history vectors
	for (uint32_t i = 0; i < IMU_HISTORY; i++) {
		pitchHist[i] = 0;
		rollHist[i] = 0;
		yawHist[i] = 0;
	}
}

// Function: main
// Starting point for all other functions.
int main(void) {
	// Sys init
	init();
	msleep(200L);
	// Initialize the IMU
	imu9Init();
	msleep(300L);
	imu9Calibrate();
	// Initialize IMU filtering
	imu9FilterInit();
	serialBufferClear();
	// main loop.
	while (1) {
		processGPSData();
		processIMUData();
		transmitData();
		__WFI();
	}
	return 0;
}

/**
* @brief Send the gps and imu data every 50 milliseconds over usb.
*/
static void transmitData(void) {
	static uint32_t count = 0;
	uint32_t bytesWritten = 0, i = 100;
	if (millis() > count + FIFTY_MSECOND) {
		ledToggle();
		count = millis();
		if (usbVCPConnected())
			// Write all bytes, even if buffer needs to evicted by the host
			do {
				bytesWritten += usbVCPWrite(headsetData + bytesWritten, HEADSETDATABYTES -
					bytesWritten);
			} while (bytesWritten < HEADSETDATABYTES && i-- > 0);
	}
}

// Reads a line from the GPS
static uint32_t gpsReadLine(char start, uint16_t length) {
	char c;
	while (fcount(gps) > 0) {
		c = fgetc(gps);
		if (gpsState.state == 0) {
			// Wait for start
			if (c == start) {
				gpsState.state = 1;
				gpsState.len = 0;
			}
		} else {
			// Increment length
			uint16_t len = gpsState.len;
			if (len >= (length - 1) || c == '\r' || c == '\n') {
				// END OF LINE!
				gpsState.line[len] = 0;
				gpsState.state = 0;
				return 1;
			} else
				gpsState.line[len] = c;
			gpsState.len = len + 1;
		}
	}
	return 0;
}

/**
 * GPS test function, reports new fixes to the serial port as they occur
 */
static void processGPSData(void) {
	float latf = 0, lonf = 0;
	// Try to parse the GPS
	if (gpsReadLine('$', sizeof(gpsState.line)) && gpsParse(gpsState.line)) {
		int lat = (int)gpsGetLatitude(), lon = (int)gpsGetLongitude();
		latf = (float)lat * 0.000001f;
		lonf = (float)lon * 0.000001f;
		// Stuff the buffer.
		*((float *)&headsetData[LATOFFSET]) = latf; // x pos
		*((float *)&headsetData[LONOFFSET]) = lonf; // y pos
		*((float *)&headsetData[SATOFFSET]) = (float)gpsGetSatellites(); // num satellites as a float.
	}
}

#ifdef USE_COMPLEMENTARY_FILTER
// Function: imuYawUpdate
// Purpose: Perform long-term moving average filtering on the
static float imuYawUpdate(float yaw) {
	uint32_t plusMinusPi = 0; float total = 0.0f;
	yawHist[histIndex] = yaw;
	// Ring buffer
	for (uint32_t i = 0; i < 4 * IMU_HISTORY; i++) {
		float value = yawHist[i];
		if (plusMinusPi == 0) {
			// Use this to correctly handle wraps around the singularity
			if (value > 0.7f) plusMinusPi = 1;
			else if (value < -0.7f) plusMinusPi = 2;
		} else {
			// Correctly handle wraps around +/- PI
			if (value < -0.7f && plusMinusPi == 1)
				value += (float)(2.0 * PI);
			if (value > 0.7f && plusMinusPi == 2)
				value -= (float)(2.0 * PI);
		}
		total += value;
	}
	// Return averaged value
	total = total * (1.0f / 16.0f);
	if (total < (float)-PI)
		total += (float)(2.0 * PI);
	else if (total > (float)PI)
		total -= (float)(2.0 * PI);
	return total;
}
#endif

// Function: processIMUData
// Purpose: Stuffs current IMU values in buffer
// so that they can be sent to the GPU and over
// wireless to the CCU. This occurs every 16
// milliseconds.
// Rssi is also set to be sent through spi.
static void processIMUData(void) {
	// Processing variables
	vector g, a, m;
	float roll, pitch, yaw;
	// Timing related variables
	const uint32_t UPDATE_PERIOD_MS = 16;
	static unsigned long imuTimer = 0;
	unsigned long currentTime = millis();
	if (currentTime >= imuTimer + UPDATE_PERIOD_MS) {
		// Index history array
		uint32_t hist = histIndex;
		imuTimer = currentTime;
		imu9Read(&g, &a, &m);
		// Calculate variables
		pitch = a_pitch(&a);
		roll = a_roll(&a);
		yaw = m_pr_yaw(&m, pitch, roll, 0.0f);
#ifdef USE_COMPLEMENTARY_FILTER
		float gyroYaw, yawRate;
		// Get gyro rate angle in rad/s by multiplying by DT
		yawRate = g_pr_yaw(&g, pitch, roll) * (3.054326e-4f * (float)UPDATE_PERIOD_MS * 0.001f);
		// RNL and accumulate
		if (yawRate > -0.005f && yawRate < 0.005f) yawRate = 0.f;
		gyroYaw = gyroAccum + yawRate;
		// Adjust gyro yaw into range (-pi, pi)
		if (gyroYaw < (float)-PI)
			gyroYaw += (float)(2.0 * PI);
		else if (gyroYaw > (float)PI)
			gyroYaw -= (float)(2.0 * PI);
		// Compute actual yaw by rolling the gyro yaw accumulated total towards compass
		gyroYaw = gyroYaw - ((gyroYaw - yaw) * 0.008f);
		gyroAccum = gyroYaw;
		// Store in history
		pitchHist[hist] = pitch;
		rollHist[hist] = roll;
		yaw = imuYawUpdate(yaw);
		histIndex = (hist + 1) % IMU_HISTORY;
		// Calculate the average of the pitch, roll (4 samples)
		pitch = 0.0f;
		roll = 0.0f;
		for (uint32_t i = 0; i < IMU_HISTORY; i++) {
			pitch += pitchHist[i];
			roll += rollHist[i];
		}
		pitch *= 0.25f;
		roll *= 0.25f;
#else
		float yawOffset, yawTmp;
		// push back pitch/yaw/roll history
		for (uint32_t i = 0; i < IMU_HISTORY - 1; i++) {
			pitchHist[i] = pitchHist[i + 1];
			yawHist[i] = yawHist[i + 1];
			rollHist[i] = rollHist[i + 1];
		}
		// center yaw range around most recent yaw measurement
		// i.e. [yaw_recent-PI,yaw_recent+PI]
		// (assumes not more than PI differential from initial)
		yawOffset = yawHist[IMU_HISTORY - 1];
		for (uint32_t i = 0; i < IMU_HISTORY; i++) {
			pitch += pitchHist[i] * filterCoeffIncr * (float)(i + 1);
			roll += rollHist[i] * filterCoeffIncr * (float)(i + 1);
			yawTmp = yawHist[i] - yawOffset;
			if (yawTmp > PI) {
				yawTmp -= 2.f*PI;
			} else if (yawTmp < -PI) {
				yawTmp += 2.f*PI;
			}
			yaw += yawTmp * filterCoeffIncr * (float)(i + 1);
		}
		// convert yaw range back to [-PI,+PI]
		yaw += yawOffset;
		if (yawTmp > PI) {
			yawTmp -= 2*PI;
		} else if (yawTmp < -PI) {
			yawTmp += 2*PI;
		}
		// Store in history
		pitchHist[hist] = pitch;
		rollHist[hist] = roll;
		yawHist[hist] = yaw;
#endif
		const float oldRoll = roll;
		roll = -pitch;
		yaw = -yaw;
		pitch = -oldRoll;
		// Convert to degrees
#ifndef HARD_IRON_CAL
		*((float *) &headsetData[PITOFFSET]) = pitch * (180.f / (float)PI); // pitch
		*((float *) &headsetData[ROLOFFSET]) = roll * (180.f / (float)PI); // roll
		*((float *) &headsetData[YAWOFFSET]) = yaw * (180.f / (float)PI); // yaw
#else
		*((float *) &headsetData[PITOFFSET]) = m.x;
		*((float *) &headsetData[ROLOFFSET]) = m.y;
		*((float *) &headsetData[YAWOFFSET]) = m.z;
#endif
	}
}

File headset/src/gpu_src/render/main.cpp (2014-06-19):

#include <irrlicht.h>
#include <iostream>
#include <fstream>
#include "InputReceiver.cpp"
#include "GameObject.h"
#include "SensorReader.h"
#include "genLevel.h"
#include "gpuPyThreadInterface.h"
#include "../../networking_src/packets.h"

using namespace irr;
using namespace core;
using namespace scene;
using namespace video;
using namespace io;
using namespace gui;

#define SCREEN_WIDTH 1024
#define SCREEN_HEIGHT 768
#define SCREEN_FOV 3.14f/2.8f
#define MOVEMENT_SPEED 5.0f
#define CAMERA_SPEED 40.0f
#define PROCESS 1
#define HEADSET_VERSION

GameObject *objects;

#ifdef PROCESS
int main(int argc, char *argv[]) {
#else
int render(int argc, char *argv[]) {
#endif
	if (argc != 3) {
		std::cout << "usage: render configFile path/to/models\n";
		return -1;
	}
	
	char *configFileName = argv[1];
	char *modelsPath = argv[2];
	volatile bool quit = false;
	GpuPyThreadInterface pyInterface;
	pyInterface.initServer(&quit);
	int battery = 10;
	int signal = 0;
	int sats = 0;
	float fov = SCREEN_FOV;
	stringw orientString = "y: 0.0 p: 0.0 r 0.0";
	stringw fpsString = "FPS: ???";
	stringw posString = "x: 0.0 y: 0.0";
    //interfaces to other modules
#ifdef HEADSET_VERSION
    SensorReader sensor;
    sensor.initServer();
#endif

    //create the window
    InputReceiver receiver;
    IrrlichtDevice *device = createDevice( video::EDT_OPENGL, dimension2d<u32>(SCREEN_WIDTH, SCREEN_HEIGHT), 32, true, false, true, &receiver);

    //check for successful initialization of irrlicht
    if (!device) {
        return 1;
    }
    IVideoDriver* driver = device->getVideoDriver();
    ISceneManager* smgr = device->getSceneManager();
    IGUIEnvironment* guienv = device->getGUIEnvironment();
    GameObject::setSceneManager(smgr);

    //load level file
    objects = new GameObject[2096];
    writeConfigFile(configFileName, modelsPath);
    GameObject::loadConfigFile("tmp.cfg", objects);

    //add camera
    ICameraSceneNode* camera = smgr->addCameraSceneNode();
    ISceneNode* cameraTarget = smgr->addEmptySceneNode(camera);
    cameraTarget->setPosition(vector3df(1,0,0));
    ISceneNode* upTarget = smgr->addEmptySceneNode(camera);
    upTarget->setPosition(vector3df(0,0,1));
    camera->setFOV(SCREEN_FOV);
    device->getCursorControl()->setVisible(false);
    vector3df camerapos = camera->getPosition();
    vector3df camerarot = vector3df(0, 0, 0);
    //get font
    IGUIFont* font = device->getGUIEnvironment()->getBuiltInFont();

    //main render loop
    while(device->run() && !quit) {
        driver->beginScene(true,true, SColor(0,0,0,0));
        if(receiver.IsKeyDown(irr::KEY_BACK)) {
			quit = true;
		}
        if(receiver.IsKeyDown(irr::KEY_SUBTRACT)) {
			quit = true;
		}
        if(receiver.IsKeyDown(irr::KEY_ADD)) {
					fov += 0.1;
					std::cout << "Field of view: " << fov << std::endl;
		}
				if(receiver.IsKeyDown(irr::KEY_MULTIPLY)) {
					fov -= 0.1;
					std::cout << "Field of view: " << fov << std::endl;
				}

    camera->setFOV(fov);
        
        stringw str = L"FPS: ";
        str += driver->getFPS();
        device->setWindowCaption(str.c_str());
#ifndef HEADSET_VERSION
	if (receiver.IsKeyDown(irr::KEY_KEY_F))
		printf("FPS: %d\n", driver->getFPS());
#endif

        //keyboard camera control

        //move camera
        if(receiver.IsKeyDown(irr::KEY_KEY_A))
            camerapos -= camera->getUpVector().crossProduct((camera->getTarget() - camera->getPosition())) * MOVEMENT_SPEED / 60.0f;
        if(receiver.IsKeyDown(irr::KEY_KEY_D))
            camerapos += camera->getUpVector().crossProduct((camera->getTarget() - camera->getPosition())) * MOVEMENT_SPEED / 60.0f;
        if(receiver.IsKeyDown(irr::KEY_KEY_W))
            camerapos += (camera->getTarget() - camera->getPosition()) * MOVEMENT_SPEED / 60.0f;
        if(receiver.IsKeyDown(irr::KEY_KEY_S))
            camerapos -= (camera->getTarget() - camera->getPosition()) * MOVEMENT_SPEED / 60.0f;
				if(receiver.IsKeyDown(irr::KEY_KEY_R))
            camerapos.Z += MOVEMENT_SPEED / 60.0f;
        if(receiver.IsKeyDown(irr::KEY_KEY_F))
            camerapos.Z -= MOVEMENT_SPEED / 60.0f;

        //set camera roll
        if(receiver.IsKeyDown(irr::KEY_KEY_Q))
            camerarot.X -= CAMERA_SPEED / 60.0f;
        if(receiver.IsKeyDown(irr::KEY_KEY_E))
            camerarot.X += CAMERA_SPEED / 60.0f;

        //set camera pitch
        if(receiver.IsKeyDown(irr::KEY_UP))
            camerarot.Y -= CAMERA_SPEED / 60.0f;
        if(receiver.IsKeyDown(irr::KEY_DOWN))
            camerarot.Y += CAMERA_SPEED / 60.0f;

        //set camera yaw
        if(receiver.IsKeyDown(irr::KEY_LEFT))
            camerarot.Z -= CAMERA_SPEED / 60.0f;
        if(receiver.IsKeyDown(irr::KEY_RIGHT))
            camerarot.Z += CAMERA_SPEED / 60.0f;

        //update the actual camera
        
        #ifdef HEADSET_VERSION
        //sensor camera control
        camerarot = sensor.getOrientation();
        camerapos = sensor.getLocation();
        camera->setPosition(camerapos);
        camera->setRotation(camerarot);
        #else
        camera->setPosition(camerapos);
        camera->setRotation(camerarot);
		#endif

        camera->setTarget(cameraTarget->getAbsolutePosition());
        camera->setUpVector(upTarget->getAbsolutePosition() - camerapos);
        smgr->drawAll();
        //hud stuff
#ifdef HEADSET_VERSION
        battery = sensor.getBatteryStatus();
        signal = sensor.getWifiStatus();
        sats = sensor.getNumSatellites();
#endif
        orientString = stringw("r:") + stringw(camerarot.X) + stringw(" p:") + stringw(camerarot.Y) + stringw(" y:") + stringw(camerarot.Z);
        //sprintf(orientString, "r:%f p:%f y:%f", camerarot.X, camerarot.Y, camerarot.Z);
        posString = stringw("x:") + stringw(camerapos.X)
                    + stringw(" y:") + stringw(camerapos.Y);
        fpsString = stringw("FPS: ") + stringw(driver->getFPS());
	font->draw((sats > 1) ? L"gps locked" : L"gps unlocked", rect<s32>(20,10,300,50), SColor(255,255,255,255));
        font->draw(stringw("battery: ") + stringw(battery) + stringw("/10"), rect<s32>(20,20,300,50), SColor(255,255-(battery),battery,0));
        font->draw( signal ? L"wifi connected" : L"wifi disconnected.", rect<s32>(20,30,300,50), SColor(255,255-(signal),signal,0));
        font->draw(orientString, rect<s32>(20,40,300,50), SColor(255,255,255,255));
	font->draw(fpsString, rect<s32>(20,50,300,50), SColor(255,255,255,255));
	font->draw(posString, rect<s32>(80,60,300,50), SColor(255,255,255,255));
		//printf("\rX: %2.2f, Y: %2.2f, Orientation: %2.2f", camerapos.X, camerapos.Y, camerarot.Z);
        driver->endScene();
    }
    std::cout << "Rendering exit\n";
    device->drop();
    return 0;
}
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

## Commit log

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2013-08-27 Add GPS parser example code. Runs on Leaflabs maple, not discovery board, but essential part is portable.
2013-09-04 added presentation
    [xbeeConfig.txt]
2013-09-09 Add headset schematic revision #1, EAGLE libraries, and project library
    [HeadsetR1.brd, HeadsetR1.sch]
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2013-09-21 Add I2C and UART example, successfully decodes all 9 axes and reports some of them back over USART3 (can be changed by modifying the printf)
    Port connections:
    I2C SCL -> PB6
    I2C SDA -> PB9
    USART3 TX <- PB10
2013-09-27 Headset schematic and PCB revision 2
    [HeadsetR2.brd, HeadsetR2.sch]
2013-09-27 Update headset schematic revision 2 (again), almost ready for route
    [HeadsetR2.brd, HeadsetR2.sch]
2013-10-01 Update schematic revision 2 to fix the issues described in lab notebook
    [HeadsetR2.brd, HeadsetR2.sch]
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2013-10-05 updated xbee configurations.
    [xbeeConfig.txt]
2013-10-07 Added preliminary timeline for project completion. Tasks are divided up by topic and there are three sheets to the document based on how one wishes to view project completion.
    [Schedule.xlsx]
2013-10-08 Update headset PCB and schematic to hopefully the last version
    [HeadsetR3.brd, HeadsetR3.sch]
2013-10-09 Update headset and schematic to rotate XBee 180 degrees
    [HeadsetR4.brd, HeadsetR4.sch]
2013-10-09 Carlson updated pcb to add clearance on power planes.
    [HeadsetR4.brd]
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2013-10-13 Carlson touched up pcb and schematic
    [HeadsetR4.brd, HeadsetR4.sch]
2013-10-17 Added mounting hole to PCB
    [HeadsetR4.brd]
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2013-10-17 Update PCB to fix a DRC issue on vias
    [HeadsetR4.brd]
2013-10-22 Substantially cleaned up I2CExample, should work the same but is not tested
2013-10-23 Add battery fuel gauge monitoring driver, working to get voltage and SOC%, accuracy of SOC% needs to be tested
2013-10-24 Add old GPS test data (dates from beginning of semester) to repository
    [gps.csv, gps2.csv]
2013-10-26 Add data collected from a subset of a charging run of the fuel gauge IC
    [FuelGaugeData.xlsx]
2013-10-29 SPI Slave code working well, clean up code in a few other projects and add extended fuel gauge graph
    [FuelGaugeData.xlsx]
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2013-11-01 Update fuel gauge project to match I2C to the actual PCB specifications
2013-11-01 Add all-peripherals test code which exercises fuel gauge, XBee, Raspberry PI, GPS, and external serial. Add GPS test data taken from a campus run using the production hardware and GPS configuration u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
    [gps3.csv]
2013-11-04 Add RSSI driver to indicate signal strength, access via gpioGetRSSI()
    NOTE: The RSSI is only calculated when bytes are sent or received.
    Therefore, the RSSI value is only valid when bytes have been sent or
    received recently.
2013-11-04 Trim the leading garbage points from the GPS run #3 tracking data
    [gps3.csv]
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2013-11-06 Add IMU/I2C test exercise code to all peripherals test example (yes, it works)
2013-11-06 USB to Serial drivers are working, the USBtoSerial project has been cleaned up significantly
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2013-11-13 added spi functionality to send data from xbee to gpu. Not finished yet.
2013-11-13 Added a rule to ignore vim swp files in gitignore. Updated serialTest to print hex values sent through uart (to see binary data). Created send_file.c to test sending data from xbee through spi to gpu.
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2013-11-14 GPS rendering works! GPU code is on one of the raspberry pis.
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2013-11-17 added new rendering code with spi integration and model loader
    [pacman.obj, tetris.obj]
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2013-11-17 added fix for yaw.
    [imu.c]
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2013-11-17 Fixed imu merge to compile.
    [main.c]
2013-11-19 fix data size in comm and led setup.
    [comm.c, main.c]
2013-11-21 added new 3D models
    [ghost.obj, pellet.obj, wall.obj]
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2013-11-22 Attempted fix of USB to Serial drivers, but no go. Something is different between the test project and the actual headset project.
    [comm.c, main.c]
2013-11-24 Serial to USB should be fixed; printf() etc. properly output to debug
    [printf.h]
2013-11-25 fixed imu startup inconsistencies and added in-progress code for ccu.
    [comm.c, main.c]
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2013-11-25 Added initial filtering with the gyro, noise drastically reduced without transient response or drift problems, but need to properly rotate gyro into the world frame of reference
    [imu.c, main.c]
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2013-11-27 Merged spiReceivedByte function back in. Changed Makefile for headset to auto-generate the packets.h and packets.c file and add them to the directory. These auto-generated files were also added to th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
    [main.c]
2013-11-27 fixed spi get xbee data to return zero bytes at end.
    [main.c]
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2013-12-02 Added code to pass files, but there are problems where the spi data sent out to the gpu gets unexpected nonzero data bytes which are interpreted as the number of bytes for incoming data.
    [main.c]
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2013-12-03 fixed xbee read init
    [main.c]
2013-12-03 Alec made modifications in attempt to fix rotation issues found after filtering.
    [imu.c, main.c]
2013-12-04 Alec fixed imu filtering.
    [main.c]
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2013-12-04 can load config file for map
    [config.txt, wall.obj]
2013-12-04 pacman level
    [genconfig.txt, wall.obj]
2013-12-05 Several fixes to file transfer
    [imu.c, main.c]
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2013-12-06 fixed bug involving packetType already being read.
    [main.c]
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2013-12-06 Fixed packet receiving problem in main for start/end packets.
    [main.c]
2013-12-11 it actuallyl works
    [config.txt]
2014-02-06 Align headset data to word boundary to possibly fix mis aligned store issue
    [main.c]
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2014-02-10 Update mid review
    [Schedule.xlsx]
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2014-02-12 Added first PCB draft for Cornell Cup headset.
    [HeadsetCCup.brd, HeadsetCCup.sch]
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2014-02-19 fixed open files bug for packet daemon.
    [main.c]
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2014-03-09 added new rendering code for the atom board
    [config.txt, cube.blend, cube.obj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]
2014-03-11 new rendering stuff
    [config.txt, ghost.blend]
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2014-03-11 more reasonable pikachu size
    [pikachu.obj]
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2014-03-18 removed old ccu from phase2 project.
    [xbeeConfig.txt]
2014-03-19 Added thread for collecting gps/imu data. Modified sensor micro src so that it does not find an origin. This is easier because it makes serial traffic one-way. It was also discovered that the serial 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
    [main.c]
2014-03-19 Add the latest version of Cornell Cup PCBs to repository
    [CCupPSU.brd, CCupPSU.sch, HeadsetCCup.brd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]
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2014-03-24 new level files
    [config.txt]
2014-03-30 moved files to sim dir
    [cube.blend, cube.obj, ghost.blend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]
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2014-04-01 fixed data collection thread and added a little filtering on possible values.
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2014-04-04 Fix a few issues, power board still fails to boot
    [comm.c, main.c]
2014-04-05 Fixed numerous issues. USB on STM32L1 Works!!!
    Note that the ST LINK GUI does not reload binaries in the Program dialog! Fixed the common.mk to point to CLI flash utility to allow "make upload"
    [comm.c, main.c]
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2014-04-06 Add Steven Ellis' initial work to repository
    [Final Report Status.xlsx]
2014-04-06 fixed again. First time done incorrectly.
    [main.c]
2014-04-06 Added changes to rendering s software for measuring fps, setting resolution, and inverting screen.
    [main.cpp]
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2014-04-13 Changed objinfo structure to add the ability to set an objects 3rd dimensional coordinate. I also fixed the switch statement for sending out packets periodically.
2014-04-14 I have modified enough to make updating object to work from python simulations. I have an example simulation that moves two ghosts positioned in front of the user so he/she doesn't need to go outside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
    [config.txt]
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2014-04-20 Update report and status
    [Final Report Status.xlsx]
2014-04-21 Moved final report to a seperate folder containing all documents for the final submission.
    [Bill Of Materials Appendix.xlsx, Timeline Appendix.xlsx]
2014-04-21 Finish testing section and schematic/theory of operation/PCB section. Reformat to match CCup guideline of calibri 11 pt.
    [Final Report Status.xlsx]
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2014-04-21 Update report status, formatting fix
    [Final Report Status.xlsx]
2014-04-21 Updated bill of materials.
    [Bill Of Materials Appendix.xlsx]
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2014-04-21 added survey appendix
    [Survey Responses.xlsx]
2014-04-21 Fix senior design report appendix to use the right file. Update lens formula to match the others.
2014-04-21 survey response appendix and writeup updated
    [Survey Responses.xlsx]
2014-04-22 Include 2:24 battery life in report
    [Final Report Status.xlsx]
2014-04-24 Power microcontroller successfully enters Zeropower (or close to) state, thanks to turning on pull-up and pull-down resistors.
    Still does not resume USB correctly on wake up.
    [main.c]
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2014-04-26 USB suspend and resume to micropower mode actually works! Current battery voltage is reported as ASCII value, in mV, at 1 Hz.
    There are still small issues with occasional data coming through 2 at a
    time at 0.5 Hz, along with a fluctuating input current drop for 1 s
    suggesting something up with the USB spuriously suspending, instantly
    waking up + resetting, then returning 2 lines when the next printf()
    reports data.
    [main.c]
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2014-04-26 Fixed gui launching. Changed filenames to be sent. Updated sendFile to send to a specific ip.
    [packetLib.h]
2014-04-27 maybe fixed file sending and added the rest of the updateObj code.
    [packetLib.h]
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2014-04-29 changes to simulation and rendering to ensure correct directions.
    [main.cpp]
2014-04-30 Fixed so that gui sends networking code back to a good state on backspace. Also added battery, wifi, and gps stuff.
    [packetLib.h]
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2014-05-01 Changed the origin in the pacman simulation.
    [config.txt]
2014-05-02 Fix magnetometer gains. Add another I2C timeout.
    [i2c.c, imu.c, main.c]
2014-05-02 Hard-iron correction for magnetometer implemented
    [imu.c, main.c]
2014-06-06 The config file has been updated to allow for better configuration. Previously the amount of configuration was limited and required one to create their own script or program to meet our standards. No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
    [main.cpp]
2014-06-10 Added an API call for translating GPS coordinates into x,y coordinates. This will make it easier/possible to write an application driven by GPS based coordinates. Simply translate your GPS coordinate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
2014-06-16 fixed socket problem. Used incorrect file descriptor...
2014-07-11 Add the Labview VIs developed for IMU hard iron correction

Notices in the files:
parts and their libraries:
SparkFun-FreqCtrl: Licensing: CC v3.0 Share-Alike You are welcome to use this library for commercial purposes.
